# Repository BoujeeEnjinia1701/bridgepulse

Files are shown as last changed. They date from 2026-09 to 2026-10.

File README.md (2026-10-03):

# BridgePulse

     

**Area:** Smart Cities · **TRL:** 3 of 9 (proof of concept on paper) · **Value-engineering target:** $250 USD for the BridgePulse-specific parts (a hypothetical control target, not a limit) · **Difficulty:** 3 of 5

A vibration and strain monitor for small bridges and footbridges that tracks natural frequency and strain over time to flag changes that need inspection.

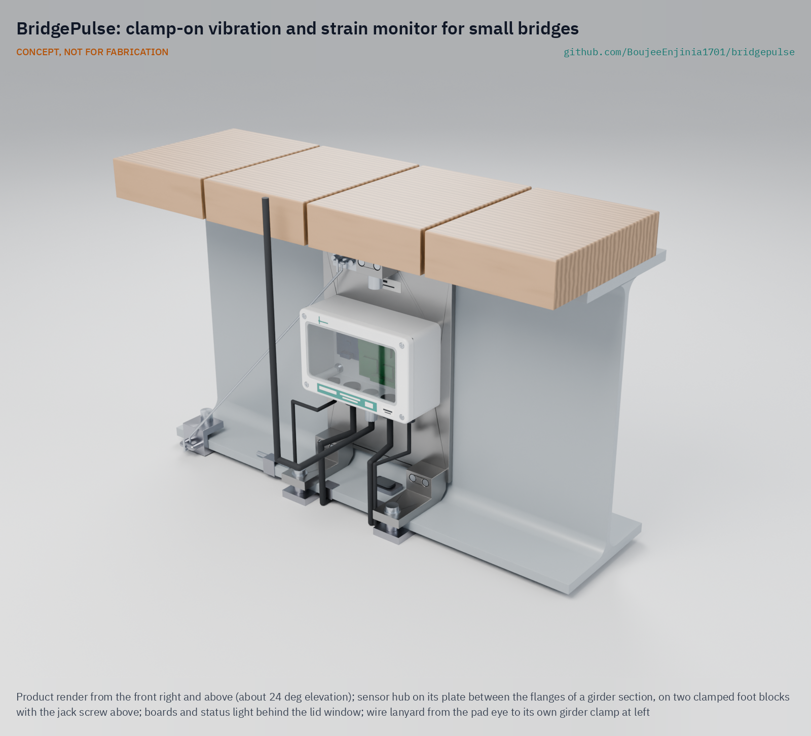
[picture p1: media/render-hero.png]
BridgePulse: clamp-on vibration and strain monitor for small bridges, product render


[Exploded render](media/render-exploded.png) · [Detail render](media/render-detail.png) · [Interactive 3D model](media/viewer.html) · [Concept blueprint (PDF)](media/concept-blueprint.pdf) · [General arrangement BRP-DWG-001 (PDF)](cad/drawings/BRP-DWG-001.pdf) · [Calculations BRP-CAL-001](docs/04-calcs/01-sizing.md) · [Prototype build plan BRP-BLD-001](docs/05-build-plan.md) · [Design decisions BRP-DEC-001](docs/06-design-decisions.md) · [Review note](docs/REVIEW.md)

## Concept rationale

A bridge's natural frequencies depend on its stiffness, so a loss of stiffness from corrosion, cracking or a failing bearing shows up as a small, lasting drop in frequency, and a change in how load is carried shows up in strain. The difficulty is that temperature moves the frequencies too. The Z24 bridge study showed that a model of frequency against temperature, learned from the healthy bridge, can separate the two ([Peeters and De Roeck, 2001](https://doi.org/10.1002/1096-9845%28200102%2930:2%3C149::AID-EQE1%3E3.0.CO;2-Z)). BridgePulse applies that idea with one clamp-on sensor hub at midspan, hourly 10 minute records and a learned temperature band, so the owner's engineer gets a reason to inspect sooner rather than a stream of raw data.

It is open and garage-buildable because the owners of small bridges, such as towns, counties, park services and rural access programs, are the ones least able to pay for commercial monitoring. Low-noise MEMS accelerometers now cost tens of dollars, the hub clamps on without drilling, and power, radio and data handling come from the lab's shared FieldNode, TwinKit and CityTwin projects. Open design files and open methods also let engineers check how a flag was raised, which matters more than the hardware.

## Burning platform

Bridge stock is large, aging and inspected at long intervals. In the United States, 41,685 of 624,193 bridges (6.7 %) were in poor condition in 2025 ([FHWA](https://www.fhwa.dot.gov/bridge/nbi/no10/condition25.cfm)), and routine inspections may be 24, 48 or, under a risk-based method, up to 72 months apart ([23 CFR 650.311](https://www.ecfr.gov/current/title-23/chapter-I/subchapter-G/part-650/subpart-C/section-650.311)). In Japan, about 37 % of roughly 730,000 road bridges were 50 years old or more in 2023, rising to about 54 % by 2030 ([MLIT](https://www.mlit.go.jp/sogoseisaku/maintenance/02research/02_01.html)).

Findings also have to reach someone who acts. The Fern Hollow Bridge in Pittsburgh collapsed in January 2022 after the city failed to act on repeated maintenance recommendations in its inspection reports ([NTSB](https://www.ntsb.gov/investigations/Pages/HWY22MH003.aspx)). A monitor cannot replace inspection or funding, but a clear, early signal on a specific bridge can help put limited inspection time where it is needed.

## Where it could be used

### By industry

| Industry | Use |
| --- | --- |
| Municipal and county public works | Watching footbridges and short road bridges between routine inspections, and after floods or vehicle strikes |
| Parks, trails and recreation | Timber and steel trail bridges that see few inspections and many visitors |
| Rural access and humanitarian programs | Checking a sample of trail bridges built years earlier without a site visit to each one |
| Rail and transit operators | Station footbridges and pedestrian overbridges |
| Forestry and mining | Haul road and forestry bridges carrying heavy, irregular loads |
| Universities and training | An open platform for teaching and research in vibration-based structural health monitoring |

### By country or region

| Country or region | Why it matters there |
| --- | --- |
| United States | 41,685 bridges were rated poor in 2025 ([FHWA](https://www.fhwa.dot.gov/bridge/nbi/no10/condition25.cfm)); many are small, locally owned structures. |
| Great Britain | 2,928 council-maintained road bridges were substandard in 2023, with a £6.8 billion backlog; councils also report growing concern about flooding and scour ([RAC Foundation](https://www.racfoundation.org/media-centre/changing-weather-patterns-worrying-bridge-engineer)). |
| Japan | The share of road bridges 50 years old or more is set to rise from about 37 % to about 54 % between 2023 and 2030 ([MLIT](https://www.mlit.go.jp/sogoseisaku/maintenance/02research/02_01.html)). |
| Nicaragua and Central America | Floods cut labor income by about 18 % in villages without a footbridge, and new bridges removed that loss ([Brooks and Donovan, 2020](https://doi.org/10.3982/ECTA15828)); keeping existing footbridges in service protects that gain. |
| Rwanda and East Africa | Trail bridge programs report a preliminary annual return of about 49 % on trail bridges in Rwanda and similar settings ([Fika, formerly Bridges to Prosperity](https://fika.org/measuring-roi-for-trail-bridges/)), so a growing stock of footbridges will need low-cost ways to check them. |

## What sparked the idea

The idea traces back to the Silver Bridge between Point Pleasant, West Virginia, and Ohio, which fell on December 15, 1967, killing 46 people, after a single eyebar in a suspension chain fractured from a defect only 2.5 mm (0.1 in) deep. The disaster led to the National Bridge Inspection Standards of April 27, 1971, which set inspections at least once every two years by trained inspectors ([FHWA](https://highways.dot.gov/highway-history/general-highway-history/happy-50th-anniversary-national-bridge-inspection-standards)). That calendar-based regime is still the backbone of bridge safety, but it leaves long gaps in which nobody watches a structure, and it is weakest for the small footbridges and local spans that get the least attention. BridgePulse starts from that gap: a low-cost record of how a small bridge behaves between inspections, fed to the owner's engineer and to CityTwin, so that a change can prompt a visit sooner than the calendar would.

## Problem

Many small bridges are inspected rarely, and deterioration is found late. Their owners seldom have the budget for commercial monitoring, so there is no record of how a bridge behaves between inspections. See the [problem statement](docs/01-problem.md).

## Concept

A vibration and strain monitor for small bridges and footbridges that tracks natural frequency and strain over time to flag changes that need inspection. A sensor hub fixed between the flanges of a girder at midspan records 10 minutes of acceleration, strain and temperature every hour, extracts the natural frequencies and strain statistics on board, and sends about 36 bytes per hour (11 bytes where the radio data rate allows no more) through a FieldNode core over LoRaWAN to TwinKit or CityTwin. A temperature-compensated baseline, learned over weeks, flags lasting changes to the owner's engineer.

The TRL 3 calculations ([BRP-CAL-001](docs/04-calcs/01-sizing.md)) give 16.9 mW average draw, 0.0153 Hz spectral resolution per record, 1.39 GB of raw records per month kept on site, and $275 of BridgePulse-specific parts ($401 with the FieldNode core, which is costed in its own repo), $25 over the $250 value-engineering target since the parts that make the design buildable, the lanyard anchor and the installation banding were added. With the lanyard's girder clamp the monitor puts 3.58 kg on the girder. On the 7 m example footbridge the first mode is 23.9 Hz and the instrument can track it to about 0.05 % an hour, but the mass of people crossing lowers it by up to 6 %. The hub therefore gates out the time when someone is on the span; in simulation that brings the hourly scatter to 0.015 % or less, inside the 0.2 % target, which remains at risk until recorded data confirm it. The 1 % change detection cannot be verified on paper. See the [requirements](docs/03-requirements.md) for what is and is not met.

Full design precis: [docs/02-concept.md](docs/02-concept.md)

## Key components

- Sensor hub: IP67 die-cast aluminium enclosure on an aluminium plate that lies on the girder web, clamped to the bottom flange and jacked against the top flange, no drilling
- Low-noise 3-axis MEMS accelerometer (ADXL355 class)
- Signal board with 24-bit bridge ADC, RP2040 class microcontroller, RS-485 link and industrial microSD card
- Two strain gauge half-bridges with temperature-compensating dummy gauges
- Two TMP1826 class temperature probes in stainless sheaths (steel and air)
- Shielded sensor cables with M12 connectors
- FieldNode core (shared lab component): 6 W panel, LiFePO4 cell, MPPT charger and LoRaWAN radio

The working bill of materials is in [bom/bom.csv](bom/bom.csv).

## Building the prototype

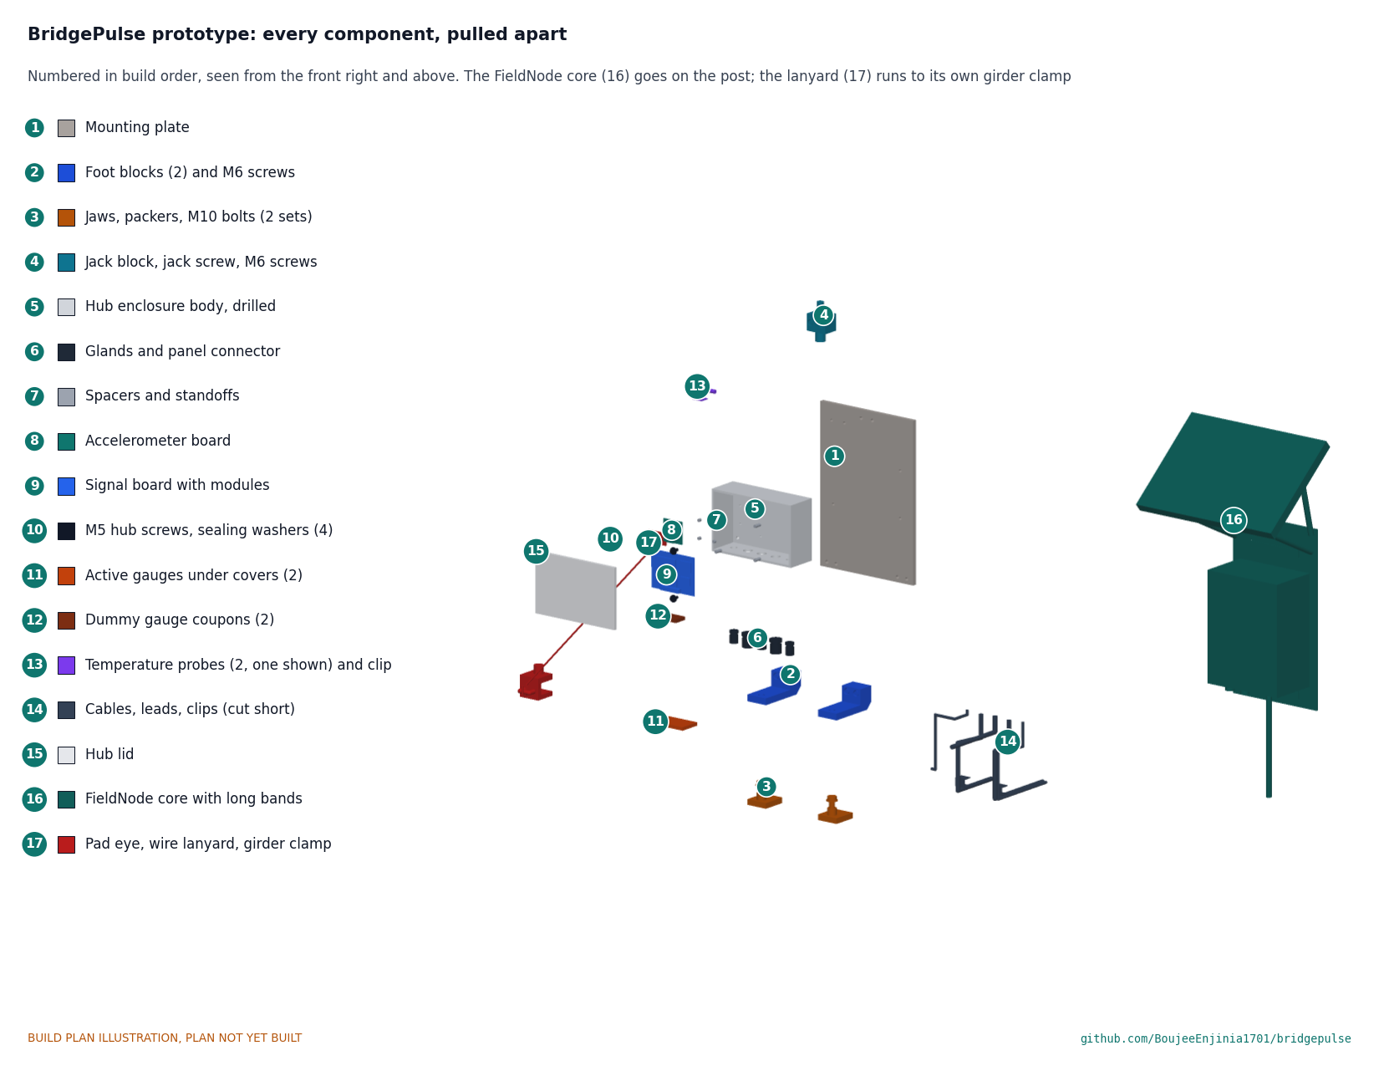
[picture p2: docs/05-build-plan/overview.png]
BridgePulse prototype: every component, pulled apart and numbered in build order


The [prototype build plan](docs/05-build-plan.md) (BRP-BLD-001) shows, component by component and step by step in pictures drawn from the model, how to build the first proof-of-concept monitor on a bench rig of two girder offcuts and a handrail post stub. Seven parts are made in a small workshop from aluminium and steel bar and plate; the rest are bought, and the FieldNode core is built to its own plan. Making the design buildable kept the plate clear of the girder's root fillets, clamped it to the flange with foot blocks and steel jaws, and gave every sensor and cable a fixing that needs no drilling (BRP-DDR-004). A stainless wire lanyard runs from a pad eye on the plate to a second, independent girder clamp on the bottom flange. It is a plan, not yet built; the decisions behind it are in the [design decisions register](docs/06-design-decisions.md).

## Safety

> A research prototype; it supports but never replaces inspection by qualified engineers, and a "no change" result never means a bridge is safe. Install only with the asset owner's permission, by trained crews, with fall protection, a rescue plan for work over water and traffic management as local rules require. Test old paint for lead before removing any for strain gauges. The FieldNode core contains a lithium iron phosphate cell; use its protected, fused pack. Nothing is drilled or welded into the structure, and the mounting plate carries a secondary wire lanyard to an independent girder clamp.

## Repository layout

| Folder | Contents |
| --- | --- |
| `docs/` | Problem, concept, requirements, calculations and design decisions |
| `cad/src/` | build123d Python source, the source of truth for all geometry |
| `cad/step/`, `cad/stl/` | Exported models for FreeCAD, other CAD tools and printing |
| `cad/drawings/` | 2D sketches and dimensioned drawings |
| `bom/` | Bill of materials |
| `electronics/` | KiCad schematics and PCB layouts |
| `firmware/` | Microcontroller code |
| `media/` | Renders, perspectives and photos |
| `build-log/` | Dated prototyping notes |

## Documentation

Controlled documents follow the portfolio [documentation standard](.kit/STANDARDS.md). Each carries a document ID (BRP-PRC-001 for the precis), a version and a revision history. Branded PDFs are built with `python .kit/render.py` and attached to GitHub Releases when a document is tagged, for example `BRP-PRC-001/v1.0`.

## Credits

Designed by Amish Chadha. See [CONTRIBUTORS.md](CONTRIBUTORS.md) for roles. To cite this design, use [CITATION.cff](CITATION.cff) (GitHub shows it as "Cite this repository").

AI assistance (Claude) was used to accelerate concept renders, prototype documentation and first-pass sizing calculations. Design direction and all decisions are Amish Chadha's, recorded in this repository's decision records (`docs/decisions/`).

## Licenses

- **Hardware** (CAD, drawings, BOM, electronics): [CERN-OHL-S v2](LICENSE)
- **Software** (firmware, scripts, notebooks): [MIT](LICENSE-SOFTWARE)

A project of the [Design Molecule](https://designmolecule.com) lab.

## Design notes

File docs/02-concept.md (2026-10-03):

---
doc_id: BRP-PRC-001
title: BridgePulse design precis
project: BridgePulse
doc_type: Design precis
version: "0.8"
status: Draft
date: '2026-10-02'
author: Amish Chadha
license: CERN-OHL-S-2.0
revisions:
- version: "0.1"
  date: '2026-09-25'
  author: Amish Chadha
  change: Initial scaffold
- version: "0.2"
  date: '2026-09-25'
  author: Amish Chadha
  change: Concept for TRL 2; architecture, first-order numbers, safety and open questions
- version: "0.3"
  date: '2026-09-25'
  author: Amish Chadha
  change: TRL 3 update; design choices adopted for TRL 3 per BRP-DDR-001; numbers from BRP-CAL-001; jacked mounting plate, switched-rail power, curve-fit frequency estimate, mass-loading finding
- version: "0.4"
  date: '2026-09-25'
  author: Amish Chadha
  change: Recommendations accepted by Amish (DDR-002); load gating and TwinKit load regression, 11-byte reduced summary, TMP1826 class probes; numbers from BRP-CAL-001 v0.2
- version: "0.5"
  date: '2026-09-30'
  author: Amish Chadha
  change: Design made constructable (BRP-DDR-004); mounting, hub penetrations, probe fixing and FieldNode post interface described as buildable; numbers from BRP-CAL-001 v0.3
- version: "0.6"
  date: '2026-10-01'
  author: Amish Chadha
  change: Budget treated as a value-engineering target; cost wording only, no number changed
- version: "0.7"
  date: '2026-10-02'
  author: Amish Chadha
  change: "Decisions of 2026-10-02 carried in: shared FieldNode pinout with Modbus RTU, lanyard to an independent girder clamp, crimped banding on installed units, data ownership"
- version: "0.8"
  date: '2026-10-02'
  author: Amish Chadha
  change: "Approved follow-ups carried out: lanyard pad eye, wire and girder clamp in the model and the BOM, installation banding priced; mass 3.58 kg on the girder and cost $275.00 from BRP-CAL-001 v0.6"
---

# BridgePulse design precis

## Summary

BridgePulse is a clamp-on monitor for small bridges and footbridges. A sensor hub fixed to a girder at midspan records ambient vibration, strain and temperature for 10 minutes every hour, works out the bridge's natural frequencies and strain statistics on board, and sends a short summary through a FieldNode core over LoRaWAN to TwinKit or CityTwin. Over weeks the system learns how the frequencies move with temperature; a sustained shift outside that band is flagged to the bridge owner's engineer as a reason to inspect sooner. It is a research prototype that supports inspection, never a safety rating.

The TRL 3 calculations (BRP-CAL-001) give 16.9 mW average draw at the FieldNode port, a 36-byte hourly uplink, 1.39 GB per month of raw records kept on a microSD card (22 months on 32 GB), and $275 of BridgePulse-specific parts ($401 with the FieldNode core), $25 over the $250 value-engineering target since the parts that make the design buildable, the lanyard anchor and the installation banding were added (see the value engineering section of BRP-DEC-001). On the 7 m example footbridge the first mode is 23.9 Hz and the instrument can track it to 0.05 % an hour, but walkers' own mass lowers it by up to 6 % while they cross. The hub therefore gates out the time when someone is on the span; in simulation this brings the hourly scatter to 0.015 % or less (R2 at risk until recorded data confirm it; R3 not verifiable at TRL 3).

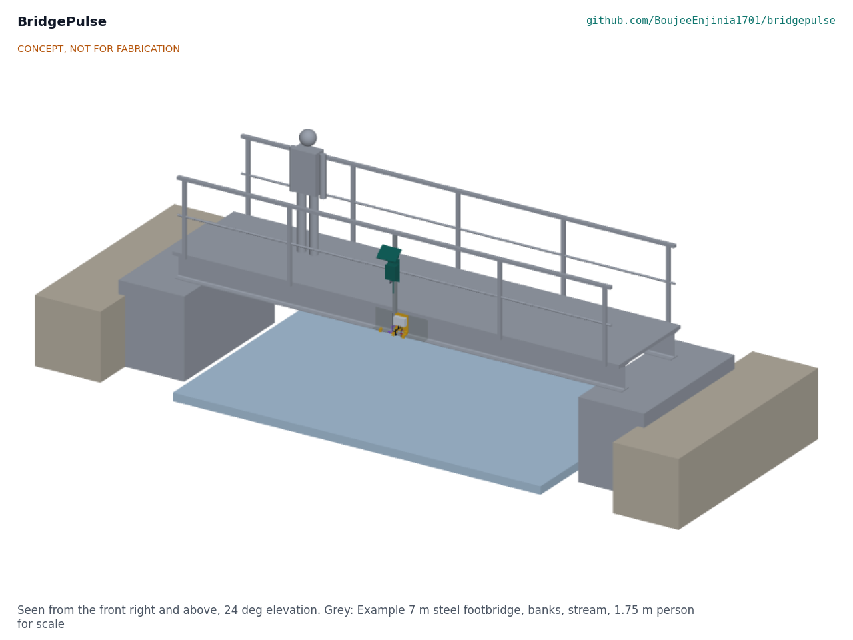
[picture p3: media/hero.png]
Figure 1. BridgePulse on an example 7 m steel footbridge


*Figure 1. Concept render. The monitor clusters at midspan: sensor hub between the flanges of the south girder, FieldNode core on the handrail post. Grey parts are the existing bridge and a 1.75 m person for scale.*

## How it works

1. **Sense.** A low-noise 3-axis MEMS accelerometer, fixed inside the hub to the enclosure base, picks up the bridge's response to wind, footfall and traffic. The hub is screwed to an aluminium plate that lies against the web, stands on two foot blocks clamped to the bottom flange and is wedged against the top flange by a jack screw, so that its own mounting resonance (135 to 271 Hz) is well above the measured band. A stainless wire lanyard from a pad eye on the plate to a second, independent girder clamp on the bottom flange holds everything if the mount ever lets go. Two strain gauge half-bridges under the bottom flanges of both girders at midspan measure bending strain. Two temperature probes measure the steel and the shaded air under the deck.
2. **Record.** Once an hour the FieldNode core switches on the 5 V rail of its sensor port. The hub boots, warms the gauges for 20 s and samples for 600 s: acceleration at 250 Hz on three axes, strain at 20 Hz on two channels, temperature once a minute. The raw record goes to an industrial microSD card so an engineer can download it later.
3. **Reduce.** The hub first finds each crossing from the strain step and gates out that stretch of the record, with 0.25 s either side and tapered edges, so that the frequency is estimated only while nobody's mass is on the span (BRP-DDR-002). It then reads the record back from the card one axis at a time, computes averaged spectra (Welch method, 65.5 s Hann segments with 50 % overlap), and estimates the frequencies of the first modes below 60 Hz by fitting a single-degree-of-freedom spectrum around each peak. A fit is accepted only if the peak stands 10 dB above the fitted noise and the damping is plausible; otherwise the hour is sent as "no clear peak", never as a shift. It also computes peak amplitudes, RMS acceleration, and the strain minimum, maximum and mean on each channel.
4. **Send.** The 36-byte summary passes over RS-485 on the M12 cable to the FieldNode core, which sends it as one LoRaWAN uplink; the rail is then switched off until the next hour. Where the data rate in use allows only 11 bytes (US915 DR0, AS923 DR2 with dwell time), the hub sends an 11-byte reduced summary instead: first frequency, its amplitude, the two strain means, steel temperature and a status byte with the gated seconds (BRP-CAL-001, G).
5. **Learn and flag.** TwinKit stores the series and fits frequency against steel temperature over a baseline period, following the approach of the Z24 bridge study ([Peeters and De Roeck, 2001](https://doi.org/10.1002/1096-9845%28200102%2930:2%3C149::AID-EQE1%3E3.0.CO;2-Z)). A frequency that stays outside the confidence band for a set period, or a step in the strain baseline, raises a flag to the owner's engineer. As a second line against any load effect the gate misses, TwinKit also regresses each hourly frequency on a load indicator (strain mean, RMS acceleration) sent in the summary. TwinKit can show the measured frequency next to the value calculated from the bridge model.
6. **Act.** The engineer decides whether to inspect. The public CityTwin view shows only that the bridge is monitored and when data last arrived.

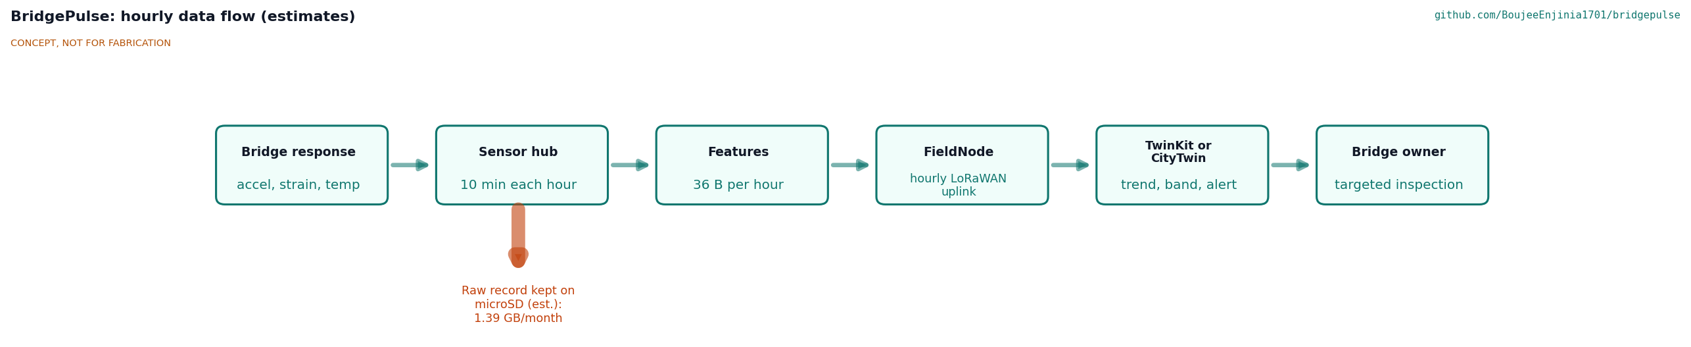
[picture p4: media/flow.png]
Figure 2. Hourly data flow


*Figure 2. Hourly data flow. Values are estimates from BRP-CAL-001.*

## Main components

Numbers match the exploded view (Figure 3) and `bom/bom.csv`. The general arrangement is drawing BRP-DWG-001.

| No. | Component | Role |
| --- | --- | --- |
| 1 | Sensor hub enclosure, die-cast aluminium, IP67, 170 × 64 × 110 mm | Stiff, sealed housing whose base is screwed flat to the plate, coupling the accelerometer to it; two M16 gauge glands, two M12 probe glands and an M12 panel connector underneath |
| 2 | Accelerometer board, ADXL355 class | 3-axis, 22.5 µg/√Hz noise density, 200 µA in measurement mode ([Analog Devices](https://www.analog.com/en/products/adxl355.html)) |
| 3 | Signal board: 24-bit bridge ADC (ADS1220 class), RP2040 class microcontroller, 5 V to 3.3 V buck converter, RS-485 transceiver, microSD socket, gauge excitation switch | Sampling, spectra, features, raw storage, link to FieldNode |
| 4 | Mounting plate, 200 × 291 × 8 mm 6061 aluminium, on two foot blocks clamped to the bottom flange tip by steel jaws, with an M12 jack screw to the top flange | Holds the hub between the flanges, inside the girder outline, clear of the root fillets; no drilling |
| 5 | Strain gauge half-bridges (2): each an active 350 Ω foil gauge on the flange plus a dummy gauge on an unstrained coupon of the same steel, with protective coating and cover | Bending strain at midspan of each girder, temperature-compensated |
| 6 | Temperature probes (2), TMP1826 class 1-Wire sensor potted in a stainless sheath, ±0.3 °C from −40 to +105 °C ([Texas Instruments](https://www.ti.com/product/TMP1826)) | Steel and shaded air temperature for frequency compensation |
| 7 | Sensor cables and M12 connectors | Gauges to hub, hub to FieldNode |
| 8 | FieldNode core: IP65 enclosure, 6 W panel as sun hood, LiFePO4 cell, MPPT charger, LoRaWAN radio, pole clamps | Power, radio and mounting shared across the lab's outdoor projects |
| 9 | microSD card, industrial grade, 32 GB | Raw records on site (in item 3; not shown separately) |

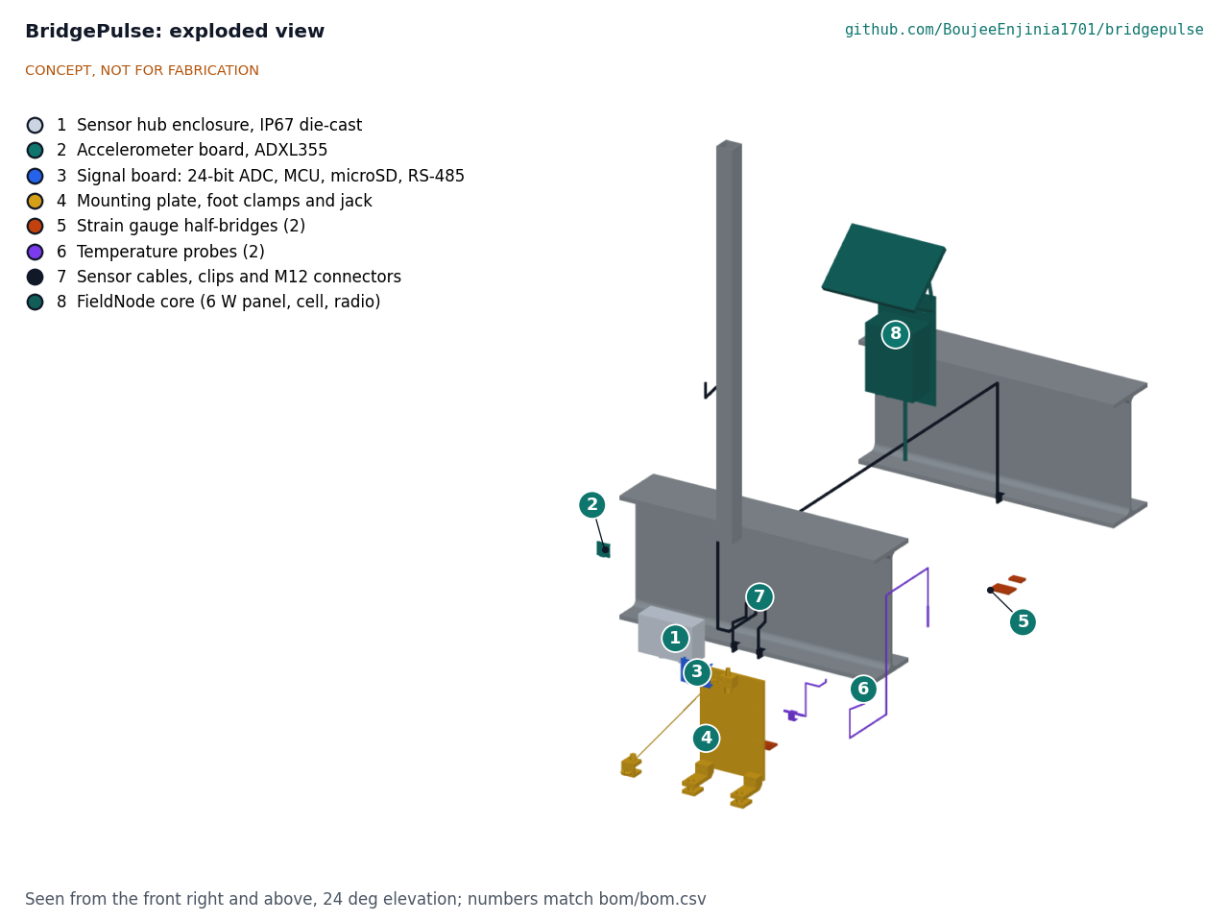
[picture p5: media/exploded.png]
Figure 3. Exploded view


*Figure 3. Exploded view with BOM numbers. The girder and post are existing structure.*

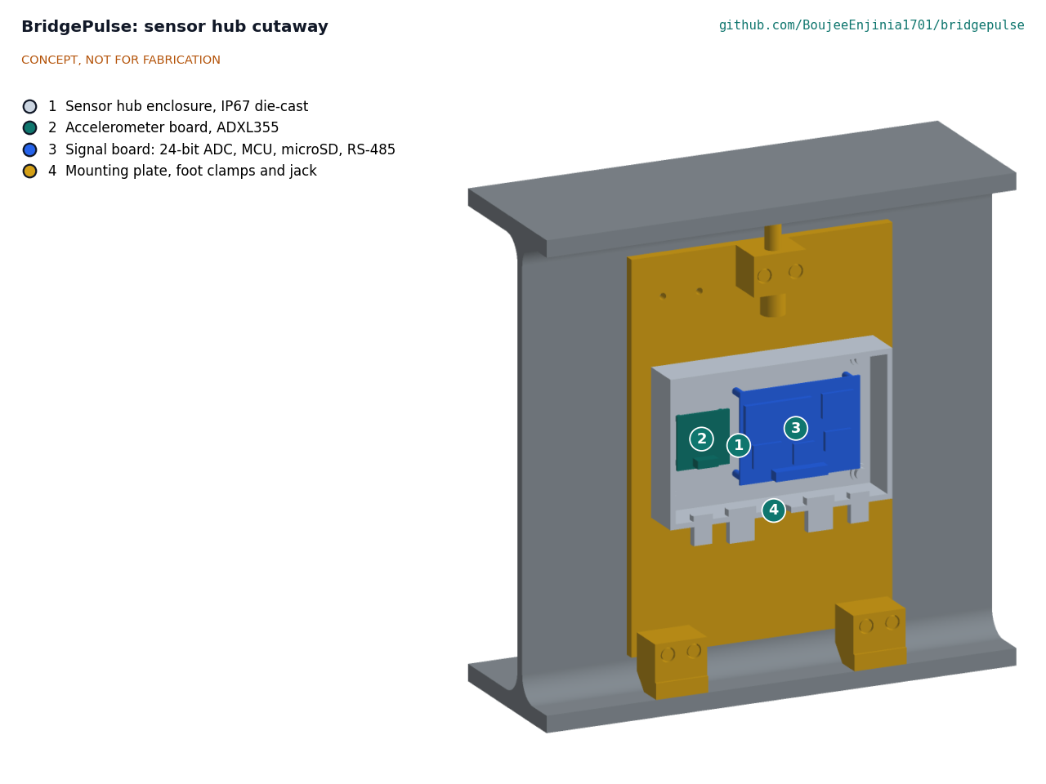
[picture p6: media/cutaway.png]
Figure 4. Sensor hub cutaway


*Figure 4. Cutaway of the sensor hub on its plate, between the flanges of the south girder. The accelerometer board is fixed to the base of the enclosure on the plate side so it moves with the girder.*

## Key numbers (BRP-CAL-001)

All values come from BRP-CAL-001 v0.3, which states its assumptions; they are calculations, not measurements.

### Example bridge

- 6.4 m between bearings; two IPE 360 class girders; EI = 6.52 × 10⁷ N·m²; 167 kg/m. First vertical mode **23.9 Hz**, second 96 Hz (outside the band); modal mass 535 kg.
- A lasting 1 % drop in frequency is a 2 % loss of bending stiffness. The steel modulus alone moves the frequency by about 1 % between −20 and +50 °C, so temperature compensation is needed.
- **People change the frequency of a light footbridge.** One 75 kg walker at midspan lowers f₁ by 6.3 %; a crowd of one person per square meter lowers it by 22.7 %. On a road bridge with 20 t of modal mass one walker moves it by 0.19 %.

### Measurement

- Bin width 0.0153 Hz; 17 averaged segments per record; sensor noise 2.8 µg in one bin. The mode's 0.48 Hz half-power bandwidth, not the bin width, limits precision.
- Simulated scatter of the hourly estimate from sensor noise: 0.053 % at 100 µg RMS of modal response with a curve fit, against 0.265 % with simple peak picking; a clear peak needs about 30 µg RMS. One walker gives about 29 mg RMS near midspan, so footfall is ample excitation.
- Because the walkers who excite the bridge also load it, an estimate over the whole record is biased by about −5 % and scatters by 1.5 to 3.1 % in a time-varying simulation. With load gating the bias is −0.03 to −0.04 % and the scatter 0.015 % or less (1 to 20 crossings in the record), inside R2's 0.2 %; 4.4 % of the record is gated out at 5 crossings. With one crossing on a quiet day, 20 % of records give no clear peak.
- Detecting a 1 % shift within 14 days with one false flag per year needs a daily residual of 0.75 % or less after temperature and load compensation.
- Strain: 1.65 µV per µε; 0.09 µε RMS resolution at the assumed ADC noise; a 5 kN/m² crowd gives 106 µε and one walker 3.2 µε, so strain is a usable load indicator.

### Power, data and mounting

| Quantity | Value |
| --- | --- |
| Power while recording, at the FieldNode port | 92.9 mW |
| Average, with the rail off between records | **16.9 mW** (0.41 Wh per day; 17 % of FieldNode's 100 mW allowance) |
| Raw data | 1.90 MB per hour; 1.39 GB per month; 22 months on 32 GB |
| Uplink | 36 bytes hourly, 329 ms at SF9; 11-byte reduced summary where the data rate allows only 11 bytes, 371 ms at SF10 |
| Mass on the girder | 3.58 kg (hub 0.99 kg, plate 1.25 kg, foot clamps, jack and fixings 0.97 kg, lanyard girder clamp, pad eye and wire 0.37 kg); FieldNode core 2.41 kg |
| Mounting resonance of the hub | 135 to 271 Hz (TRL 2 arrangement about 75 Hz) |
| Lanyard | Peak 1.20 kN if the mount lets go with 25 mm of slack (dynamic factor 38); girder clamp rated 100 kg or more working load |
| Depth below the soffit | 10 mm at most (limit 15 mm) |

### Cost

Value-engineering target $250 (a hypothetical control target, not a limit), which under BRP-DDR-001 D1 covers the BridgePulse-specific parts. Estimated cost of the constructable design: $275.00 ($25.00 over the target); with the FieldNode core ($126.00, costed in its own repo) the complete monitor is $401.00. The TMP1826 class probes added $4.00, the parts that make the design buildable (BRP-DDR-004) $4.00, the lanyard anchor decided on 2026-10-02 $19.00 and the stainless banding for installed units $4.00. Savings worth trying are listed in the value engineering section of the design decisions register (BRP-DEC-001). The bridge, installation labor, access equipment, traffic management and paint testing are not included.

## Key design choices

Each is decided by Amish, 2026-09-25: go with recommendation (BRP-DDR-001, BRP-DDR-002).

1. **Ambient vibration only.** No shaker or impact hammer; wind, footfall and traffic excite the bridge. Footfall is ample on a used footbridge; very quiet bridges remain a risk.
2. **Separate hub on the girder, FieldNode on a post.** The accelerometer must be on the structure, while the panel needs sun and the radio a clear view.
3. **Hourly 10 minute windows rather than continuous recording.** 16.9 mW against about 93 mW, with 24 frequency estimates a day.
4. **Temperature-compensated trend, not fixed limits.** A frequency band learned from the bridge's own baseline, with at least four weeks of data before any flag and a full year to cover seasons. BRP-CAL-001 shows it must model load on the deck as well as temperature.
5. **Foil gauge half-bridges with a dummy on a coupon.** Cheaper and easier to fit than weldable or vibrating-wire gauges, at the cost of long-term drift, to be checked early.
6. **One accelerometer at midspan.** Enough for the first vertical and torsional modes.
7. **Built on FieldNode, TwinKit and CityTwin.** The hub connects to one FieldNode M12 5-pin port, using its switched rail at 5 V and RS-485 on two signal pins. This follows FieldNode's candidate pinout, adopted on 2026-10-02 as the shared standard with Modbus RTU as the protocol (pin 1 switched 5 V rail, pins 2 and 4 RS-485 A and B, pin 3 ground, pin 5 analog); FieldNode is asked to record it as decided (BRP-DEC-001).
8. **Engineer-only alerts.** Flags go to the owner's engineer; the public CityTwin view shows only monitoring status.
9. **An RP2040 class microcontroller in the hub,** which post-processes each record from the card because the three axes do not fit in its RAM at once.
10. **Load gating, backed by a load regression.** The hub gates out the time when people are on the span; TwinKit regresses what remains on a load indicator. R2 stays at 0.2 % until recorded data show whether this works (BRP-DDR-002).
11. **An 11-byte reduced summary** wherever the data rate in use limits the payload to 11 bytes (BRP-DDR-002).
12. **TMP1826 class probes with an ice-point check,** so the ±0.5 °C of R5 holds down to −20 °C (BRP-DDR-002).

## Safety

> **Safety:** BridgePulse is a research prototype. It supports but never replaces inspection by qualified engineers, and a "no change" result never means a bridge is safe. Owners must not defer or skip inspections because a monitor is fitted.

> **Safety:** Installation is work at height, often over water or traffic. Install only with the owner's written permission, with trained crews, fall protection, a rescue plan for work over water, and traffic management as local rules require. Never work alone.

> **Safety:** Old steel bridges may be coated with lead or other hazardous paint. Test before removing any paint for strain gauges; if lead is present, use a trained contractor and local abatement rules. Gauge adhesives and coatings are chemicals: follow their safety data sheets, use gloves and eye protection and ventilate.

> **Safety:** The FieldNode core contains a lithium iron phosphate cell. Use the fused, protected pack and cold-charge lockout specified by FieldNode and never mount a damaged pack.

> **Safety:** Nothing may be drilled, welded or cut into the structure. The jack screw preload and the clamps must be checked so they cannot loosen and fall onto people, vehicles or boats below; use a secondary 3 mm stainless wire lanyard from the pad eye on the plate to a second, independent load-rated girder clamp on the bottom flange, at least 150 mm along the span from the foot clamps, fitted with no more than 25 mm of slack. Isolate the aluminium plate from the steel so galvanic corrosion cannot loosen it over time.

> **Safety:** Fit tamper-resistant fasteners on the post-mounted FieldNode so the public cannot pull it off or hang from it: stainless banding with a one-way crimped buckle on installed units (worm-drive bands only on the bench). Keep cables out of reach from the deck.

## Open questions

- [ ] 1. Does load gating hold on recorded footfall, with real walkers, several modes and wind, as it does in simulation? (BRP-CAL-001, B; TRL 4, on hold)
- [ ] 2. How much do frequencies move with temperature on small steel, concrete and timber bridges, and can a model trained on four weeks of data hold across seasons to a daily residual of 0.75 %?
- [ ] 3. What drift do foil strain gauges show outdoors over a year with the proposed coating?
- [x] 4. Which FieldNode port pinout and protocol will be agreed (BRP-DDR-001, O1)? Decided 2026-10-02: FieldNode's candidate pinout with Modbus RTU over RS-485, as the shared standard.
- [ ] 5. What is the alert rule (size of shift, duration) and who receives it?
- [ ] 6. Does the potted TMP1826 class probe hold its datasheet accuracy after sealing, at the ice point and in CalRig? (TRL 4, on hold)
- [x] 7. Who owns the data, and what is published openly through CityTwin (BRP-DDR-001, O3)? Decided 2026-10-02: the bridge owner owns all data; only monitoring status is published, and research datasets only with the owner's written consent, under an open licence such as CC BY 4.0.

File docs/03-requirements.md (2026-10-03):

---
doc_id: BRP-REQ-001
title: BridgePulse requirements
project: BridgePulse
doc_type: Requirements
version: "0.8"
status: Draft
date: '2026-10-02'
author: Amish Chadha
license: CERN-OHL-S-2.0
revisions:
- version: "0.1"
  date: '2026-09-25'
  author: Amish Chadha
  change: Initial scaffold
- version: "0.2"
  date: '2026-09-25'
  author: Amish Chadha
  change: First measurable requirements for TRL 2, with status against the concept estimates
- version: "0.3"
  date: '2026-09-25'
  author: Amish Chadha
  change: R12 redefined per BRP-DDR-001 D1; status of every requirement from BRP-CAL-001; interface assumptions for FieldNode
- version: "0.4"
  date: '2026-09-25'
  author: Amish Chadha
  change: Recommendations accepted by Amish (DDR-002); R2 method (load gating), R5 verification, R7 restated with an 11-byte reduced summary; status from BRP-CAL-001 v0.2
- version: "0.5"
  date: '2026-09-30'
  author: Amish Chadha
  change: Status from BRP-CAL-001 v0.3 after the design for construction (BRP-DDR-004); R12 now not met by $2.00; no target changed
- version: "0.6"
  date: '2026-10-01'
  author: Amish Chadha
  change: Budget treated as a value-engineering target; R12 status reworded, no number changed
- version: "0.7"
  date: '2026-10-02'
  author: Amish Chadha
  change: "R9 states the tamper-resistant fixing chosen on 2026-10-02 (crimped stainless banding); FieldNode pinout recorded as decided; no status changed"
- version: "0.8"
  date: '2026-10-02'
  author: Amish Chadha
  change: "Status from BRP-CAL-001 v0.6 after the approved decisions were carried into the design: R12 now $25.00 over the value-engineering target (lanyard anchor and installation banding); R9 still met on paper; no target changed"
---

# BridgePulse requirements

These are first-pass requirements for the concept. Targets are proposals for review, not yet validated with bridge owners or inspectors, and will be revised after co-design sessions (see BRP-PRB-001). Status is now judged by calculation in BRP-CAL-001 against the parametric model and the priced BOM; "met on paper" is not a verification by test.

**Reference installation.** A steel or concrete footbridge or short-span road bridge of 5 to 30 m span, monitored at midspan, in a climate from −20 to +50 °C, with LoRaWAN coverage and no mains power. The worked example is the 7 m steel footbridge in BRP-PRC-001.

**Changes in v0.3.** R12 is redefined to cost the BridgePulse-specific parts, with the FieldNode core costed in its own repo and the complete cost stated beside it (BRP-DDR-001, D1; decided by Amish, 2026-09-25: go with recommendation). No other target changes.

**Changes in v0.5 (BRP-DDR-004).** No target changes. With the design made buildable, BRP-CAL-001 v0.3 finds R12 over the value-engineering target by $2.00; R9 stays met on paper (10 mm below the soffit, the bolts now ending inside the clamp jaws).

**Changes in v0.8 (decisions of 2026-10-02 carried into the design).** No target changes. The lanyard's independent girder clamp, pad eye and wire and the stainless banding for installed units are now in the model and the BOM. BRP-CAL-001 v0.6 finds R12 over the value-engineering target by $25.00 (was $2.00); R9 stays met on paper, the girder clamp's lower jaw being 8 mm below the soffit.

**Changes in v0.4 (BRP-DDR-002).** R2 keeps its target; its method now gates out the time when people are on the span, backed by a load regression in TwinKit, and is to be checked on recorded data before any change to the target. R5 keeps its target; verification adds an ice-point check, and the probe is now TMP1826 class. R7 is restated so that an 11-byte reduced summary is used wherever the data rate in use limits the payload to 11 bytes. Statuses follow BRP-CAL-001 v0.2.

Table 1. Requirements and status at TRL 3 (BRP-CAL-001 v0.6, Table 5).

| ID | Requirement | Target | Verification | Status at TRL 3 |
| --- | --- | --- | --- | --- |
| R1 | Measure bridge acceleration | 3 axes; noise density 25 µg/√Hz or less; band 0.5 to 60 Hz | Datasheet; later bench noise test | Met by design (22.5 µg/√Hz; 62.5 Hz filter corner) |
| R2 | Track natural frequencies | Every mode with a clear peak below 60 Hz, at least the first vertical mode; bin width 0.02 Hz or less per hourly record; repeatability 0.2 % (1σ) or better over a day of steady temperature | Spectral and load-gating simulation (BRP-CAL-001, B); then recorded data | At risk: with the time when people are on the span gated out, 0.015 % or less in simulation (1 to 20 crossings per record); ungated, walker mass gives 1.5 to 3.1 % |
| R3 | Flag structural change | Flag a sustained shift of 1 % or more in a tracked frequency, after temperature compensation, within 14 days; one false flag per bridge per year or fewer | Detection statistics (BRP-CAL-001, C); then public benchmark data and a field baseline | Not verifiable at TRL 3: needs a daily residual of 0.75 % or less after temperature and load compensation |
| R4 | Measure strain | 2 channels; range ±1,000 µε; resolution 2 µε or better; drift 5 µε per month or less after temperature compensation | ADC noise calculation; later outdoor drift test | Not verifiable at TRL 3 for drift; resolution (0.09 µε RMS) and range met on paper |
| R5 | Measure temperature | Steel surface and shaded air; ±0.5 °C or better, checked against a reference | Datasheet; ice-point check at 0 °C and CalRig chamber check | Met on paper: TMP1826 class, ±0.3 °C from −40 to +105 °C on the datasheet |
| R6 | Stay within the FieldNode energy budget | Average draw 30 mW or less at the FieldNode sensor port | Power calculation; later current logging | Met on paper (16.9 mW) |
| R7 | Send and keep the data | One summary per hour of 48 bytes or less, within LoRaWAN regional limits at the data rate in use, with an 11-byte reduced summary (first frequency, its amplitude, two strain means, steel temperature, status) wherever the limit is 11 bytes; raw records kept on site for 12 months or more | Payload and airtime calculation; storage calculation | Met on paper: 36 bytes, or 11 bytes at US915 DR0 and AS923 DR2 (AS923 limit assumed); 22 months on 32 GB |
| R8 | Fit without harming the structure | No drilling, welding or cutting; strain gauges only on an area of paint removed and recoated with the owner's permission; fitted by two trained people in 4 h or less from below or beside the deck | Fitting sequence estimate; later trial fit | Not verifiable at TRL 3 for time (2.8 h estimate); no drilling or welding met by design |
| R9 | Keep clear of what passes under and over the bridge | Nothing more than 15 mm below the girder soffit; nothing on the deck side except the FieldNode on a handrail post, with tamper-resistant fasteners (one-way crimped stainless banding on installed units) | Model check | Met on paper (10 mm; hub inside the girder outline; lanyard girder clamp 8 mm below the soffit) |
| R10 | Survive outdoors | Hub IP67, FieldNode IP65; operate from −20 to +50 °C; 5 years with one gauge recoat and no cell replacement | Datasheets and design review; later environmental checks | At risk: FieldNode heat (FND-CAL-001) and gauge coating life |
| R11 | Protect privacy | No cameras or microphones; only structural readings leave the device | Design review | Met by design |
| R12 | Affordable | BridgePulse-specific parts within the $250 value-engineering target (a hypothetical control target), with the complete cost including the FieldNode core stated beside it | Priced BOM (`bom/bom.csv`) | **Over the value-engineering target by $25.00:** $275.00 estimated; complete $401.00 |
| R13 | Present results responsibly | Every output labeled as monitoring data that supports inspection; no pass or fail safety rating anywhere in the system | Review of dashboard and report templates | Met by design intent; not yet implemented |

## Requirements not met or at risk

- **R12 (cost) over the value-engineering target by $25.00:** the parts added to make the design buildable (BRP-DDR-004: two probe glands, foot blocks, jaws, packers, jack block and screws, $4.00) and those decided on 2026-10-02 (the lanyard's girder clamp, pad eye and made-up wire lanyard, $19.00, and stainless banding for installed units, $4.00) bring the estimated cost of the BridgePulse-specific parts to $275.00 on indicative prices, against the $250 target. The target is a hypothetical control target, not a limit; savings worth trying are in the value engineering section of BRP-DEC-001.
- **R2 (repeatability) at risk:** on a light footbridge the mass of each walker lowers the first mode by up to 6.3 %. Gating out the time when someone is on the span meets 0.2 % in simulation, but the footfall model is idealized and the method must be checked on recorded data (TRL 4, on hold).
- **R3 (change detection) not verifiable at TRL 3:** it depends on modeling temperature and any remaining load effect to a daily residual of 0.75 % or less.
- **R10 at risk:** FieldNode heat and coating life.
- **R4 and R8 not verifiable at TRL 3:** gauge drift and fitting time need tests or a trial fit.

## Assumptions

- The accelerometer follows the ADXL355 datasheet summary ([Analog Devices](https://www.analog.com/en/products/adxl355.html)); a different part must meet R1.
- The FieldNode core offers 100 mW average for sensors as its design value (115 mW ceiling, FND-CAL-001) and two sealed M12 5-pin ports with a switched rail. BridgePulse uses RS-485 (Modbus RTU) and a 5 V rail on FieldNode's candidate pinout, adopted as the shared standard on 2026-10-02 (BRP-DEC-001).
- A temperature-compensated frequency baseline needs at least four weeks of data before any flag, following the approach of [Peeters and De Roeck (2001)](https://doi.org/10.1002/1096-9845%28200102%2930:2%3C149::AID-EQE1%3E3.0.CO;2-Z).
- Steel modulus 210 GPa for converting strain to stress. The other calculation assumptions are in BRP-CAL-001, Table 1.

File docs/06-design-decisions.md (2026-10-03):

---
doc_id: BRP-DEC-001
title: BridgePulse design decisions register
project: BridgePulse
doc_type: Design decisions register
version: "0.4"
status: Draft
date: '2026-10-02'
author: Amish Chadha
license: CERN-OHL-S-2.0
revisions:
- version: "0.1"
  date: '2026-09-30'
  author: Amish Chadha
  change: Register opened; open decisions gathered from the decision records, the review note and the build plan work
- version: "0.2"
  date: '2026-10-01'
  author: Amish Chadha
  change: Budget treated as a value-engineering target
- version: "0.3"
  date: '2026-10-02'
  author: Amish Chadha
  change: "Amish approved the recommendations for all open decisions 1 to 11 on 2026-10-02 (BRP-DDR-004 accepted, P12 subject to FieldNode); moved to decisions made"
- version: "0.4"
  date: '2026-10-02'
  author: Amish Chadha
  change: "Approved follow-ups carried out: lanyard clamp and installation banding priced; value engineering restated (USD 275.00, USD 25.00 over the target); girder clamp rating added to the items to confirm"
---

# BridgePulse design decisions register

Every design decision still to be made, and every decision made, in one place. Each decision is argued in full in its decision record under `docs/decisions/`; this register is the index Amish works from. The build plan (`docs/05-build-plan.md`) describes the design as it stands and does not list open decisions.

## Open decisions

None. All open decisions were decided on 2026-10-02.

## To confirm when parts are bought

| # | What to confirm | Why it matters | Source |
| --- | --- | --- | --- |
| 1 | The host girder's clear web height, flange thickness and root fillet radius | They set the plate length (clear height less 44 mm), the packer length (flange thickness less 0.5 mm) and whether the 22 mm fillet gap and 12 mm chamfer are enough (fillet up to about 20 mm) | BRP-DDR-004, P1 and P2 |
| 2 | The enclosure's base wall thickness and flatness at the four screw points and eight spacer points | The M5 sealing washers and the countersunk M3 screws need a flat, sound wall of about 4 mm | BRP-DDR-004, P4 and P5 |
| 3 | Gland clamping ranges against the real cables: M16 for the gauge cables, M12 for the probe leads | Each gland seals only within its range | BRP-DDR-004, P6 |
| 4 | Flange clip grip ranges: 12.7 mm flange for the cable clips, about 20 mm (flange plus sheath) for the probe clip | A clip outside its range will not hold | BRP-DDR-004, P7 and P11 |
| 5 | The FieldNode band clamp length (about 300 to 330 mm round the 50 mm square post) and that the FieldNode project accepts mounting without V-blocks | The bands must close with adjustment to spare; the interface is FieldNode's, and P12 was accepted on 2026-10-02 subject to this confirmation | BRP-DDR-004, P12; BRP-CAL-001, H8 |
| 6 | The FieldNode core's current cost and mass ($126.00 and 2.41 kg are copied from FND-CAL-001) | FieldNode's own build plan may have changed them; they feed the complete-monitor cost and the post load | BRP-CAL-001, H1 and K |
| 7 | The RP2040 class board's rated temperature range (assumed -20 to +85 °C) and the ADC noise figure (assumed) | They underpin R10 and R4 | BRP-CAL-001, D and J |
| 8 | The girder clamp's working load limit (100 kg or more), the lanyard's breaking load (about 4.8 kN assumed for 3 mm 7 x 7 stainless) and the flange thickness range of the clamp | They set the margin on the 1.20 kN peak if the mount lets go; the lanyard must be fitted with 25 mm of slack or less | BRP-CAL-001, H4a and H4c |

## Value engineering

Value-engineering target: USD 250.00. Estimated cost of the constructable design: USD 275.00 (USD 25.00 over the target). The target is a hypothetical control target, not a limit, and covers the BridgePulse-specific parts (BRP-DDR-001, D1); the complete monitor with the FieldNode core is USD 401.00.

Main cost drivers (BRP-CAL-001, K): the mounting plate, foot blocks, jaws, packers, jack block and lanyard anchor (line 4, $59.00), the industrial microSD card ($20.00), the strain gauge half-bridges, and the TMP1826 class probes ($6.00 each). The parts added for construction (BRP-DDR-004) account for $4.00 of the estimate, the lanyard anchor decided on 2026-10-02 (girder clamp, pad eye and made-up wire lanyard) $19.00 and the stainless banding for installed units (line 10) $4.00.

Savings worth trying:

- A consumer high-endurance microSD card rated -25 to +85 °C in place of the industrial card, saving about $10, if its datasheet covers the range (BRP-DDR-004, A1). On its own it no longer closes the gap.
- A cheaper accelerometer breakout that still meets R1 (BRP-DDR-002).
- Quotes at TRL 4, which may move the indicative prices either way.

## Decisions made

| Date | Decision | Decided by | Record |
| --- | --- | --- | --- |
| 2026-09-25 | TRL 2 review items D1 to D11: budget covers the BridgePulse-specific parts, ambient excitation, hourly 10 minute records, hub on the girder and FieldNode on a post, foil half-bridges with dummies, one accelerometer, RP2040 class controller, engineer-only alerts, temperature-compensated trend, shared lab components, pitch unchanged | Amish: "i accept all your recommendations, go with them across all repos." | BRP-DDR-001, BRP-DDR-002 |
| 2026-09-25 | D12 to D15: load gating with a load regression in TwinKit; 11-byte reduced summary; TMP1826 class probes with an ice-point check; no cost change now, with named savings if quotes come in higher | Amish, same instruction | BRP-DDR-002 |
| 2026-09-27 | Far gauge cable's vertical runs moved inboard of the bottom flanges in the model | Amish: "resolve the challenges for ConePro, BridgePulse, Grainguard and WellSense." | BRP-DDR-003 |
| 2026-10-02 | Design for construction accepted: the changes P1 to P12 of BRP-DDR-004 and their knock-on changes, as made, with P12 (FieldNode on the square post without V-blocks) subject to the FieldNode project confirming that mount | Amish: "i approve your recommendations for all 555 open decisions." | BRP-DDR-004, A5 and Tables 1 and 2 |
| 2026-10-02 | Lanyard anchor: a second, independent bought girder clamp with a stated load rating on the bottom flange, at least 150 mm along the span from the foot clamps, with a stainless wire lanyard; it is to be added to BOM line 4 | Amish: "i approve your recommendations for all 555 open decisions." | BRP-DDR-004, A2 |
| 2026-10-02 | Tamper resistance (R9): stainless banding with a one-way crimped buckle on installed units, worm-drive bands on the bench; FieldNode is asked to adopt the same rule for all its post installations | Amish: "i approve your recommendations for all 555 open decisions." | BRP-DDR-004, A3; BRP-REQ-001, R9 |
| 2026-10-02 | Far gauge cable support between the girders: decided at the site survey; along a cross frame or diaphragm near midspan where there is one, otherwise a tensioned 3 mm stainless catenary wire between two flange clamps | Amish: "i approve your recommendations for all 555 open decisions." | BRP-DDR-004, A4 |
| 2026-10-02 | FieldNode sensor port: the FieldNode candidate adopted as the shared standard (pin 1 switched 5 V rail, pins 2 and 4 RS-485 A and B, pin 3 ground, pin 5 analog) with Modbus RTU as the protocol; FieldNode is asked to record it as decided for every adopting project | Amish: "i approve your recommendations for all 555 open decisions." | BRP-DDR-001, O1; BRP-DDR-002, O1 |
| 2026-10-02 | First host bridge and co-design partner: kept open under the portfolio rule and chosen, when the area is picked, as a 5 to 15 m steel footbridge on rolled I-girders whose owner (a city, park service or university) will share inspection records. First candidate to approach: a university campus footbridge with a civil engineering department | Amish: "i approve your recommendations for all 555 open decisions." | BRP-DDR-001, O2 |
| 2026-10-02 | Data ownership: the bridge owner owns all raw and processed data; the project publishes only monitoring status, and releases datasets for research only with the owner's written consent, under an open licence such as CC BY 4.0 | Amish: "i approve your recommendations for all 555 open decisions." | BRP-DDR-001, O3 |
| 2026-10-02 | LoRaWAN region: the region of the first host bridge; until then the bench unit is built for US915 if it is built and tested in North America | Amish: "i approve your recommendations for all 555 open decisions." | BRP-DDR-002, O4 |
| 2026-10-02 | Clear window in the hub lid: a render aid only; the build uses the plain die-cast lid | Amish: "i approve your recommendations for all 555 open decisions." | `docs/REVIEW.md`, 2026-09-26, item 1 |
| 2026-10-02 | Parts left out of the appearance model (north gauge, air probe, FieldNode and post) accepted; FieldNode has its own renders | Amish: "i approve your recommendations for all 555 open decisions." | `docs/REVIEW.md`, 2026-09-26, item 2 |
| 2026-10-02 | Cable routes in the appearance model: closed, since BRP-DDR-004 set the routes; the appearance model follows the constructable model's routes when the renders are next updated | Amish: "i approve your recommendations for all 555 open decisions." | `docs/REVIEW.md`, 2026-09-26, item 3; BRP-DDR-004, P10 and P11 |

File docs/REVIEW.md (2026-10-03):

# Review note: BridgePulse

## Session 2026-09-25: /populate to a strong TRL 2

### What was done

- `docs/01-problem.md` (BRP-PRB-001 v0.2): problem with cited figures (FHWA, 23 CFR 650.311, RAC Foundation, MLIT, NTSB), users, target structures, operating environment, constraints, prior work (Z24 study, ADXL355, Brooks and Donovan), out of scope, open questions; co-design checklist kept.
- `docs/02-concept.md` (BRP-PRC-001 v0.2): how it works, numbered components, example bridge frequency, measurement resolution, strain, power, data, cost, eight proposed design choices, safety section, open questions.
- `docs/03-requirements.md` (BRP-REQ-001 v0.2): 13 measurable requirements (R1 to R13) with targets, verification method and status at TRL 2.
- `cad/src/concept_media.py`: massing model of a 7 m steel footbridge (context, grey) with the monitor at midspan, eight BOM-numbered parts, a 1.75 m person standing on the deck, and a separate cutaway of the sensor hub. `scale_figure=False` with the person as a context part, because the kit's automatic figure would stand at the girder soffit and clip through the bridge.
- `media/`: `hero.png`, `concept-blueprint` (PNG, PDF, SVG), `exploded.png` with callouts 1 to 8, `cutaway.png` (sensor hub), `flow.png` (hourly data flow, estimates), `model.glb` and `viewer.html`. All images were checked by eye; temporary `media/_views*` folders are removed by the script.
- `bom/bom.csv`: eight lines numbered to match the exploded view, indicative USD prices; `bom/bom-notes.md` updated with totals.
- `README.md`: hero image and links line, expanded Concept rationale, Burning platform, Where it could be used (6 industries, 5 regions), What sparked the idea; Problem, Concept, Key components and Safety brought in line with the concept.
- `docs/pdf/`: branded PDFs of the three controlled documents.

### Key results (estimates, to be checked at TRL 3)

| Quantity | Estimate | Requirement |
| --- | --- | --- |
| First vertical mode, 7 m example footbridge | about 24 Hz | Inside R2 band |
| Spectral bin width per hourly record | about 0.015 Hz | R2 met by design |
| Accelerometer noise in one bin | about 2.8 µg | R1 met on datasheet |
| Strain from a crowd on the example bridge | about 100 µε; one pedestrian about 3 µε | R4 resolution 2 µε |
| Average power draw | about 15 mW (about 84 mW while recording) | R6 met on estimate |
| Uplink per hour | about 36 bytes | R7 met on estimate |
| Raw data on site | about 1.4 GB per month; about 23 months on 32 GB | R7 met on estimate |
| Parts cost, complete | about $342 ($216 BridgePulse-specific, $126 FieldNode core) | **R12 not met** |

Requirements not met or at risk:

- **R12 (cost) not met:** about $342 against the $250 budget, 37 % over.
- **R3 (1 % change detection) not demonstrated:** it depends on quiet bridges giving a usable ambient signal and on a temperature model that holds across seasons.
- **R2 repeatability, R4 drift, R5 accuracy and R10 durability not verified:** they rest on datasheets and estimates.
- **R7 regional payload limits not checked** for each LoRaWAN region.

### Proposed, awaiting Amish

Update 2026-09-25: items 1 to 7 and 9 are now **Decided by Amish, 2026-09-25: go with recommendation** (BRP-DDR-001 D1 to D8, BRP-DDR-002). Items 8 and 10 had no recommendation and remain "Proposed, awaiting Amish".

1. **Budget (R12).** Options: (a) keep $250 and redefine R12 as "BridgePulse-specific parts $250 or less", treating the FieldNode core as a shared component costed in its own repo; (b) raise `budget_usd` to $350; (c) cut cost with a cheaper accelerometer, which would likely fail R1. Recommendation: (a), with the complete system cost always stated beside it. `project.yaml` is unchanged.
2. **Ambient vibration only**, no shaker or impact hammer. Recommendation: yes for TRL 3; revisit if quiet footbridges give no clear peaks.
3. **Hourly 10 minute windows** rather than continuous recording (about 15 mW against about 84 mW). Recommendation: windows.
4. **Separate sensor hub on the girder, FieldNode on a handrail post.** Recommendation: yes.
5. **Foil gauge half-bridges with dummy gauges** rather than weldable or vibrating-wire gauges. Recommendation: foil for cost, with drift checked early.
6. **One accelerometer at midspan**, with a second at quarter span as a later option. Recommendation: one.
7. **Microcontroller class for the hub** (RP2040 class proposed; alternatives are an STM32 with a floating-point unit or doing only raw capture in the hub). Recommendation: RP2040 class for cost and tooling.
8. **FieldNode sensor port pinout and protocol** to be agreed with the FieldNode project; nothing in FieldNode is changed here.
9. **Alert policy and public view.** Flags only to the owner's engineer; CityTwin shows monitoring status only. Recommendation: yes.
10. **First host bridge and partner** for co-design (a town, park service or university footbridge).

`project.yaml` pitch and problem were left unchanged; the figures found support them.

### Safety concerns

- False reassurance: owners might defer inspections because a monitor shows "no change". All outputs must say the data supports inspection and is never a safety rating (R13).
- Work at height, over water and near traffic during installation.
- Lead or other hazardous paint on older steel bridges when preparing strain gauge areas; gauge adhesives and coatings are chemicals.
- Falling parts: clamps loosening onto people, vehicles or boats below; secondary lanyards are specified.
- Tampering with the post-mounted FieldNode; the LiFePO4 cell inside it.

### Problems and notes

- The legacy `cad/src/model.py` placeholder is untouched (TRL 3 work).
- The strain gauge callout (5) in the exploded view sits between the two gauge patches because both girders' gauges are one BOM line.
- No named open-source bridge monitor was found in the time available; the prior-work review should be extended at TRL 3.
- WebSearch was unavailable this session; every cited figure was checked by fetching the source page directly. A Morbi (India) footbridge figure and a German bridge figure were left out because their primary sources could not be fetched.

### Recommended next step

Review this note and the media, then decide items 1 and 8 in particular. If approved, run `/advance-trl3` to check the frequency, noise, strain and power estimates by calculation (including a test of the detection method on published Z24 data), and produce the parametric model and drawing sheet.

## Session 2026-09-25: TRL 3

On 2026-09-25 Amish asked for this batch of repos to go through the usual process with the instruction "you know the drill, nothing gets past TRL 3". He has not reviewed this repo's TRL 2 items one by one, so every item that carried a recommendation is adopted as recommended for TRL 3 under Amish's 2026-09-25 instruction, open for his review. This session ran `/advance-trl3` on that basis and stopped at TRL 3.

### What was done

- `docs/decisions/0001-trl2-review-decisions.md` (BRP-DDR-001 v0.1, status proposed): eleven items adopted as recommended for TRL 3, open for Amish's review (D1 to D11), and three left open (O1 to O3).
- `docs/04-calcs/01-sizing.md` (BRP-CAL-001 v0.1) and `docs/04-calcs/sizing.py`: bridge dynamics and mass loading, excitation and a Monte Carlo simulation of the hourly frequency estimate, change detection statistics, strain, temperature, power, data and LoRaWAN airtime, mounting stiffness, mass and clearance, installation time, outdoor life and cost, with a status for every requirement. The script imports the model, reads the BOM and `project.yaml`, and prints every number the note quotes (fixed random seed).
- `cad/src/model.py`: parametric build123d model (hub enclosure with glands, accelerometer and signal boards, jacked mounting plate with tab, jack screw and two flange-tip clamps, gauge covers and dummy coupons, temperature probes, cable runs, FieldNode core massing on the midspan post; the example bridge as context). Exports `cad/step/` and `cad/stl/` for `bridgepulse-assembly`, `sensor-hub` and `bridgepulse-installed`.
- `cad/src/sheets.py` and `cad/drawings/BRP-DWG-001.svg`, `.pdf`, `.png`: general arrangement at Rev P1 (front and right views at 1:20, detail A of the hub at 1:4, isometric), marked "CONCEPT, NOT FOR FABRICATION" and "PRELIMINARY, NOT FOR FABRICATION". BRP-DWG-001 was free because the concept blueprint is BRP-DWG-010. The deck and handrails are left off the views for clarity.
- `bom/bom.csv` (nine lines, all priced with a supplier or supplier type) and `bom/bom-notes.md`: $244.00 BridgePulse-specific, $370.00 complete.
- `cad/src/concept_media.py` now builds from the model; all of `media/` was re-rendered and every image checked; no `_views` folders remain.
- BRP-PRB-001, BRP-PRC-001 and BRP-REQ-001 revised to v0.3; `README.md` (badge, TRL line, links, Concept paragraph, key components) and `project.yaml` (`trl: 3`, `trl_target: 3`, evidence list) updated. The required README sections are unchanged in name and order; none of their figures changed. PDFs rebuilt in `docs/pdf/`.

### Requirement status (BRP-CAL-001, Table 5)

1 not met, 4 at risk, 3 not verifiable at TRL 3, 2 met on paper, 3 met by design.

| ID | Status | Key number |
| --- | --- | --- |
| R2 Track frequencies | **Not met** | Sensor-noise scatter 0.053 % an hour at 100 µg (curve fit), but one 75 kg walker lowers f₁ by up to 6.3 % and walker mass adds 0.45 % scatter at 5 crossings an hour; 0.2 % would need about 26 single crossings an hour |
| R5 Temperature | At risk | ±0.5 °C only from -10 °C upward |
| R7 Data | At risk | 36 bytes fits EU868, not US915 DR0 or AS923 DR2 (11 bytes) |
| R10 Outdoor life | At risk | FieldNode heat not met in its own repo; coating life unknown |
| R12 Cost | At risk | $244.00 against $250 (2.4 % margin); $370.00 complete |
| R3 Change detection | Not verifiable at TRL 3 | Needs a daily residual of 0.75 % or less after temperature and load compensation |
| R4 Strain | Not verifiable at TRL 3 (drift) | 0.09 µε RMS resolution; range met |
| R8 Fitting | Not verifiable at TRL 3 (time) | 2.8 h estimate; no drilling met by design |
| R6, R9 | Met on paper | 16.9 mW average; 10 mm below the soffit |
| R1, R11, R13 | Met by design | |

Key numbers: first mode 23.9 Hz (modal mass 535 kg); 92.9 mW while recording; 1.39 GB of raw data a month, 22 months on 32 GB; 3.34 kg on the girder; mounting resonance 126 to 253 Hz.

Design changes made by the calculations, within the adopted choices: the mounting plate stands on the bottom flange and is jacked against the top flange (the TRL 2 plate held at the bottom flange only would resonate at about 77 Hz, near the band); the hub runs from FieldNode's switched 5 V rail and is off between records; it post-processes each record from the card because three axes do not fit in the RP2040's RAM; the frequency is estimated by a curve fit, because peak picking never reaches 0.2 %. TRL 2 numbers corrected: EI 6.52 × 10⁷ N·m² (was 6.8), 167 kg/m (was 172), recording 92.9 mW (was 84), average 16.9 mW (was 15), 22 months on the card (was 23), hub and mount 3.34 kg (was 0.6), FieldNode 2.41 kg (was 1.7), cost $244 and $370 (was $216 and $342).

### Decisions recorded (BRP-DDR-001)

Decided by Amish, 2026-09-25: go with recommendation (recorded at this session as adopted for TRL 3, open for his review; see BRP-DDR-002): D1 keep `budget_usd` at $250 and redefine R12 as BridgePulse-specific parts, complete cost stated beside it (applied to R12; no new budget figure was recommended, so `budget_usd` is unchanged); D2 ambient vibration only; D3 hourly 10 minute windows; D4 hub on the girder, FieldNode on a post; D5 foil half-bridges with dummies; D6 one accelerometer at midspan; D7 RP2040 class controller; D8 engineer-only alerts, status-only public view; D9 temperature-compensated trend with a four-week minimum baseline; D10 built on FieldNode, TwinKit and CityTwin; D11 no change to pitch or problem (none was recommended).

### Still awaiting Amish

1. **O1, FieldNode port pinout and protocol.** No recommendation; this repo assumes FieldNode's candidate pinout with RS-485 and a 5 V rail, as a working assumption only.
2. **O2, first host bridge and co-design partner.** No preference stated.
3. **O3, data ownership and what is published** beyond monitoring status. No recommendation.
Update 2026-09-25: items 4 to 7 are now **Decided by Amish, 2026-09-25: go with recommendation** (BRP-DDR-002, D12 to D15). O1 to O3 remain "Proposed, awaiting Amish".

4. **New, R2 and people's mass.** Options: (a) gate out record segments while someone is on the span, using the acceleration envelope or the strain channel, and estimate frequency from the rest; (b) regress each hourly frequency on a load indicator (strain mean, RMS acceleration) in TwinKit; (c) keep R2 at 0.2 % only for bridges whose modal mass is at least 20 times a walker's mass, and state a looser target (for example 1 % hourly, with daily averaging) for light footbridges. Recommendation: (a) and (b) together, checked on recorded data before any change to R2; R2 is unchanged here.
5. **New, reduced payload (R7).** An 11-byte summary at US915 DR0 and AS923 DR2 with dwell time. Recommendation: adopt once the region is known (FND-DDR-001, O1). Not applied.
6. **New, cold-range temperature check (R5).** Options: accept ±0.5 °C only above -10 °C, add an ice-point and a second reference check, or use a probe specified to -20 °C. Recommendation: ice-point check plus a probe specified over the full range if one fits the $6 margin. Not applied.
7. **New, cost margin (R12).** $6.00 is thin for indicative prices. If quotes come in higher, the first savings would be a consumer high-endurance card and a cheaper accelerometer breakout that still meets R1. No change proposed now.

Suggestions only, not in the repo: analyze the public Z24 record, or another open bridge data set, to test the temperature model against the 0.75 % daily residual; extend the prior-work review of open bridge monitors.

### Cross-repo consistency

- FieldNode (read its REVIEW.md and CAL-001; not edited): the $126.00 core cost, 2.41 kg mass, 52.2 N panel wind load, two M12 5-pin ports with one switched rail each and the 100 mW design allowance are used as FieldNode states them. BridgePulse uses 16.9 mW, 17 % of that allowance. Two points for FieldNode's review: (1) FieldNode's pole kit is designed for round poles; BridgePulse mounts it on a 50 mm square handrail post, whose 70.7 mm diagonal is at the 71 mm upper fit, so the V-block seating on a square post needs checking; (2) the port pinout is open on both sides. FieldNode's default 15 min, 20-byte schedule is replaced here by an hourly 36-byte uplink, which its D6 allows.
- TwinKit: hosts the baseline and flags as TwinKit's REVIEW.md describes; no conflict. The load regression proposed in item 4 would run there.
- CalRig: its chamber reaches about 9 to 13 °C at its coldest (CLR-CAL-001), so it cannot check the probes below -10 °C (item 6).

### Safety concerns

- False reassurance: a "no change" trend on a light footbridge could hide a real change behind traffic effects (R2). Outputs must stay framed as inspection support, never a safety rating (R13).
- Work at height, over water and near traffic during installation; the jacked plate adds a preload that must be set and checked, and the clamps and lanyard keep it from falling if the preload is lost.
- Lead or other hazardous paint when preparing gauge areas; adhesives and coatings are chemicals.
- Aluminium plate on steel: galvanic corrosion could loosen it over years unless isolated.
- FieldNode on the post: tampering, its LiFePO4 cell, and heat in hot sun as FieldNode's own calculation reports.

### Gaps and notes

- Citations: the TRL 2 note listed no unchecked citations. WebFetch confirmed the DS18B20 accuracy range (maker's page) and the RP2040's 264 kB of RAM (Raspberry Pi documentation). It did not confirm the LoRaWAN regional payload limits (the pages fetched did not state them) or an ADS1220 noise figure (the product page gives none) or the RP2040 temperature range; these are stated as assumptions in BRP-CAL-001, Table 1, and remain flagged here. WebSearch was not used (quota exhausted). No figure left out at TRL 2 was added to the README.
- Assumptions only data or tests can settle: damping (1 %), heel-strike impulse (2 N·s), ADC noise, gauge-to-dummy mismatch, jack preload, and the size of temperature and load effects on real bridges.
- The kit's cutaway cuts at the mean Y of all parts and would miss the hub, so `concept_media.py` keeps its own hub cutaway (`cut=False` in `render_all`), as at TRL 2. In the exploded view the accelerometer board (item 2) is small and mostly under its callout, and callout 5 floats between the two gauge patches because both are one BOM line.
- Existing material beyond TRL 3: `build-log/README.md` (scaffold) is present, untouched and not extended. `electronics/` and `firmware/` are empty. No test, build or firmware material exists.

### Recommended next step

TRL 4 is on hold by Amish's instruction; this repo stops at TRL 3. Amish's review is needed on BRP-DDR-001 (D1 to D11), on O1 to O3 and on new items 4 to 7 above, item 4 first because it decides whether the method suits light footbridges. For the record only, TRL 4 would need: a bench build of the hub on a girder specimen; a lab test report (TST, `environment: lab`) covering accelerometer noise and the mounting resonance of the jacked plate, frequency estimates from recorded footfall with people of known mass, gauge drift and thermal mismatch, probe accuracy including below -10 °C, and hub energy per record through a FieldNode port; and build log entries. None of this has been started.

## Session 2026-09-25: recommendations accepted

On 2026-09-25 Amish wrote: "i accept all your recommendations, go with them across all repos." Every item with a recommendation is now **Decided by Amish, 2026-09-25: go with recommendation**, recorded in `docs/decisions/0002-recommendations-accepted.md` (BRP-DDR-002 v0.1). BRP-DDR-001 is revised to v0.2 with D1 to D11 marked decided.

### Decisions applied and what changed

| Decision | Change | Before | After |
| --- | --- | --- | --- |
| D1 to D11 (BRP-DDR-001) | Status wording only; `budget_usd` stays at $250 for the BridgePulse-specific parts, pitch and problem unchanged | Adopted for TRL 3, open for review | Decided |
| D12, R2 and people's mass | Load gating in the hub (gate from the strain step, 0.25 s pad, 10 dB and damping acceptance rule) plus a load regression in TwinKit; simulated in BRP-CAL-001 v0.2, B10 to B12 | Scatter 0.45 % at 5 crossings (simple count; 1.5 to 3.1 % in the new time-varying simulation); R2 not met | 0.015 % or less gated (1 to 20 crossings per record; 80 % of records accepted with one crossing); R2 at risk, target unchanged |
| D13, reduced payload | 11-byte summary where the data rate allows 11 bytes; R7 restated | 36 bytes only; R7 at risk | 36 or 11 bytes (371 ms at SF10); R7 met on paper (AS923 limit assumed) |
| D14, cold-range temperature | TMP1826 class probe in a stainless sheath plus an ice-point check | DS18B20 class, ±0.5 °C from −10 °C; $4.00 each; R5 at risk | ±0.3 °C from −40 to +105 °C; $6.00 each; R5 met on paper |
| D15, cost margin | No change; contingency savings recorded | $244.00 specific, $6.00 margin; $370.00 complete | $248.00 specific, $2.00 margin (0.8 %); $374.00 complete |

Files changed: BRP-PRB-001 v0.4, BRP-PRC-001 v0.4, BRP-REQ-001 v0.4, BRP-CAL-001 v0.2 with `docs/04-calcs/sizing.py`, BRP-DDR-001 v0.2, new BRP-DDR-002 v0.1, `bom/bom.csv` (item 6), `bom/bom-notes.md`, `cad/src/sheets.py` and BRP-DWG-001 at Rev P2 (probe note added; notes box moved up so the last line clears the title block), `cad/src/concept_media.py` (key figures), `README.md`, `project.yaml` (evidence list only). `cad/src/model.py` geometry is unchanged; STEP and STL were re-exported. All media and PDFs were regenerated with the designmolecule.com footer.

The CAL note also corrects a v0.1 wording error: the walker-mass scatter in B8 counts crossings inside the 10 minute record, not crossings an hour.

README: "What sparked the idea" rewritten around the 1967 Silver Bridge collapse and the National Bridge Inspection Standards of 1971 (FHWA source); the reference to a September 2026 review of the lab's research areas was removed. BRP-PRB-001 did not attribute the idea to a review.

### Requirement status (BRP-CAL-001 v0.2, Table 5)

0 not met, 3 at risk, 3 not verifiable at TRL 3, 4 met on paper, 3 met by design (was 1, 4, 3, 2, 3).

| ID | Status | Key number |
| --- | --- | --- |
| R2 Track frequencies | At risk | 0.015 % or less with load gating in simulation; to be checked on recorded data |
| R10 Outdoor life | At risk | FieldNode heat not met in its own repo; coating life unknown |
| R12 Cost | At risk | $248.00 against $250 (0.8 % margin); $374.00 complete |
| R3 Change detection | Not verifiable at TRL 3 | Needs a daily residual of 0.75 % or less; the traffic term falls to 0.010 % with gating |
| R4 Strain | Not verifiable at TRL 3 (drift) | 0.09 µε RMS; range met |
| R8 Fitting | Not verifiable at TRL 3 (time) | 2.8 h estimate |
| R5, R6, R7, R9 | Met on paper | ±0.3 °C; 16.9 mW; 36 or 11 bytes; 10 mm below the soffit |
| R1, R11, R13 | Met by design | |

### Still awaiting Amish

1. **O1, FieldNode port pinout and protocol.** No recommendation.
2. **O2, first host bridge and co-design partner.** No preference stated.
3. **O3, data ownership and what is published.** No recommendation.
4. **O4, LoRaWAN region for the first installation** (FND-DDR-001, O1). No recommendation here; D13 makes R7 independent of it.

### Cross-repo actions

- **TwinKit:** host the load regression of D12 (hourly frequency against strain mean and RMS acceleration) beside the temperature model.
- **FieldNode:** (1) review seating its V-block clamps on a 50 mm square handrail post, whose 70.7 mm diagonal is at the 71 mm upper fit; (2) make the payload limit of the current data rate available to the sensor port so the hub can pick the 11-byte summary (D13); (3) agree the port pinout (O1).
- **CalRig:** its chamber does not reach the cold range, so the ice-point check of D14 is done outside it.

No other repo was edited.

### Verification and gaps

- WebFetch confirmed the TMP1826 accuracy (Texas Instruments product page) and the EU868 and US915 payload limits (The Things Network regional pages). The AS923 dwell-time limit could not be fetched (LoRa Alliance site blocked) and stays an assumption. The ADS1220 noise figure and RP2040 temperature range remain assumptions, as before.
- The gating simulation is optimistic: one mode, an idealized walker, a perfect gate and no wind while people cross. Its gated scatter is below the random-excitation floor because the free decays after each crossing are clean in the model.
- The TMP1826 probe is a made part (sensor potted in a sheath); its $6.00 price is indicative.

### TRL 4

TRL 4 remains on hold by Amish's instruction. The recorded-data check of load gating (D12), the ice-point and CalRig checks of the new probes (D14) and quotes for the BOM (D15) are decided but on hold. No build, test, purchase, PCB or firmware work was started.

## Session 2026-09-26: product appearance model and photoreal renders

Amish chose this repo for the first batch of product renders on 2026-09-26.

### What was added

`cad/src/product_model.py` exposes `product_parts()` (48 parts: 31 shell, 12 internal, 3 accessory, 2 context), `TITLE` and `RENDER_VIEWS` (hero, exploded, and a low detail view that shows the accelerometer board through the lid window). It reuses PARAMS and derived() from `cad/src/model.py`; the hub, board, plate, jack, clamp, gauge, coupon and probe sizes and positions are as model.py. It adds:

- Sensor hub (BOM 1): powder-coated die-cast base and lid with filleted edges, a gasket line at the parting plane, four lid screws, a teal name plate, an IP67 rating label, an accelerometer axis mark on the lid, two M12 cable glands, and the M12 panel connector with its moulded plug and knurled coupling nut (BOM 7).
- Accelerometer board (BOM 2) with its sensor, header and screws; signal board (BOM 3) with the RP2040 class module, ADC and RS-485 modules, microSD socket and card (BOM 9), gauge terminal block, brass standoffs and a lit green status light.
- Mounting plate (BOM 4): hard anodized with a filleted outline, top tab and ID label; M12 jack screw with lock nut and swivel pad; the two flange-tip clamps with jaws, M10 bolts, nuts, washers and screws to the plate foot.
- Strain gauges (BOM 5): active foil gauge under its cover patch below the bottom flange; dummy gauge on its steel coupon, with its own cover, on the flange top.
- Steel temperature probe (BOM 6) as a bonded boss with a lead strain relief.
- Sensor cables (BOM 7) with UV-stable clips, and context (not in the BOM): a 520 mm section of the south girder, IPE 360 class with root fillets, and a strip of the timber deck.

`README.md` now shows `media/render-hero.png` and links `media/render-exploded.png`; the orchestrator produces both files.

### Differences from model.py (Proposed, awaiting Amish)

1. **Clear window in the hub lid.** BOM line 1 is a die-cast aluminium box with a plain lid. The appearance model adds a clear polycarbonate window so the accelerometer and signal boards show. Proposed, awaiting Amish. Recommendation: keep the window as a render aid only and build with the plain die-cast lid, which keeps IP67 simple and the enclosure stiff; option: a gasketed window if a status light must be readable on site.
2. **Parts left out to keep the render compact.** The north girder's gauge and cover, the air temperature probe under the deck, and the FieldNode core with its handrail post (BOM 8) are not shown; they stay in model.py and the concept media. Proposed, awaiting Amish. Recommendation: accept; FieldNode has its own renders in its repo.
3. **Cable routes shortened and moved.** The cables end at the edges of the girder section. The far gauge cable crosses under the flange at x = +100 mm instead of x = -100 mm, so it no longer crosses the near gauge cable in front of the hub, and the FieldNode cable rises past the deck edge at x = -130 mm instead of x = 0 so it does not run across the lid window. Proposed, awaiting Amish. Recommendation: adopt both routes in model.py at the next CAD revision; neither changes an interface.
4. **model.py cable clash (found while routing).** In model.py the far gauge cable passes the inner flange edges at y = ±522 mm, which is 7 mm inside the 515 mm flange edge, so the modelled cable runs through each bottom flange. The appearance model uses y = -508 mm. Proposed, awaiting Amish. Recommendation: change `inner_n` in model.py to `gy - bf / 2 - r - 3` at the next CAD revision; it is a modelling error, not a design change.
5. **Probe sheath size.** model.py draws the steel probe as a 14 mm diameter by 15 mm boss (radius taken as `t_probe[0]` = 7 mm), while BOM line 6 gives a 7 mm by 60 mm sheath. The appearance model keeps the model.py envelope and treats it as a bonded boss holding the sheath. Proposed, awaiting Amish. Recommendation: show the 7 mm sheath and its clip in model.py at the next CAD revision.
6. **The active gauge is not visible in the hero.** It sits under the bottom flange and every view is from above the studio floor; the hero shows the dummy gauge coupon and the gauge cable wrapping the flange tip, and the exploded view shows the active gauge and its cover. No change proposed.

### Status

This is an appearance model only: no tolerances, no fabrication detail, nothing past TRL 3. `trl: 3` and `trl_target: 3` are unchanged, and TRL 4 remains on hold. model.py, the BOM and the other documents were not edited.

## Session 2026-09-27: owner decision applied

Amish's instruction: "resolve the challenges for ConePro, BridgePulse, Grainguard and WellSense." For BridgePulse the decided item is item 4 of the 2026-09-26 session, the far gauge cable clash in `cad/src/model.py`. Decided by Amish on 2026-09-27; recorded in BRP-DDR-003.

### What changed

- `cad/src/model.py`: new function `far_cable_inner()` returns `gy - bf / 2 - cable_r - 3` (508 mm); `build_parts()` uses it for `inner_n` (was `gy - bf / 2 + r + 3`, 522 mm). No other dimension or interface changed.
- `cad/src/product_model.py`: the far gauge cable now takes its inboard offset from `far_cable_inner()` instead of its own formula. The value is the same (y = -508 mm), so the appearance model's geometry is unchanged. Its far cable crossing at x = +100 mm (item 3) is kept, since that item is still open.
- Regenerated: `cad/step/*.step`, `cad/stl/*.stl`, `media/hero.png`, `exploded.png`, `cutaway.png`, `flow.png`, `concept-blueprint.*`, `model.glb`, and `cad/drawings/BRP-DWG-001.*`, now Rev P3 (`cad/src/sheets.py`, revision row "Far gauge cable clear of bottom flanges per BRP-DDR-003").
- `docs/decisions/0003-far-gauge-cable-route.md` (BRP-DDR-003 v0.1), new, and listed in `project.yaml` `trl_evidence`.
- `docs/pdf/` rebuilt with `python .kit/render.py`.

### Result

The far gauge cable's vertical runs now sit 3 mm (cable surface) inboard of the inner bottom-flange edges at |y| = 515 mm. A check in build123d against 800 mm of both girders gives zero overlap (was 1,277 mm³ for the far cable), with the closest approach of any cable the intended 2 mm where it is clipped under a flange. No other document stated the old value; the BOM, requirements and calculations are unaffected (R9 clearance below the soffit is unchanged).

### Photoreal renders

Regeneration of `media/render-*.png` is **not needed**: no part in any RENDER_VIEWS view (hero, exploded, detail) changes shape, size or position.

### Still Proposed, awaiting Amish

From the 2026-09-26 session: item 1 (clear window in the hub lid), item 2 (parts left out of the appearance model), item 3 (far gauge cable crossing at x = +100 mm and FieldNode cable at x = -130 mm in the appearance model), and item 5 (steel probe drawn as a 14 mm boss against the 7 mm sheath in BOM line 6).

### Status

`trl: 3` and `trl_target: 3` are unchanged; TRL 4 remains on hold. No fabrication-level detail was added.

## Session 2026-09-27: kit 1.5.0 and image quality

- Kit 1.5.0 synced: STANDARDS v1.5 (sections 12 to 15: product renders, storefront images and image quality, public release, authorship and signing), `.kit/cards.py`, `.kit/image_qc.py`, `.kit/release_gate.py`, issue templates, and the `/render-product` and `/release` commands. `CLAUDE.md` now matches `.kit/CLAUDE.md`.
- Every `media/render-*.png` recaptioned from its original render with the new layout: the title, concept label and repository sit in a band above the render and the view note in a band below it, each line wrapped to the image width, so no text overlaps other text or the render or runs off the image. `media/card.png` and `media/social-preview.png` regenerated with the same rules.
- `python .kit/image_qc.py` and `python .kit/release_gate.py` pass. trl stays 3.

## Session 2026-09-30: design for construction and prototype build plan (kit 1.7.0)

Amish's instructions of 2026-09-30: an illustrated build plan for every repo in the approved format, with outstanding decisions kept out of the plan in a separate design decisions register, and "If you are realising that the design cannot be built as per concept - fix the design assumptions to match and be physically feasible as you draw the illustrations."

### What was done

- Kit 1.7.0 installed (`.kit/`, `.claude/commands/`); `CLAUDE.md` matches `.kit/CLAUDE.md`.
- `cad/src/model.py` rebuilt as separate components (`build_components()`), with root fillets on the girders and 75 constructability checks (`python cad/src/model.py --check`): all pass.
- New decision record `docs/decisions/0004-design-for-construction.md` (BRP-DDR-004 v0.1, Draft): every change below, made under Amish's 2026-09-30 instruction to make the design physically buildable; open for his review.
- New `docs/05-build-plan.md` (BRP-BLD-001 v0.1) with pictures from `cad/src/build_plan_media.py`: an overview, 7 making sketches (`cad/drawings/BRP-DWG-101` to `107`), 2 hole layouts, 9 joint close-ups, 13 assembly step pictures and a wiring diagram, all in `docs/05-build-plan/`.
- New `docs/06-design-decisions.md` (BRP-DEC-001 v0.1): 11 open decisions (budget treated as a value-engineering target on 2026-10-01), 7 items to confirm when parts are bought, and the decisions made.
- Updated: BRP-CAL-001 v0.3 with `sizing.py`, BRP-REQ-001 v0.5, BRP-PRC-001 v0.5, `bom/bom.csv` (lines 1, 2, 4 to 8), `bom/bom-notes.md`, `cad/src/sheets.py` and BRP-DWG-001 Rev P5, STEP and STL, the concept media (`media/hero.png`, `exploded.png`, `cutaway.png`, `flow.png`, `concept-blueprint.*`, `model.glb`), `project.yaml` (`design_state: constructable`, evidence list) and `README.md` (links line and "Building the prototype").

### Design changes made for construction (BRP-DDR-004)

1. Mounting plate shortened to 290.6 mm and kept 22 mm clear of each flange, so it lies flat on the web between the 18 mm root fillets instead of standing on one.
2. Foot clamps redesigned: a stepped aluminium foot block screwed to the plate (two M6), with a 12 mm chamfer over the root fillet, clamped to the bottom flange by a 10 mm steel jaw, a packer outside the flange edge and an M10 bolt that ends inside the jaw.
3. Jack tab replaced by a 30 mm jack block screwed to the plate, tapped M12 the full depth, with the screw's head and lock nut below it; the screw bears 26 mm out from the web, clear of the top root fillet.
4. Hub fixed to the plate by four M5 screws from inside the box with bonded sealing washers.
5. Accelerometer board on four 5 mm spacers and signal board (now 92 x 68 mm) on four 14 mm standoffs, on countersunk M3 screws from outside the base.
6. Two M12 probe glands added; five penetrations in one row, 9 mm or more apart.
7. Steel probe is now the 7 x 60 mm sheath on the bottom flange top under a push-on flange clip (closes item 5 of the 2026-09-26 review in `model.py`).
8. Air probe hangs from the far gauge cable's crossing, its lead alongside that cable (it had hung from nothing).
9. Dummy coupons moved 35 mm out from the web, clear of the fillet, and set on silicone so they are not strained.
10. Gauge cover patches 60 x 40 mm (were 90 x 45), so no cable passes through them.
11. Cables held by push-on spring-steel flange clips; the FieldNode cable rises beside the post (it ran inside the post's outline) and plugs into port B (it ended under the antenna).
12. FieldNode on the square post: V-blocks left off, back plate flat on the post, band clamps one size longer through the plate slots; the panel in this repo's FieldNode envelope now faces away from the post (it faced the post), and the bracket envelope starts on the back plate.

### Key results

- Mass on the girder 3.21 kg (was 3.34 kg); mount resonance 135 to 271 Hz (was 126 to 253 Hz; target 120 Hz); 10 mm below the soffit at most (R9 limit 15 mm); hub 9 mm inside the flange edge line.
- **R12 is over the value-engineering target:** value-engineering target $250 (a hypothetical control target, not a limit); estimated cost of the constructable design $252.00 ($2.00 over the target; the two probe glands and the clamp parts added $4.00). Complete monitor $378.00. `budget_usd` is unchanged.
- Requirement count (BRP-CAL-001 v0.3): 1 over the value-engineering target (R12), 2 at risk (R2, R10), 3 not verifiable at TRL 3, 4 met on paper, 3 met by design.

### Proposed, awaiting Amish (in BRP-DEC-001)

1. Accept the design for construction (BRP-DDR-004, A5). Recommendation: accept.
2. Lanyard anchor (safety case). Recommendation: a second, independent beam clamp on the bottom flange.
3. Tamper resistance of the FieldNode on a public footbridge (R9). Recommendation: one-way crimped stainless banding for installations.
4. Support for the far gauge cable between the girders. Recommendation: decide at the site survey, preferring a cross member.

The savings worth trying against the value-engineering target (a consumer high-endurance card, a cheaper accelerometer breakout) are in the value engineering section of the register. Items O1 to O4 and review items 1 to 3 of 2026-09-26 remain open, as listed in the register.

### Safety

The build plan carries safety stops for lifting the girder offcuts, lead paint, gauge chemicals, first power and the FieldNode cell, and keeps installation on a bridge outside the plan. The lanyard anchor (item 2) is part of the safety case and is not yet chosen.

### Media and renders

The photoreal renders (`media/render-*.png`), `media/card.png`, `media/social-preview.png` and the appearance model `cad/src/product_model.py` are made on Amish's Mac and were not regenerated. They are now **stale**: they show the concept plate standing on the flange, the tab, the old clamps, the probe boss and two glands. `media/render-*.png` are not in this cloud copy.

### Recommended next step

Amish reviews BRP-DDR-004 and the register. TRL stays at 3; TRL 4 remains on hold.

## Session 2026-10-02: open decisions decided

On 2026-10-02 Amish approved the recommendations for every open decision: "i approve your recommendations for all 555 open decisions." The 11 open decisions of the design decisions register are now in its Decisions made table, dated 2026-10-02.

BRP-DDR-004 (design for construction) is accepted, with P12 subject to the FieldNode project confirming the square-post mount; A2 to A5 are decided as recommended, and A1 stays a value-engineering saving. Review flag 2 below concerns items 4 and 5 of the 2026-09-26 review, which BRP-DDR-004 resolved in the constructable model (P7 and the new cable routes).

### Documents changed

- `docs/06-design-decisions.md` (BRP-DEC-001 v0.3)
- `docs/decisions/0004-design-for-construction.md` (BRP-DDR-004 v0.3)
- `docs/02-concept.md` (BRP-PRC-001 v0.7)
- `docs/03-requirements.md` (BRP-REQ-001 v0.7)
- `docs/04-calcs/01-sizing.md` (BRP-CAL-001 v0.5)
- `docs/05-build-plan.md` (BRP-BLD-001 v0.3)
- `bom/bom-notes.md` (not a controlled document)

### Follow-up actions to carry approved decisions into the design

1. Decision 1: Ask the FieldNode project to confirm the square-post mount without V-blocks and the longer bands (P12); until it does, P12 stays conditional.
2. Decision 2: Model: add the second, independent girder clamp on the bottom flange at least 150 mm along the span from the foot clamps, with the lanyard run to it, and add its constructability checks.
3. Decision 2: Drawings: show the lanyard clamp on BRP-DWG-001 and the relevant making sketch.
4. Decision 2: Build plan pictures: show the lanyard clamp and lanyard in the installation and fixings figures.
5. Decision 2: BOM: add the load-rated girder clamp and stainless wire lanyard to line 4 with quantity and price.
6. Decision 2: Calculations: add the clamp to the mass on the girder (BRP-CAL-001, H1) and the cost (K), and state its required load rating against the hub's mass with a dynamic factor (H4).
7. Decision 3: BOM: add stainless banding with one-way crimped buckles for installed units (the bench unit keeps the worm-drive bands of line 8), and ask FieldNode to adopt the rule for all post installations.
8. Decision 5: Ask the FieldNode project to record its candidate pinout and Modbus RTU as decided for every adopting project; write the firmware's Modbus RTU register map when firmware starts.
9. Decision 11: Appearance model and renders: when the renders are next updated on Amish's Mac, make `cad/src/product_model.py` follow the cable routes of `cad/src/model.py`.

### Points found in the review

1. Item 11 is already decided by BRP-DDR-004 (P10 and P11) and should move out of the open table.
2. REVIEW 2026-09-26 items 4 (cable passing through the flange) and 5 (probe sheath) were resolved by BRP-DDR-004 (P7 and the new routes) but are not marked closed.
3. The FieldNode candidate pinout is described in FieldNode's own records as 'for discussion only'; both repos are waiting on each other, so the decision needs to be made once, in FieldNode.

No CAD model, BOM quantity or price, calculation result or picture was changed. TRL stays at 3; TRL 4 remains on hold.

## Session 2026-10-02: approved follow-ups carried out

Amish approved on 2026-10-02 that every follow-up action from the open-decision sign-off be carried out ("APPROVED CHANGES, COMPLETE THESE") and that the render scenes be prepared for new photoreal renders. TRL stays at 3; nothing here builds, tests or buys anything.

### Follow-ups, one by one

1. **Decision 1, FieldNode to confirm the square-post mount (P12).** Done in this repo: P12 stays conditional in BRP-DEC-001 (items to confirm, 5). The request to FieldNode is listed under Cross-repo actions below.
2. **Decision 2, model.** Done. `cad/src/model.py` now has a stainless pad eye on two M5 screws at the top left of the plate, a 3 mm stainless wire lanyard with a thimble eye round the pad eye's loop and round the clamp's eye, and a bought single-flange girder clamp with an eye, set screw and lock nut hooked on the south bottom flange tip at x = -275 mm, 159 mm along the span from the nearer foot clamp. The plate's plain 6.5 mm lanyard hole is replaced by the two tapped M5 holes: with the plate flat on the web, a wire could not have passed through a plain hole. 16 new constructability checks (pad eye on the plate, screws short of the web, clamp on the flange, set screw on the flange top, 150 mm or more from the foot clamps, lanyard bearing on both eyes and clear of girder, hub, mount, cables and probes): **91 of 91 pass**. STEP and STL regenerated (`cad/step/`, `cad/stl/`); the pad eye is part of `sensor-hub.step`.
3. **Decision 2, drawings.** Done. BRP-DWG-001 **Rev P6** shows the girder clamp and the lanyard in the front view, with the 159 mm clearance dimensioned, the pad eye in detail A and a line in the notes. Making sketch BRP-DWG-101 (mounting plate) **Rev P2** gives the pad eye holes in place of the lanyard hole. The clamp, pad eye and lanyard are bought, so they have no making sketch.
4. **Decision 2, build plan pictures.** Done. New joint 10 (girder clamp on the flange) and new step 9 (lanyard and its girder clamp); the overview shows the lanyard as component 17; the plate hole layout shows the pad eye holes; steps 10 to 14 (were 9 to 13) show the fitted lanyard. All step pictures redrawn with the longer bench offcut needed for the clamp.
5. **Decision 2, BOM.** Done. Line 4 ($40.00 to $59.00): girder clamp with a working load limit of 100 kg or more $12.00, pad eye and screws $3.00, made-up wire lanyard $6.00 in place of the $2.00 plain lanyard. Basis for each price in `bom/bom-notes.md`.
6. **Decision 2, calculations.** Done. BRP-CAL-001 v0.6: H1 adds the lanyard parts (0.37 kg; **3.58 kg on the girder**, was 3.21 kg); H4a and H4c rate the lanyard and clamp: 3.21 kg falling onto 25 mm of slack in a 436 mm wire gives a **1.20 kN peak, a dynamic factor of 38**, so the clamp needs a working load limit of 30 kg or more at a 4:1 design factor (specified 100 kg or more) and the wire's assumed 4.8 kN breaking load is 4.0 times the peak; K adds the cost.
7. **Decision 3, BOM.** Done. New line 10, installation banding for installed units only: two lengths of 12.7 x 0.76 mm stainless band and two one-way crimped buckles, $4.00; the bench unit keeps the worm-drive bands of line 8. The request to FieldNode is a cross-repo action.
8. **Decision 5, pinout and register map.** The FieldNode request is a cross-repo action. **Not done:** the firmware's Modbus RTU register map, because firmware has not started; under the TRL 3 cap firmware beyond a labelled sketch is not allowed. It stays a follow-up for when firmware starts.
9. **Decision 11, appearance model.** Done. `cad/src/product_model.py` rebuilt from `build_components()` so every part except the appearance hub shell (filleted box, lid, gasket, window, labels) is the constructable model's own geometry: plate, foot blocks, jaws, packers, bolts, jack block, jack screw, glands, connector, boards, probe and clip, gauges, the lanyard and its girder clamp, and the cables and flange clips on the model's routes, cut to a 640 mm girder section. RENDER_VIEWS kept (hero, exploded, detail). Render scenes exported with `.kit/export_views.py` to `/home/claude/renders/bridgepulse`: `bridgepulse__hero`, `__exploded` and `__detail` (.npz and .json each) and `bridgepulse__jobs.json`. Photoreal renders, `media/card.png` and `media/social-preview.png` are to be made on Amish's Mac.

### Documents changed and new versions

- `cad/src/model.py`, `cad/src/sheets.py`, `cad/src/build_plan_media.py`, `cad/src/concept_media.py`, `cad/src/product_model.py`, `docs/04-calcs/sizing.py`
- `cad/drawings/BRP-DWG-001` Rev P6; `cad/drawings/BRP-DWG-101` Rev P2
- `docs/04-calcs/01-sizing.md` (BRP-CAL-001 v0.6)
- `docs/03-requirements.md` (BRP-REQ-001 v0.8)
- `docs/02-concept.md` (BRP-PRC-001 v0.8)
- `docs/05-build-plan.md` (BRP-BLD-001 v0.4): new section 3.11 and step 9, steps renumbered, bench offcuts about 650 mm (about 37 kg each), first check and safety stops S7 and S8 name the lanyard; the "pictures unchanged" note of v0.3 is gone
- `docs/06-design-decisions.md` (BRP-DEC-001 v0.4): value engineering restated; item 8 to confirm (clamp rating, wire breaking load)
- `docs/decisions/0004-design-for-construction.md` (BRP-DDR-004 v0.4): consequences updated
- `bom/bom.csv`, `bom/bom-notes.md`, `README.md`
- Pictures: `docs/05-build-plan/overview.png`, `plate-holes.png`, `joint-10.png` (new), `step-05.png` to `step-14.png` (`step-14.png` new); `media/hero.png`, `exploded.png`, `cutaway.png`, `concept-blueprint.*`, `model.glb`. The cutaway leaves the lanyard parts out, since its section plane would cut the clamp away from its wire.

### Requirement status changes

- **R12:** still over the value-engineering target, now by **$25.00** (was $2.00). Value-engineering target: USD 250.00. Estimated cost of the constructable design: USD 275.00 (USD 25.00 over the target). Complete monitor $401.00. `budget_usd` unchanged. The savings named in the register (consumer high-endurance card, cheaper accelerometer breakout) no longer close the gap on their own.
- R9 stays met on paper: the girder clamp's lower jaw is 8 mm below the soffit, within the 10 mm worst case and the 15 mm limit.
- No other status changes. Counts: 1 over the value-engineering target (R12), 2 at risk (R2, R10), 3 not verifiable at TRL 3, 4 met on paper, 3 met by design.
- BRP-CAL-001 H3 now quotes the printed 75 Hz (the note said 77 Hz); a text correction, no status change.

### Cross-repo actions (for the FieldNode repo; not edited here)

- FieldNode to confirm the square-post mount without V-blocks and the band clamps one size longer, band about 300 to 330 mm (BRP-DDR-004, P12); until then P12 stays conditional.
- FieldNode to adopt one-way crimped stainless banding for all its post installations, with worm-drive bands only on the bench (BRP-DEC-001, decision of 2026-10-02 on tamper resistance).
- FieldNode to record its candidate pinout (pin 1 switched 5 V rail, pins 2 and 4 RS-485 A and B, pin 3 ground, pin 5 analog) and Modbus RTU as decided for every adopting project; its own records still call the pinout "for discussion only".

### Proposed, awaiting Amish

- Appearance deviations in `cad/src/product_model.py`: the hub is drawn as a filleted, powder-coated box with lid screws, a name plate, labels and the clear lid window (the window decided as a render aid on 2026-10-02); the cables, probe lead and clips are cut at the ends of the girder section; the lanyard is drawn taut. Recommendation: accept as appearance only.
- R12 at $25.00 over the target: the girder clamp is the largest addition. Options: (a) accept the gap until TRL 4 quotes; (b) take the microSD saving now (about $10); (c) look for a cheaper rated clamp. Recommendation: (a) with (b), since the clamp is part of the safety case.

### Safety

The lanyard is now a real, rated second retention path that shares nothing with the foot clamps. Its peak load depends mostly on slack, so the build plan and safety stop S8 limit it to 25 mm; the clamp rating and the wire breaking load are assumed catalogue values to confirm when parts are bought (register item 8). The bench offcuts are now about 37 kg each; the plan says two people or a hoist.

### Recommended next step

Amish makes the photoreal renders from the exported scenes on his Mac, then runs `.kit/cards.py`. The FieldNode project takes up the three cross-repo actions. TRL stays at 3; TRL 4 remains on hold.

## 2026-10-02: photoreal renders redone on the constructable design

Rendered with Blender Cycles on Amish's Mac from the updated appearance model (`cad/src/product_model.py`); captioned with `.kit/photo_caption.py`; `media/card.png` and `media/social-preview.png` regenerated with `.kit/cards.py`. Views: hero, exploded, detail. image_qc passes. Appearance deviations are those logged above as proposed, awaiting Amish.

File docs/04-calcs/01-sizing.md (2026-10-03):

---
doc_id: BRP-CAL-001
title: BridgePulse sizing calculations
project: BridgePulse
doc_type: Calculation
version: "0.6"
status: Draft
date: '2026-10-02'
author: Amish Chadha
license: CERN-OHL-S-2.0
revisions:
- version: "0.1"
  date: '2026-09-25'
  author: Amish Chadha
  change: First issue for TRL 3 (bridge dynamics, excitation and frequency precision by simulation, change detection statistics, strain, temperature, power, data and uplink, mounting stiffness and clearance, installation time, outdoor life, cost)
- version: "0.2"
  date: '2026-09-25'
  author: Amish Chadha
  change: Recommendations accepted by Amish (DDR-002); load gating simulated (B10 to B12, C4), TMP1826 class probes (E), 11-byte reduced summary and regional limits checked (G), cost (K), results table (L)
- version: "0.3"
  date: '2026-09-30'
  author: Amish Chadha
  change: Design made constructable (BRP-DDR-004); mounting mass, stiffness, retention and root fillets (H1, H2, H4, H4b), FieldNode on the square post (H8), cost (K) and results (L) re-run; R12 now not met by $2.00
- version: "0.4"
  date: '2026-10-01'
  author: Amish Chadha
  change: Budget treated as a value-engineering target; R12 wording only, no number changed
- version: "0.5"
  date: '2026-10-02'
  author: Amish Chadha
  change: "Lanyard anchor recorded as decided on 2026-10-02 (independent girder clamp); text only, no number changed"
- version: "0.6"
  date: '2026-10-02'
  author: Amish Chadha
  change: "Approved decisions of 2026-10-02 carried into the design: lanyard girder clamp, pad eye and wire added to the mass (H1) and rated (H4a, H4c); BOM line 4 re-priced and installation banding added (K); R12 now $25.00 over the value-engineering target; H3 corrected to the printed 75 Hz"
---

# BridgePulse sizing calculations

On paper, BridgePulse can measure what it sets out to measure, provided it ignores the moments when people are on a light footbridge. Of its thirteen requirements, seven are met (four by calculation, three by design), two are at risk, three cannot be verified at TRL 3, and one, the cost requirement R12, is over the value-engineering target by $25.00 since versions 0.3 and 0.6 added the parts that make the design buildable and the lanyard anchor and installation banding decided on 2026-10-02. The instrument itself is good enough: a simulation of the hourly record shows that, with a curve fit in place of simple peak picking, the scatter from sensor noise is 0.05 % at a modest 100 µg of bridge response, close to the theoretical floor. But on the 7 m example footbridge one 75 kg walker adds enough mass to lower the first mode by about 5 % while they cross, so an estimate taken over the whole record moves with who happened to walk over. Version 0.2 applies the decision recorded in BRP-DDR-002: the hub gates out each crossing, found from the strain step, and fits the rest of the record. In a time-varying simulation this cuts the scatter from 1.5 to 3.1 % to 0.015 % or less, so R2 moves from not met to at risk until recorded data confirm it. R3, the 1 % change detection, depends on how well a model can remove temperature and any remaining load effect; this note sets the target that model must meet (a daily residual of 0.75 % or less), which only field data can confirm. Version 0.2 also meets R5 on paper with a TMP1826 class probe and R7 with an 11-byte reduced summary, at a cost of $4. The calculations also changed the mounting: the TRL 2 plate, held only at the bottom flange, would have resonated at about 75 Hz, too close to the measured band, so the plate now lies against the web between the flanges and is jacked against the top flange. Version 0.3 follows the design for construction of BRP-DDR-004: the plate is kept clear of the root fillets and stands on two clamped foot blocks, which gives 135 to 271 Hz, and the added clamp parts and glands brought the BridgePulse-specific parts to $252.00. Version 0.6 carries in the decisions of 2026-10-02: a second, independent girder clamp with a wire lanyard as the second retention path, rated here against the falling mass with a dynamic factor, and stainless banding with one-way crimped buckles for installed units. They bring the mass on the girder to 3.58 kg and the BridgePulse-specific parts to $275.00, $25.00 over the $250 value-engineering target (R12; savings in the design decisions register, BRP-DEC-001). Every number in this note is printed by `docs/04-calcs/sizing.py`; the tag in brackets, for example [A3], is the line of that script's output that carries it.

> **Safety:** These are first-principles estimates for a paper proof of concept. They say nothing about whether any bridge is safe. BridgePulse supports inspection by qualified engineers and never replaces it. Installation is work at height, over water or near traffic, and may disturb lead paint; see BRP-PRC-001, Safety.

## Scope and method

The note checks every requirement in BRP-REQ-001 v0.8 against the design in BRP-PRC-001 v0.8 and the parametric model `cad/src/model.py`. The script imports the model's `PARAMS`, `derived()` and part solids, so the girder section, plate, hub position, clearances and part volumes used here are the ones in the STEP files and in drawing BRP-DWG-001. It also reads `bom/bom.csv` and `budget_usd` in `project.yaml`. Run it from the repo root with `python docs/04-calcs/sizing.py`; it takes about 20 s, most of it the simulations in section B, which use fixed random seeds so its figures repeat exactly.

The design case is the example bridge of BRP-PRC-001: a 7 m steel footbridge, 6.4 m between bearings, on two IPE 360 class girders at 1.2 m centers with a 50 mm timber deck, monitored at midspan, with a FieldNode core on the midspan handrail post reporting hourly over LoRaWAN.

## Assumptions

*Table 1. Main assumptions.*

| Area | Assumption | Basis |
| --- | --- | --- |
| Bridge | Simply supported, pinned bearings, no composite action from the deck; girder section from the model's rectangles (no root fillets); steel 210 GPa, 7,850 kg/m³; timber deck 500 kg/m³; rails and posts 20 kg/m | Screening model; the catalog IPE 360 is slightly stiffer [A1] |
| Temperature | Steel modulus falls by 0.03 % per kelvin | Typical for structural steel near room temperature; assumed |
| Damping | 1 % of critical in the first vertical mode | Assumed; light steel footbridges are often lower, which would sharpen the peak |
| Footfall | 75 kg walker at 2 Hz and 1.3 m/s; an effective heel-strike impulse of 2 N·s on a mode above 10 Hz | Order-of-magnitude assumption, to be measured |
| Accelerometer | ADXL355 class, 22.5 µg/√Hz, white; 250 Hz output data rate with the filter corner at 62.5 Hz | Maker's product page (BRP-PRB-001) |
| Spectra | Hann window, 16,384-point segments, 50 % overlap over a 600 s record | As BRP-PRC-001 |
| Strain | Gauge factor 2.0; 350 Ω gauges; 3.3 V excitation; ADC noise 0.15 µV RMS at 20 SPS and gain 128; gauge-to-dummy thermal mismatch 1 µε/K | ADS1220 class; the noise figure is assumed because the maker's product page does not state one |
| Power | 5 V switched rail from the FieldNode port, 85 % buck in the hub, 90 % FieldNode rail converters; the hub is off between records | FieldNode D5 and FND-CAL-001 |
| Radio | 13 bytes of LoRaWAN overhead; 125 kHz, coding rate 4/5, 8-symbol preamble, explicit header; regional payload limits of the LoRaWAN Regional Parameters (EU868, US915, AS923) | EU868 (51 bytes at DR0 to DR2) and US915 (11 bytes at DR0, 53 at DR1) checked against The Things Network's [EU868](https://www.thethingsnetwork.org/docs/lorawan/regional-parameters/eu868/) and [US915](https://www.thethingsnetwork.org/docs/lorawan/regional-parameters/us915/) pages; the AS923 dwell-time limits are assumed |
| Load gating | Crossing found from the strain step and gated out with 0.25 s either side, edges tapered over 0.1 s; ambient (wind) response 10 µg RMS with nobody on the span; single mode, walker as a moving mass and heel-strike train | Assumed; the ambient level stands for a quiet bridge and the footfall model is idealized |
| Lanyard | 3 mm 7 × 7 stainless wire rope: metallic area 53 % of the circle, effective modulus 100 GPa, minimum breaking load 4.8 kN; fitted with 25 mm of slack at most; girder clamp maker's design factor 4:1 between working load limit and ultimate load | Typical catalogue values for the class of part, assumed; to be confirmed against the bought parts |
| Wind | 35 m/s gust, air 1.225 kg/m³, drag 1.3 on the FieldNode enclosure; 52.2 N on its panel | FND-CAL-001 |

## A. Example bridge dynamics (R2, R3)

- **Section and mass.** One girder from the model's rectangles has I = 15,524 cm⁴ and W = 862 cm³, about 5 % below the catalog IPE 360 [A1]. The span carries 167 kg/m, and EI for the two girders is 6.52 × 10⁷ N·m² [A2].
- **First mode.** f₁ = (π / 2L²) √(EI / m) = 23.9 Hz; the second vertical mode is 96 Hz, outside the band, so only the first vertical mode (and possibly a torsional mode) is tracked on this span. The modal mass is 535 kg [A3]. The TRL 2 estimate of 24 Hz stands.
- **What a 1 % shift means.** Frequency goes with the square root of stiffness, so a lasting 1 % drop in frequency is a 2 % loss of bending stiffness [A4].
- **Temperature.** The change of the steel modulus alone moves the frequency by 0.015 % per kelvin, 1.05 % over the -20 to +50 °C range of the requirements [A5]. That is as large as the target, so compensation is needed even before bearings, deck and surfacing, whose effects cannot be computed on paper.
- **People on the deck.** The example bridge is light, so the people on it change its frequency. One walker at midspan lowers f₁ by 6.3 %, and by 3.3 % averaged over a crossing; a crowd of one person per square meter lowers it by 22.7 % [A6]. On a road bridge with 20 t of modal mass one walker moves it by only 0.19 % [A7]. Mass loading is therefore a footbridge problem first.
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

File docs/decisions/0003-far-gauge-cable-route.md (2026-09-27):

---
doc_id: BRP-DDR-003
title: BridgePulse far gauge cable route between the girders
project: BridgePulse
doc_type: Design decision record
version: "0.1"
status: Draft
date: '2026-09-27'
author: Amish Chadha
license: CERN-OHL-S-2.0
revisions:
- version: "0.1"
  date: '2026-09-27'
  author: Amish Chadha
  change: Record Amish's decision to move the far gauge cable's vertical runs inboard of the bottom flanges in cad/src/model.py (REVIEW.md, session 2026-09-26, item 4)
---

# 0003: Far gauge cable route between the girders

- **Date:** 2026-09-27
- **Status:** accepted. Decided by Amish on 2026-09-27.

## Context

While routing cables for the product appearance model (`docs/REVIEW.md`, session 2026-09-26, item 4), the review found a modelling error in `cad/src/model.py`. The far gauge cable, which runs from the north girder's gauge across to the hub on the south girder, rose and fell between the girders at |y| = 522 mm. The inner edges of the bottom flanges are at |y| = 515 mm (girder centerline 600 mm less half the 170 mm flange), so the modelled 8 mm diameter cable ran 11 mm into each bottom flange. The error was in the sign of two terms in `inner_n`, not in the design intent, which is a cable clipped under each flange and rising clear of it.

## Options considered

1. Change `inner_n` in `cad/src/model.py` from `gy - bf / 2 + r + 3` to `gy - bf / 2 - r - 3`, placing the vertical runs one cable radius plus 3 mm inboard of the inner flange edges (recommended in the review).
2. Leave `model.py` as it is and correct only the appearance model (the state after 2026-09-26).

## Decision

Option 1. Decided by Amish on 2026-09-27. Amish's instruction: "resolve the challenges for ConePro, BridgePulse, Grainguard and WellSense."

The formula now lives in one function, `far_cable_inner()` in `cad/src/model.py`, which `build_parts()` uses for `inner_n` and `cad/src/product_model.py` imports for its own far gauge cable, so the two models cannot drift apart again.

## Consequences

- The far gauge cable's vertical runs are at |y| = 508 mm. Its surface is 3 mm inboard of each inner flange edge; the solid overlap between the cables and the girders in the model is zero (was 1,277 mm³ for the far cable alone), and the closest approach anywhere is the intended 2 mm under the flange where the cable is clipped.
- Every other dimension and interface is unchanged. No change to the BOM, the budget, the requirements or the calculations: the calc note does not use the cable route, and the clearance below the soffit (R9) is set by the cable runs under the flanges, which did not move.
- Regenerated from `model.py`: `cad/step/*.step`, `cad/stl/*.stl`, the concept media in `media/`, and drawing BRP-DWG-001, now Rev P3.
- The appearance model already used |y| = 508 mm, so the photoreal renders (`media/render-*.png`) do not change.
- Other open items from the 2026-09-26 review (lid window, parts left out, cable routes shortened and moved, probe sheath size) remain "Proposed, awaiting Amish".
- TRL stays at 3; TRL 4 remains on hold.

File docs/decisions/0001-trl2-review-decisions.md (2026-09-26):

---
doc_id: BRP-DDR-001
title: BridgePulse TRL 2 review decisions
project: BridgePulse
doc_type: Design decision record
version: "0.2"
status: Draft
date: '2026-09-25'
author: Amish Chadha
license: CERN-OHL-S-2.0
revisions:
- version: "0.1"
  date: '2026-09-25'
  author: Amish Chadha
  change: Record the TRL 2 review recommendations adopted for TRL 3 work under Amish's 2026-09-25 instruction, and the items that remain open
- version: "0.2"
  date: '2026-09-25'
  author: Amish Chadha
  change: Recommendations accepted by Amish (DDR-002); D1 to D11 now decided
---
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

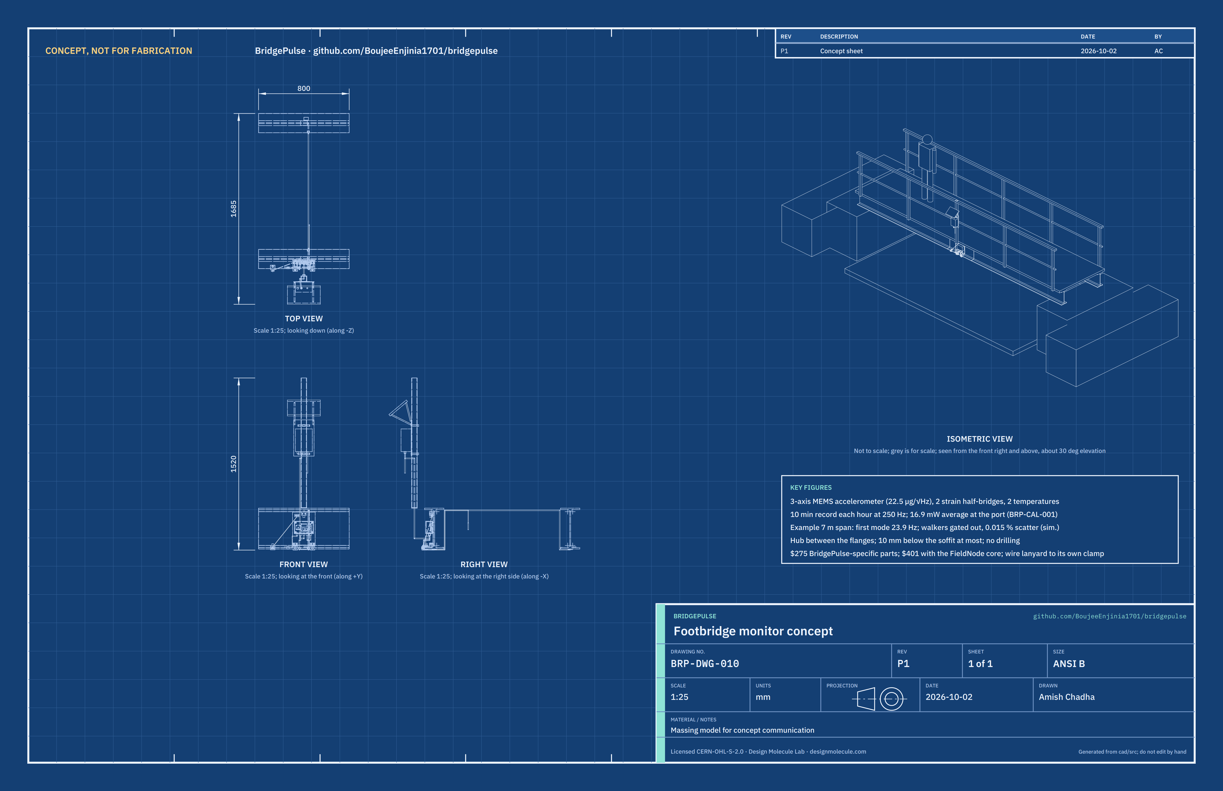
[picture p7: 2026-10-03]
media/concept-blueprint.png

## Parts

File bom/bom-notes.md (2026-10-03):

# BOM notes

Prices are indicative (TRL 3), each with a supplier or supplier type in `bom/bom.csv`; every line is priced. Item numbers 1 to 8 match the exploded view in `media/exploded.png`; item 9, the microSD card, sits in the signal board, and item 10, the installation banding, is used only on installed units and is not modelled. Totals are checked by `docs/04-calcs/sizing.py` (BRP-CAL-001, section K).

| Group | Items | Cost |
| --- | --- | --- |
| BridgePulse-specific parts | 1 to 7, 9, 10 | $275.00 |
| FieldNode core (shared component, costed in the FieldNode repo) | 8 | $126.00 |
| **Complete monitor for one bridge** | 1 to 10 | **$401.00** |

`budget_usd` in `project.yaml` is $250. Under BRP-DDR-001 D1 (decided by Amish, 2026-09-25: go with recommendation), it is a hypothetical value-engineering target covering the BridgePulse-specific parts. Value-engineering target: USD 250.00. Estimated cost of the constructable design: USD 275.00 (USD 25.00 over the target, 10.0 %). The complete monitor is $151.00 over the $250 target and is always stated beside it. The savings named in BRP-DDR-002 (a consumer high-endurance card and a cheaper accelerometer breakout that still meets R1) would recover part of the gap; see the value engineering section of the design decisions register (`docs/06-design-decisions.md`).

Change under BRP-DDR-002: item 6 is now a TMP1826 class probe potted in a stainless sheath at $6.00 each (was a DS18B20 class probe at $4.00), so R5 holds down to -20 °C; +$4.00.

Changes from TRL 2 ($216 BridgePulse-specific, $342 complete): the mounting plate is now an aluminium plate jacked between the flanges with two flange-tip clamps (BRP-CAL-001, section H); the signal board gains a buck converter and an RS-485 transceiver for the FieldNode link; the microSD card is a separate industrial-grade line; the cable line adds a moulded M12 5-pin cable to the FieldNode port.

The bridge itself, installation labor, access equipment, traffic management, paint testing and consumables for surface preparation are not included.

Change under BRP-DDR-004 (design for construction, 2026-09-30): item 1 adds two M12 probe glands and the base fixing (+$2.00, now $22.00); item 4 becomes the plate with two foot blocks, two steel jaws, two packers, a jack block and their screws (+$2.00, now $40.00); items 2, 5, 6, 7 and 8 have their fixing spelled out (spacers, coupon on silicone, probe flange clip, push-on flange clips, FieldNode V-blocks left off and longer bands) at no change in price.

Decisions of 2026-10-02 (BRP-DEC-001), carried into the BOM on 2026-10-02: line 4 gains the lanyard anchor (+$19.00, now $59.00) and a new line 10 carries the installation banding ($4.00). Installed units hold the FieldNode with stainless banding and one-way crimped buckles; the worm-drive bands of line 8 are for the bench unit.

| Line | Part added | Qty | Price | Basis |
| --- | --- | --- | --- | --- |
| 4 | Single-flange girder clamp with an eye, set screw and lock nut, working load limit 100 kg or more | 1 | $12.00 | Indicative small-quantity price for a galvanized malleable iron or steel beam clamp of this class; the rating need is in BRP-CAL-001, H4c |
| 4 | Stainless pad eye, 38 x 22 mm base, with two M5 x 10 stainless screws | 1 | $3.00 | Indicative marine hardware price for a 316 stainless pad eye and two screws |
| 4 | Made-up 3 mm 7 x 7 stainless wire lanyard, about 0.45 m, thimble eye and crimped ferrule at each end | 1 | $6.00, replacing the $2.00 plain lanyard already in the line (+$4.00) | Indicative rigging supplier price for a short made-up lanyard |
| 10 | 12.7 x 0.76 mm 304 stainless banding, two lengths of about 0.4 m, and two one-way crimped buckles | 1 set | $4.00 | About $0.80 a metre of band from a 30 m roll and about $1.00 a buckle, with an allowance for waste; the banding tool is borrowed or hired |

Mass of the line 4 additions from the model: 0.37 kg on the girder (BRP-CAL-001, H1).

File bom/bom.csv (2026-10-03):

item | qty | spec | supplier | unit_cost_usd | make_buy | notes
1 Sensor hub enclosure | 1 | Die-cast aluminium box, IP67, 170 x 64 x 110 mm outside, with gasketed lid; base drilled for four M5 screws to the mounting plate (bonded sealing washers inside) and for the board standoffs (countersunk M3 from outside, sealed); bottom face drilled for two M16 cable glands (gauge cables), two M12 cable glands (probe leads) and the M12 5-pin panel connector (line 7) | Electronics distributor (Hammond 1590 class or similar) | 22.00 | buy | Indicative price; stiff base couples the accelerometer to the plate. Two M12 glands added for the probe leads and the base fixing made explicit under BRP-DDR-004 (+$2.00)
2 Accelerometer board | 1 | ADXL355 class 3-axis MEMS accelerometer, 22.5 µg/√Hz noise density, SPI, on a small breakout board; screwed to the enclosure base on four 5 mm metal spacers | Analog Devices evaluation board (EVAL-ADXL355-PMDZ class) or electronics distributor | 48.00 | buy | Indicative price for a breakout
3 Signal board | 1 | Module stack at TRL 3: RP2040 class microcontroller board, 24-bit bridge ADC module (ADS1220 class), 5 V to 3.3 V buck converter, RS-485 transceiver module, microSD socket, bridge completion resistors (2 x 10 kΩ per channel, 0.1 %), gauge excitation switch, standoffs | Electronics distributor | 25.00 | buy | Indicative price; a custom board is later work and not started
4 Mounting plate, foot clamps and jack | 1 | 6061 aluminium plate 200 x 290.6 x 8 mm (cut to the bridge's clear web height less 44 mm), hard anodized, tapped M5 and M6; two stepped foot blocks (40 mm slices of 100 x 40 mm 6061 flat bar); two steel clamp jaws 40 x 45 x 10 mm tapped M10; two steel packers cut to the flange thickness less 0.5 mm; jack block (40 x 30 x 30 mm 6061, tapped M12); M12 x 70 stainless jack screw and lock nut; two M10 x 35 and six M6 x 30 stainless screws; isolating washers; lanyard (second retention path): one stainless pad eye (38 x 22 mm base, two M5 x 10 screws into the plate), one 3 mm 7 x 7 stainless wire lanyard about 0.45 m with a thimble eye and crimped ferrule at each end, and one bought single-flange girder clamp with an eye, set screw and lock nut, with a maker's working load limit of 100 kg or more (BRP-CAL-001, H4), fitted on the bottom flange 150 mm or more along the span from the foot clamps; no drilling of the structure | Local fabricator or online plate cutting service; fastener supplier | 59.00 | buy | Indicative price; plate cut to the bridge's clear web height (BRP-DWG-001). Foot blocks, jaws, packers and jack block made under BRP-DDR-004 (+$2.00). Lanyard anchor decided 2026-10-02 (BRP-DEC-001): girder clamp $12.00, pad eye and screws $3.00, made-up wire lanyard $6.00 in place of the $2.00 plain lanyard (+$19.00); basis in bom-notes.md
5 Strain gauge half-bridges | 2 | Per girder: one active 350 Ω foil gauge (self-temperature-compensated for steel) under the bottom flange and one dummy gauge on a steel coupon 40 x 25 x 6 mm of the same steel, set in neutral-cure silicone on the flange top so it is not strained; cyanoacrylate adhesive; protective coating and a 60 x 40 mm cover patch | Strain gauge supplier | 25.00 | buy | Indicative price per half-bridge (share of a gauge pack plus adhesive and coating); paint removal needs owner permission and a lead test
6 Temperature probes | 2 | TMP1826 class 1-Wire digital temperature sensor (+/-0.3 °C from -40 to +105 °C, WSON package) on a small carrier, potted in a stainless sheath 7 mm x 60 mm with a sealed outdoor lead; one on the bottom flange top held by a spring-steel flange clip with thermal paste, one hanging in shaded air between the girders | Assembled from an electronics distributor (sensor and carrier) and a probe sheath supplier | 6.00 | make | Indicative price per probe; replaces the DS18B20 class probe ($4.00) under BRP-DDR-002 so the accuracy covers -20 °C; ice-point check before installation
7 Sensor cables, clips and connectors | 1 | Shielded 4-core outdoor cable about 10 m (two gauge cables), one M12 5-pin moulded cable about 2 m from the hub's M12 5-pin panel connector to the FieldNode port, M12 panel connector, five spring-steel flange clips (push-on, for 10 to 16 mm flanges) with UV-stable cable ties | Electronics distributor | 35.00 | buy | Indicative price; the flange clips hold the cables to the flange edges without drilling
8 FieldNode core | 1 | Shared lab component: IP65 enclosure, 6 W panel, 6 Ah LiFePO4 cell, MPPT charger, LoRaWAN radio, two M12 5-pin sensor ports, pole mounting kit; on a square handrail post the V-blocks are left off and the two band clamps are one size longer (band about 300 to 330 mm) | Built from the FieldNode BOM | 126.00 | make | FieldNode parts cost $126.00 (FND-CAL-001); costed in the FieldNode repo and shown here for the complete-system figure. Longer band clamps cost about the same as the standard ones (BRP-DDR-004)
9 microSD card | 1 | Industrial grade microSD, 32 GB, rated -25 to +85 °C; holds about 22 months of raw records | Electronics distributor | 20.00 | buy | Indicative price; sits in the signal board socket (no separate model part)
10 Installation banding | 1 | Installed units only (BRP-DEC-001, 2026-10-02): two lengths of 12.7 x 0.76 mm 304 stainless banding, about 0.4 m each, with two one-way crimped (ear-lock) buckles, in place of the FieldNode's worm-drive band clamps on a public bridge; needs a banding tool (borrowed or hired, not in the BOM). The bench unit keeps the worm-drive bands of line 8 | Banding and fixings supplier | 4.00 | buy | Indicative price: about $0.80 a metre of band from a 30 m roll and about $1.00 a buckle; tamper resistance for R9

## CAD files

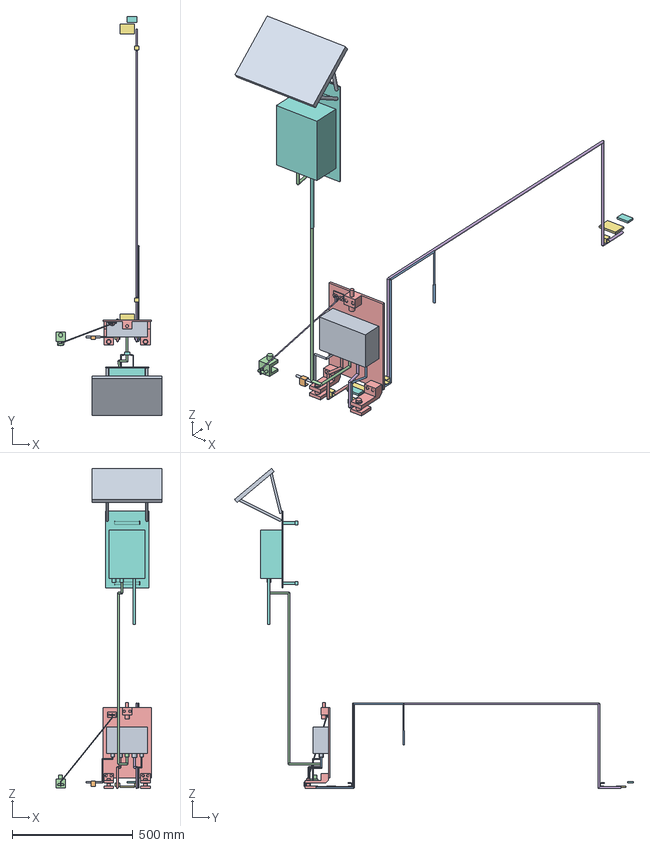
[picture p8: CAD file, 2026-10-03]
cad/step/bridgepulse-assembly.step
440.0 x 1651.6 x 1325.8 mm

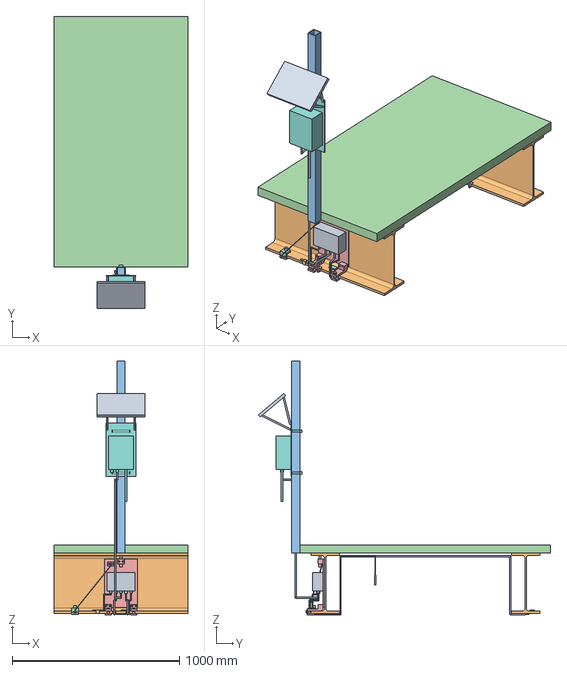
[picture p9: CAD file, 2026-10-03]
cad/step/bridgepulse-installed.step
800.0 x 1750.1 x 1520.0 mm

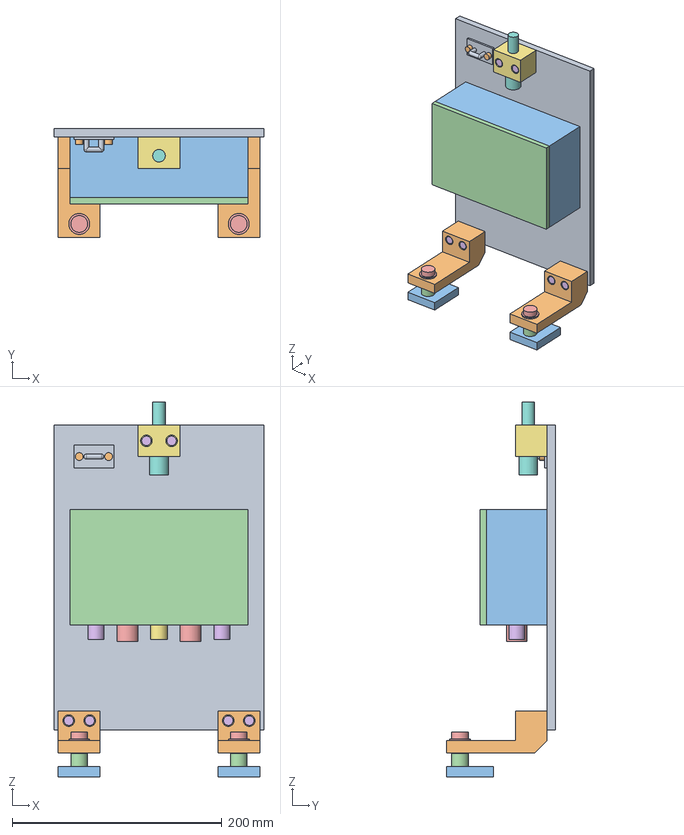
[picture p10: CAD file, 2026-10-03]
cad/step/sensor-hub.step
200.0 x 104.0 x 357.3 mm

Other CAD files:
cad/stl/bridgepulse-assembly.stl
cad/stl/bridgepulse-installed.stl
cad/stl/sensor-hub.stl

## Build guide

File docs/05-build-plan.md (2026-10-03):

---
doc_id: BRP-BLD-001
title: BridgePulse prototype build plan
project: BridgePulse
doc_type: Build plan
version: "0.4"
status: Draft
date: '2026-10-02'
author: Amish Chadha
license: CERN-OHL-S-2.0
revisions:
  - version: "0.1"
    date: '2026-09-30'
    author: Amish Chadha
    change: First build plan; design made constructable (BRP-DDR-004)
  - version: "0.2"
    date: '2026-10-01'
    author: Amish Chadha
    change: Budget treated as a value-engineering target; cost line reworded
  - version: "0.3"
    date: '2026-10-02'
    author: Amish Chadha
    change: "Decisions of 2026-10-02: wiring follows the adopted FieldNode pinout; safety stop S8 names the lanyard's girder clamp and crimped banding"
  - version: "0.4"
    date: '2026-10-02'
    author: Amish Chadha
    change: "Approved follow-ups carried out: pad eye, wire lanyard and girder clamp added (new section 3.11, joint 10, step 9; steps renumbered); plate holes, overview, bought parts, bench offcut length and cost updated; all pictures redrawn from the model"
---

# BridgePulse prototype build plan

**Plan, not yet built.** How to build the first proof-of-concept prototype, component by component. Building and testing to it is TRL 4 work. Decisions still to be made are kept in the design decisions register ([docs/06-design-decisions.md](06-design-decisions.md)), not here.

## 1. What you are building

Figure 1. Every component, pulled apart and numbered in build order

*Figure 1. Every component pulled apart and numbered in build order. The FieldNode core (16) is drawn beside the hub; it goes on the handrail post. The lanyard (17) runs from a pad eye on the plate to its own girder clamp.*

The prototype is one BridgePulse monitor fitted to a bench rig that stands in for the middle of the example footbridge: two short offcuts of the girder section, 1.2 m apart, and a stub of the 50 mm square handrail post. At its heart is a sealed die-cast box, the sensor hub, holding an accelerometer board and a signal board. The hub is screwed to an aluminium plate that lies against the girder's web between its flanges, stands on two foot blocks clamped to the bottom flange and is wedged against the top flange by a jack screw, so nothing is drilled into the bridge. A strain gauge under each girder, a dummy gauge on a loose steel coupon beside each, and two temperature probes complete the sensors; cables run to the hub on push-on flange clips, and one cable takes power and data to a FieldNode core on the post. A stainless wire lanyard from a pad eye on the plate to a second girder clamp holds everything if the mount ever lets go. Figure 1 shows the 17 components in the order you make or fit them. Seven are made in a small workshop: the mounting plate, the foot blocks, the clamp jaws and packers, the jack block, the drilled hub box, the dummy gauge coupons and the temperature probes. Everything else is bought, or in the case of the FieldNode core built to its own plan. The work is sawing, drilling, tapping and filing aluminium and steel bar, drilling a die-cast box, potting two small sensors, bonding strain gauges, and wiring bought modules together. The estimated cost of the BridgePulse parts is about $275 from the bill of materials (the value-engineering target is $250), plus the FieldNode core.

> **Safety:** The girder offcuts weigh about 37 kg each: lift them with two people or a hoist and stand them where they cannot tip. Old bridge steel may carry lead paint; test any offcut taken from a bridge before sanding it. Strain gauge adhesives, conditioners and potting epoxy are chemicals: read their safety data sheets, wear gloves and eye protection and ventilate. Cut steel and aluminium edges are sharp: deburr everything. The FieldNode core holds a lithium iron phosphate cell; follow its own plan's safety stops. Fitting the monitor to a real bridge is work at height, outside this plan (section 6, S8).

## 2. What changed to make it buildable

The concept showed what the monitor does; some of its parts could not be made, fixed or fitted as drawn, chiefly because a rolled girder has rounded root fillets where its web meets its flanges. Each change below keeps what the monitor does, and all of them are recorded in decision record BRP-DDR-004, accepted by Amish on 2026-10-02; the lanyard row follows his decision of the same day.

*Table 1. Changes from the concept.*

| Component | The concept had | The buildable design has | Why |
| --- | --- | --- | --- |
| Mounting plate | A 313 mm plate standing on the bottom flange in the corner against the web | A 290.6 mm plate lying on the web, 22 mm clear of each flange (Figure 5) | The plate would have rested on the 18 mm root fillet, not on the flange or the web |
| Foot clamps | A loose block, a spacer and a jaw that would tip about the flange edge | A stepped foot block screwed to the plate, a steel jaw under the flange, a packer outside the edge and one bolt (Figures 5 and 7) | Both ends of the jaw bear; nothing but the jaw is below the girder |
| Jack | A 10 mm tab with no fixing and a screw with no room for its head | A 30 mm jack block screwed to the plate, with the screw's head and lock nut below it (Figure 9) | Enough thread, a spanner from below and a lock |
| Hub to plate | No fixing | Four screws from inside the box into the plate, with sealing washers (Figure 12) | The box stays sealed and its base is clamped to the plate |
| Boards in the hub | Signal board on two posts; accelerometer glued | Both boards on four spacers or standoffs (Figure 14) | Firm four-point fixings, clear of the hub screws and gland nuts |
| Hub penetrations | Two glands and a connector; no way in for the probe leads | Five in one row: two probe glands, two gauge glands, one connector (Figure 13) | Every cable enters through its own seal |
| Temperature probes | A boss stuck to the web; an air probe hanging from nothing | Steel probe under a flange clip; air probe hanging from the far gauge cable (Figure 19 and step 14) | Fixed without drilling or glue on the bridge |
| Dummy coupons | Over the root fillet, fixing not stated | 35 mm out from the web on a bed of silicone (Figure 17) | Same temperature as the girder, none of its strain |
| Cables | "Clips" with nothing to clip to | Push-on spring-steel flange clips and ties (Figure 20) | No drilling |
| FieldNode on the post | V-blocks meant for round poles on a square post | V-blocks left off; plate flat on the post with longer bands (Figure 21) | A flat face seats better on a square post |
| Lanyard | A plain hole in the plate, which a wire could not pass through with the plate flat on the web, and no anchor on the bridge | A stainless pad eye screwed to the plate and a wire lanyard to a second, separate girder clamp on the bottom flange (Figure 22 and step 9) | A second hold on the bridge that shares nothing with the foot clamps |

## 3. Making the components

Make and check each component before the assembly step that needs it. Sizes are in millimetres. "Left" and "right" are as seen standing in front of the hub, looking at its lid. "Front" is the side away from the girder web. Workshop tolerance is 0.5 mm unless a step says otherwise; drawings do not carry tolerances before TRL 4.

### 3.1 Mounting plate

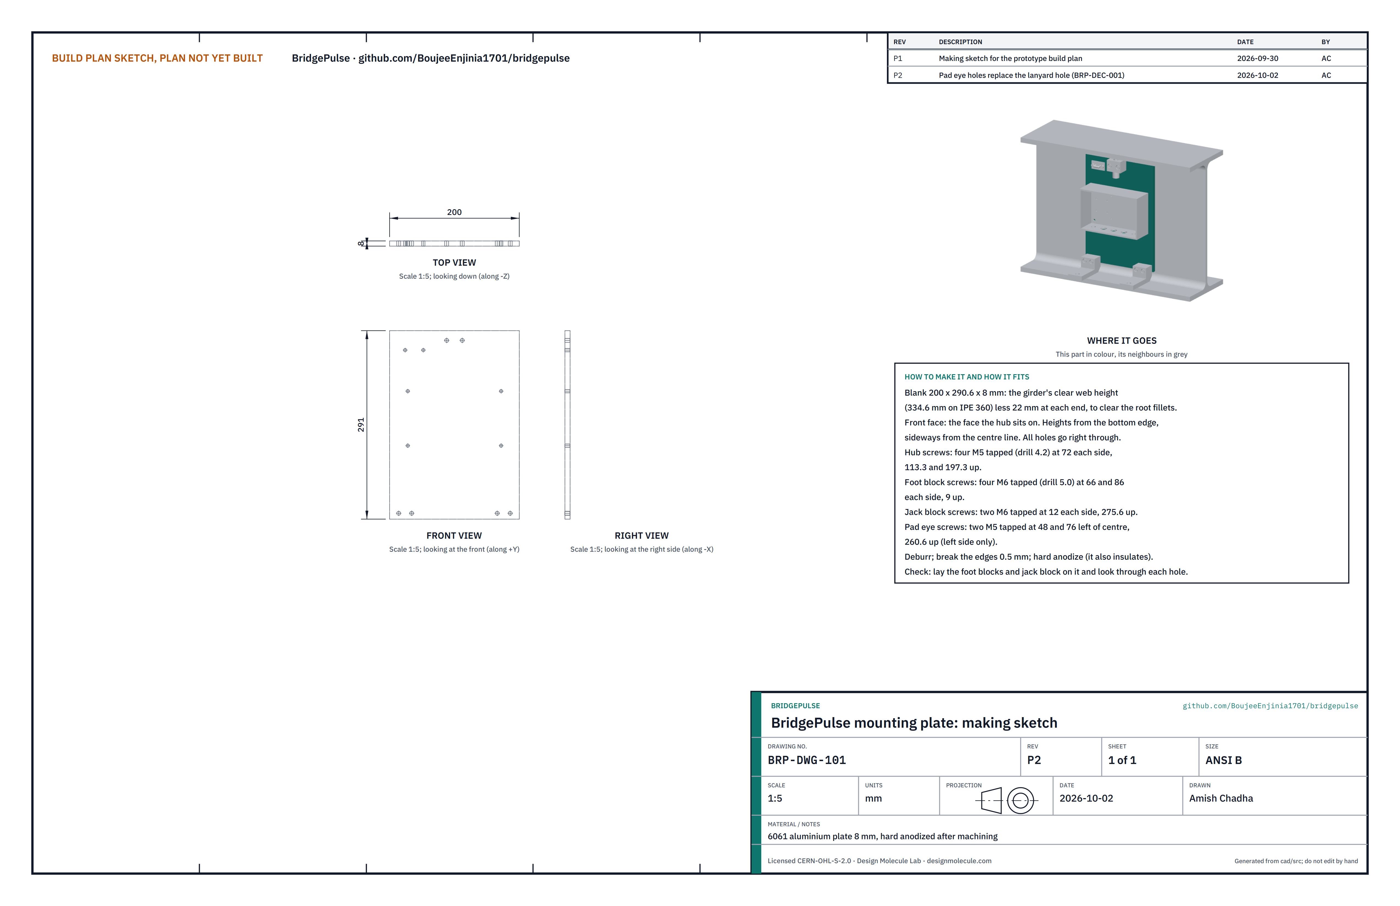
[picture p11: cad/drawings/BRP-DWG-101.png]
Figure 2. Making sketch of the mounting plate


*Figure 2. Mounting plate making sketch (BRP-DWG-101).*

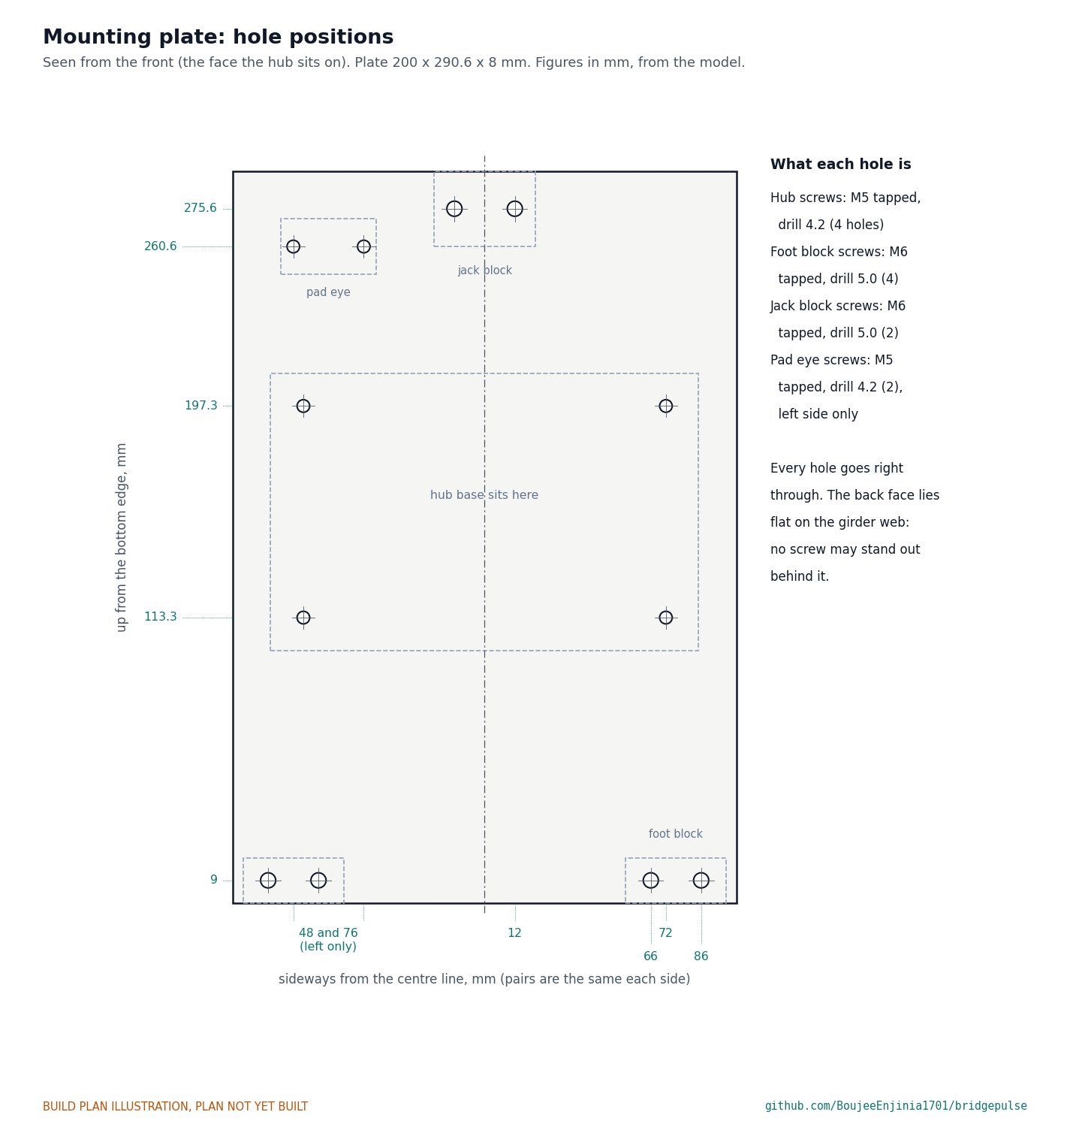
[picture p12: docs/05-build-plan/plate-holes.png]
Figure 3. Hole positions on the mounting plate


*Figure 3. Every hole, measured up from the bottom edge and sideways from the centre line, with the hub, foot blocks, jack block and pad eye outlined.*

**What it is and what it is made from.** The plate everything at the girder hangs on: the hub on its front, the foot blocks at its bottom, the jack block at its top. Its back lies flat on the girder's web. Aluminium plate 8 mm thick, 6061 class, 200 wide; its length is the girder's clear web height (334.6 on an IPE 360) less 22 at each end, 290.6 on the example bridge.

**How to make it.**

1. Measure the clear height between the flanges of the girder it will go on, next to the web. Cut the blank 200 wide and that height less 44 long, square. File the edges and break them 0.5.
2. Scribe a centre line down the long side. Choose one face as the front and mark it.
3. Mark every hole from Figure 3: heights up from the bottom edge, sideways from the centre line.
4. Hub screws: four holes 72 each side of centre, 113.3 and 197.3 up. Drill 4.2 and tap M5 right through.
5. Foot block screws: four holes 66 and 86 each side of centre, 9 up. Drill 5.0 and tap M6 right through.
6. Jack block screws: two holes 12 each side of centre, 275.6 up. Drill 5.0 and tap M6 right through.
7. Pad eye screws: two holes 48 and 76 left of centre, 260.6 up. Drill 4.2 and tap M5 right through.
8. Deburr every hole on both faces; the back must lie flat on the web, so take off every burr there.
9. Have the plate hard anodized. The anodizing protects it and insulates it from the steel.

**How it fits the parts next to it.** The back lies flat on the girder web, with 22 mm between each end and the flange, which clears the rounded root fillets (Figure 5). The foot blocks sit flat on the front at the bottom, the hub's base in the middle from 100.3 to 210.3 up, the jack block at the top and the lanyard's pad eye at the top left. No screw may stand out of the back.

**Check before moving on.** Lay the foot blocks and jack block on it and look through each hole: the holes line up without forcing a screw. Hold the plate against the web of the girder offcut: it fits between the fillets with no rock.

### 3.2 Foot blocks (make 2)

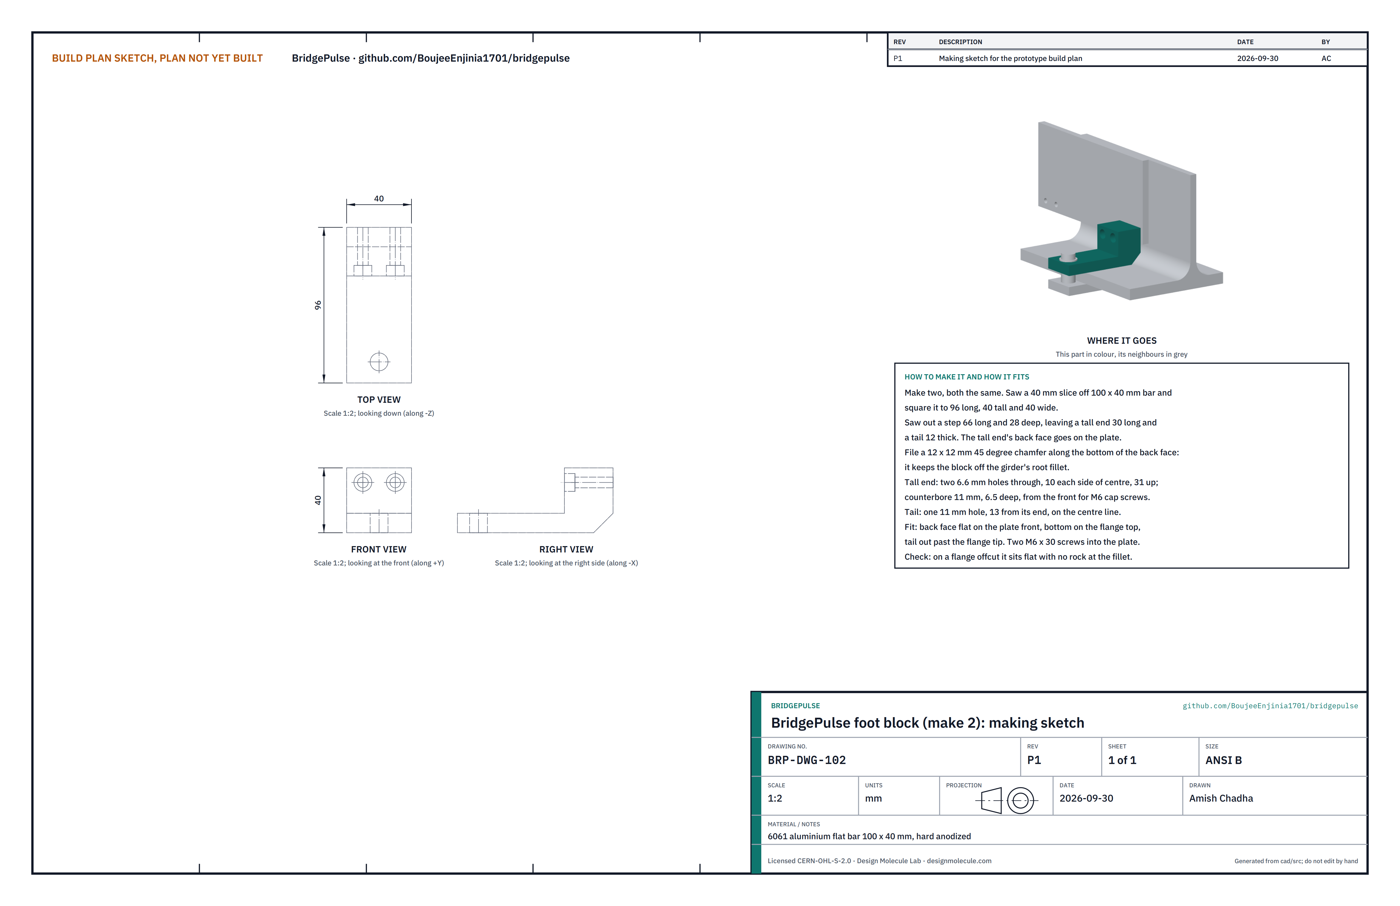
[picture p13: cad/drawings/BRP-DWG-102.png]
Figure 5. Making sketch of the foot block


*Figure 4. Foot block making sketch (BRP-DWG-102).*

**What it is and what it is made from.** A stepped block that the plate stands on: its tall end is screwed to the plate, its tail lies on the bottom flange and is clamped at the flange edge. Aluminium flat bar 100 x 40, 6061 class.

**How to make it.**

1. Saw a 40 slice off the bar and square it to 96 long, 40 tall and 40 wide.
2. Saw out a step 66 long and 28 deep, leaving a tall end 30 long and a tail 12 thick. File the sawn faces flat. The outside face of the tall end is the back face; it goes on the plate.
3. File a 12 x 12 chamfer at 45° along the bottom edge of the back face. This keeps the block off the girder's root fillet.
4. Tall end: drill two 6.6 holes through, front to back, 10 each side of centre and 31 up from the bottom. Counterbore each 11 across and 6.5 deep from the front for an M6 cap screw.
5. Tail: drill one 11 hole, top to bottom, 13 from its end, on the centre line.
6. Deburr and have the blocks hard anodized with the plate.

**How it fits the parts next to it.**

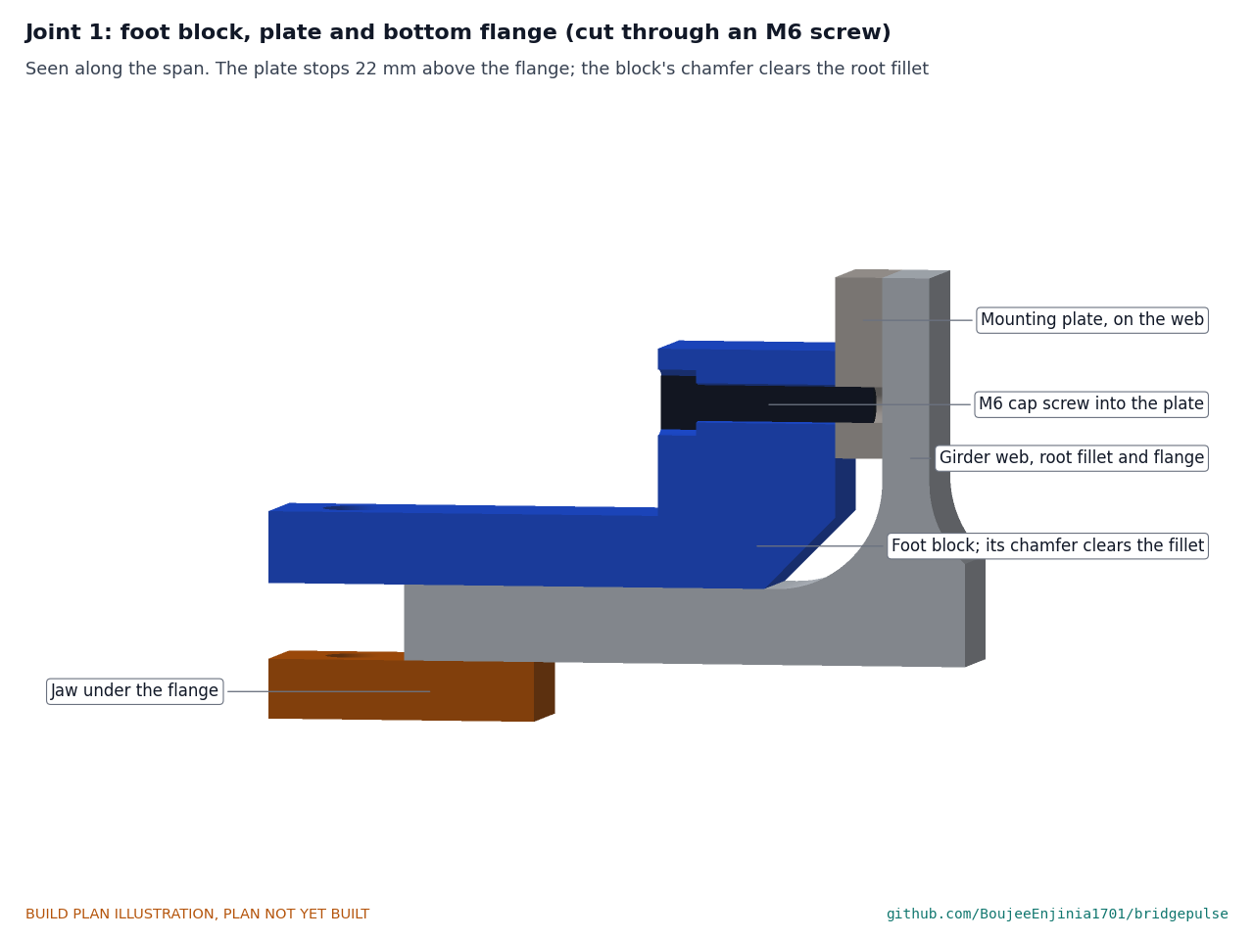
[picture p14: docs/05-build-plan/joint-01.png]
Figure 5. Joint 1: foot block, plate and bottom flange


*Figure 5. Cut through an M6 screw: the plate stops 22 mm above the flange, and the block's chamfer clears the root fillet.*

The back face sits flat on the plate's front, its top 18 above the plate's bottom edge, and is held by two M6 x 30 cap screws into the plate's tapped holes; the screws end 1.5 short of the web. The block's bottom lies on the flange top and its tail runs 23 past the flange edge, where the clamp holds it (section 3.3).

**Check before moving on.** On the girder offcut, with the plate against the web, each block sits flat on the flange with no rock at the fillet.

### 3.3 Clamp jaws and packers (make 2 of each)

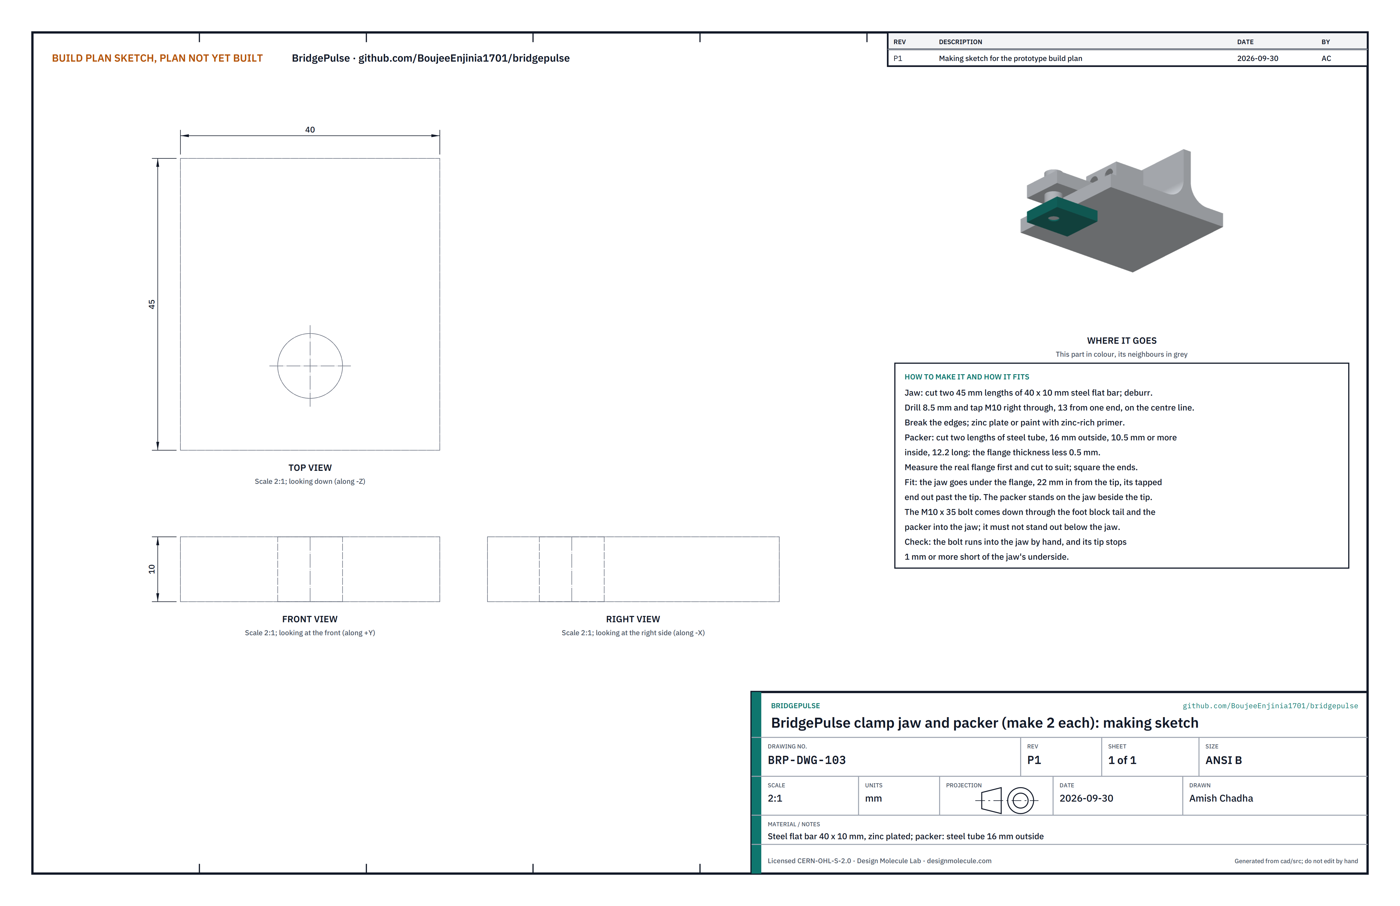
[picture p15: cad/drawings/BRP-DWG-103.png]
Figure 6. Making sketch of the clamp jaw and packer


*Figure 6. Clamp jaw and packer making sketch (BRP-DWG-103).*

**What it is and what it is made from.** The jaw goes under the bottom flange and the packer stands beside the flange edge; one bolt pulls the jaw up and the foot block's tail down, gripping the flange between them. Jaw: steel flat bar 40 x 10, zinc plated. Packer: steel tube 16 outside, 10.5 or more inside.

**How to make it.**

1. Jaw: cut two 45 lengths of the flat bar. Drill 8.5 and tap M10 right through, 13 from one end, on the centre line. Break the edges and zinc plate them, or paint them with zinc-rich primer.
2. Packer: measure the real flange thickness at the flange edge (12.7 on an IPE 360). Cut two lengths of tube 0.5 shorter than that, 12.2 on the example. Square the ends.

**How it fits the parts next to it.**

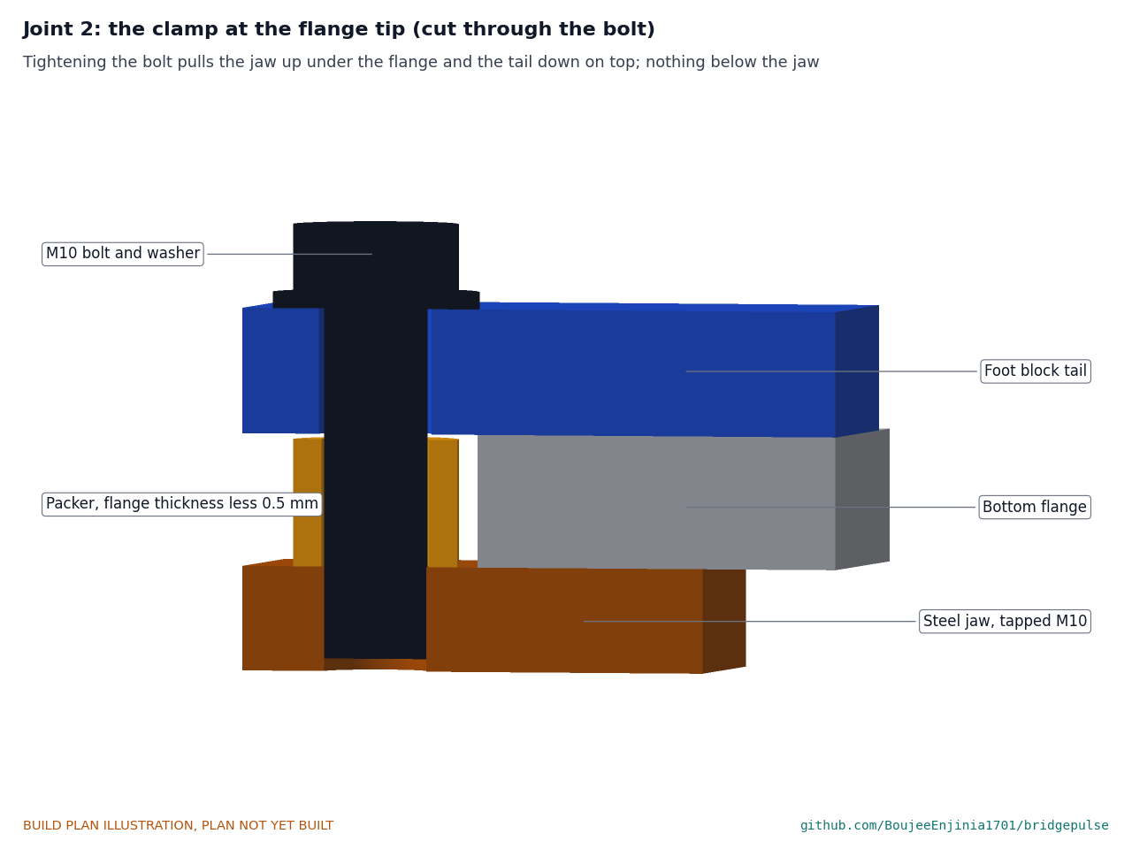
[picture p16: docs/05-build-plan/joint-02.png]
Figure 7. Joint 2: the clamp at the flange edge


*Figure 7. Cut through the bolt: the jaw is under the flange, the packer stands on it outside the flange edge, and the bolt ends inside the jaw.*

The jaw lies under the flange, reaching 22 in from the edge, with its tapped end out past the edge. The packer stands on the jaw around the bolt, 2 clear of the flange edge. An M10 x 35 bolt with a washer comes down through the foot block's tail and the packer into the jaw. Because the packer is 0.5 shorter than the flange, tightening the bolt clamps the jaw to the flange's underside and the tail to its top. The bolt's end stops 1.2 short of the jaw's underside, so nothing but the 10 jaw is below the girder.

**Check before moving on.** The bolt runs into the jaw by hand, and with the jaw on a flat surface the bolt's end does not stand out below it.

### 3.4 Jack block

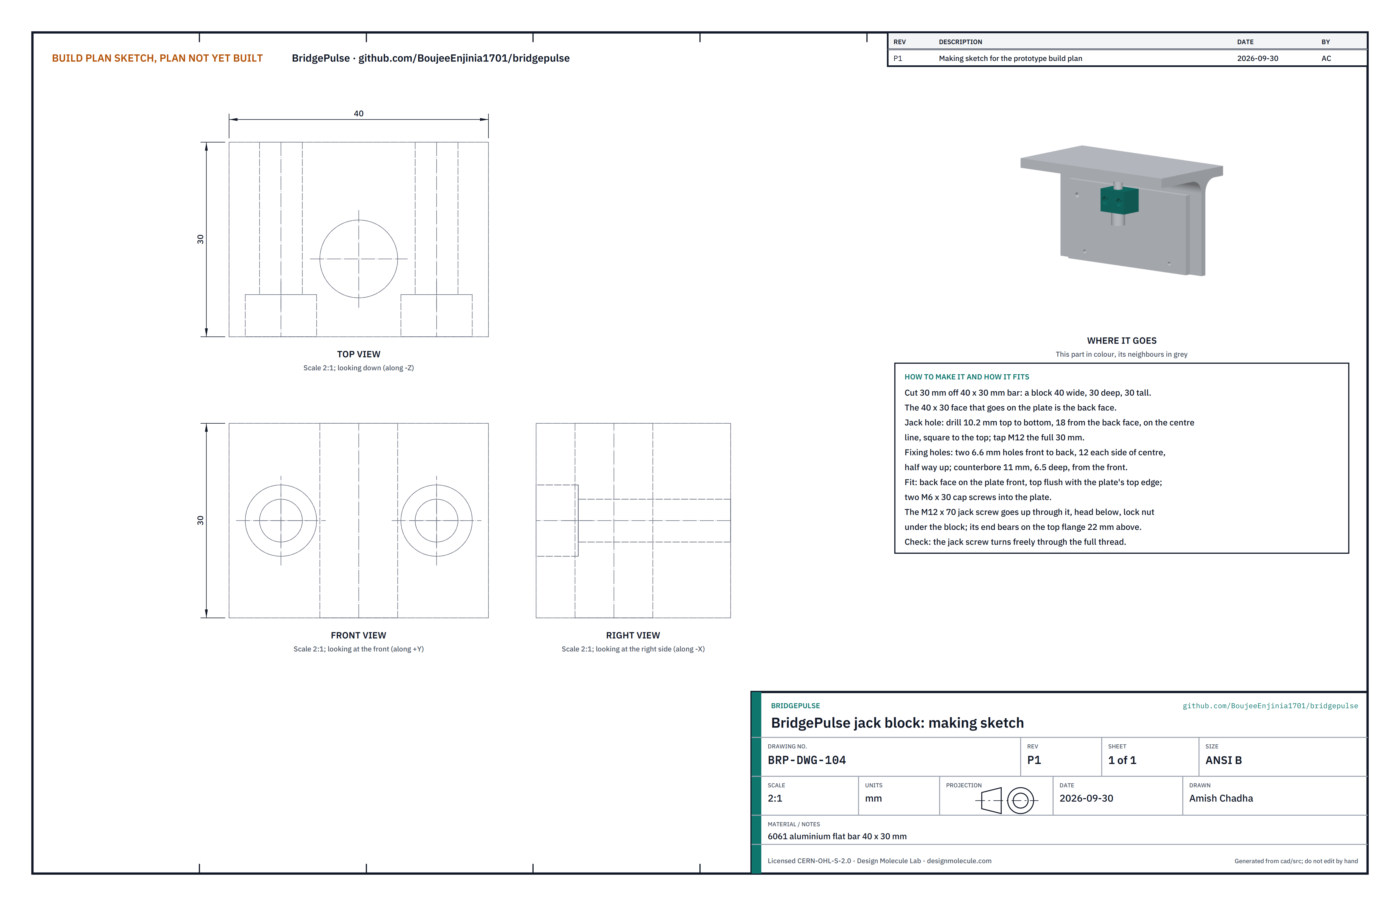
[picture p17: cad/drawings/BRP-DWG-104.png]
Figure 8. Making sketch of the jack block


*Figure 8. Jack block making sketch (BRP-DWG-104).*

**What it is and what it is made from.** The block at the top of the plate that carries the jack screw. Aluminium flat bar 40 x 30, 6061 class.

**How to make it.**

1. Cut 30 off the bar: a block 40 wide, 30 deep and 30 tall. Choose a 40 x 30 face as the back face; it goes on the plate.
2. Jack hole: drill 10.2 top to bottom, 18 from the back face, on the centre line, square to the top. Tap M12 the full 30.
3. Fixing holes: two 6.6 holes front to back, 12 each side of centre and half way up. Counterbore each 11 across and 6.5 deep from the front.
4. Deburr.

**How it fits the parts next to it.**

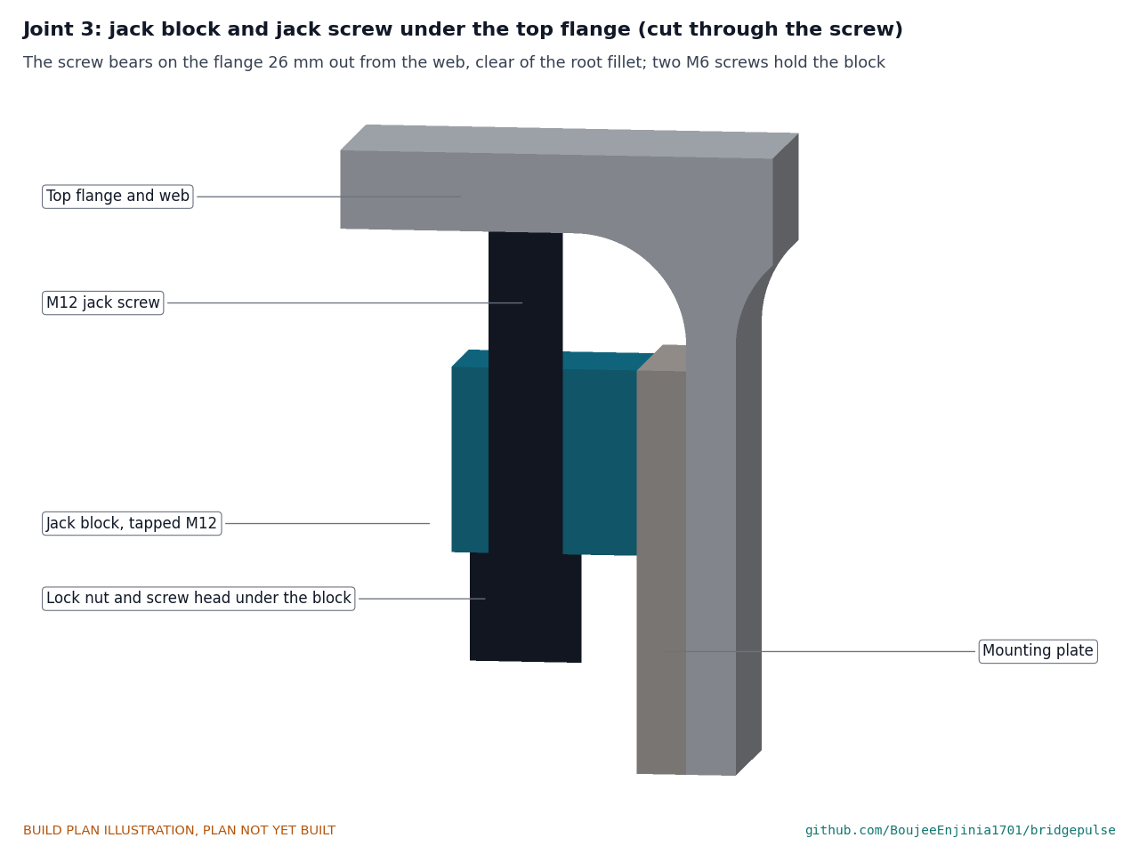
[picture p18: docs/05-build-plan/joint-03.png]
Figure 9. Joint 3: jack block and jack screw under the top flange


*Figure 9. Cut through the jack screw: it bears on the top flange 26 mm out from the web, clear of the root fillet.*

The back face sits on the plate's front with its top flush with the plate's top edge, held by two M6 x 30 cap screws. An M12 x 70 stainless screw goes up through it, head below, with a lock nut under the block. Its end bears on the underside of the top flange, 22 above the block. Winding it up wedges the plate between the flanges; the lock nut holds it there.

**Check before moving on.** The jack screw turns freely through the full thread and the lock nut runs down to the block.

### 3.5 Hub enclosure, drilled, with its glands and connector

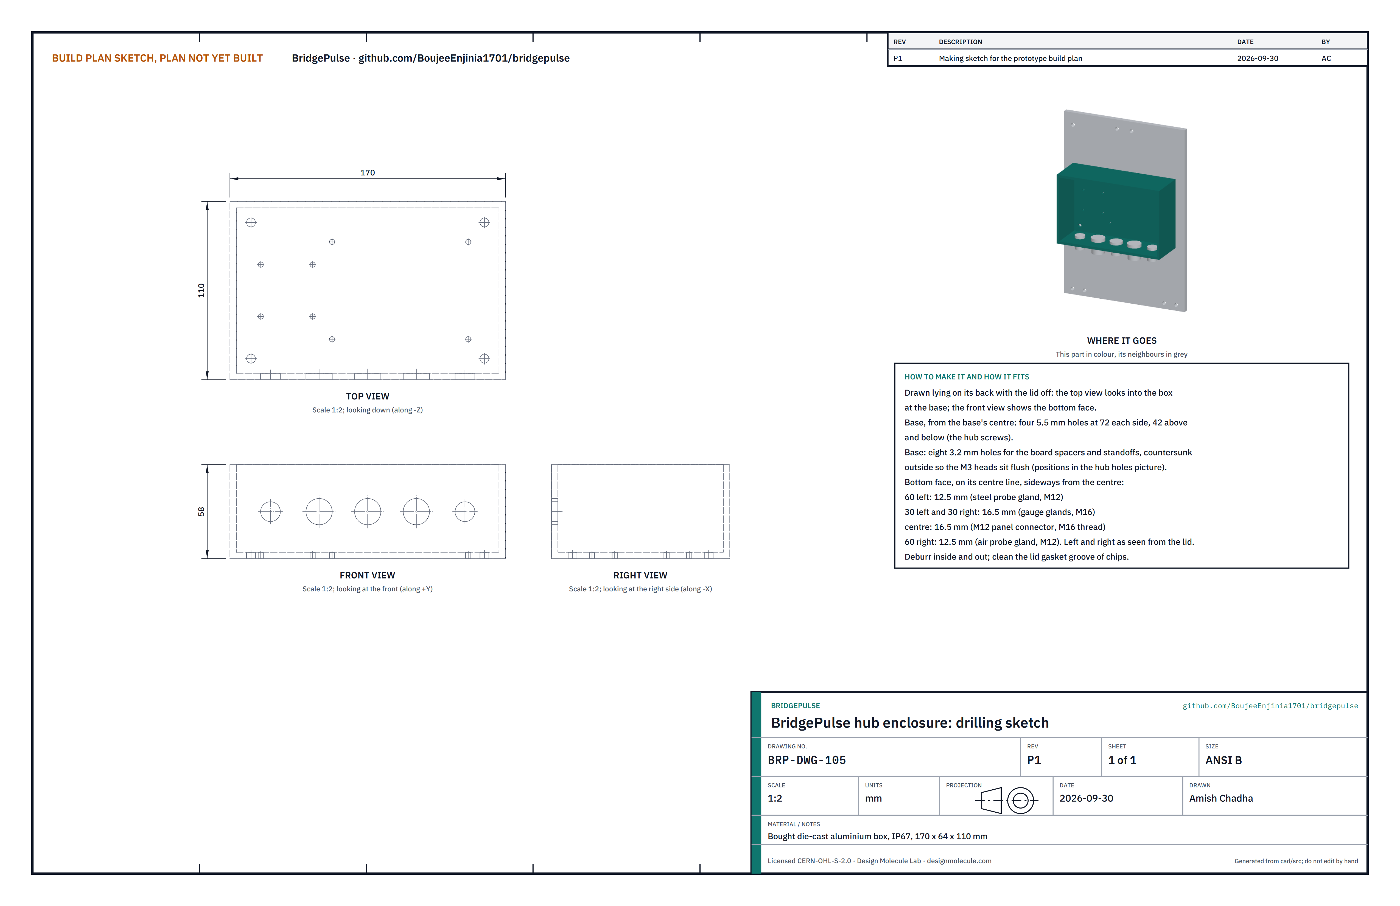
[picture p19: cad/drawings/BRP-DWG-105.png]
Figure 10. Drilling sketch of the hub enclosure


*Figure 10. Hub enclosure drilling sketch (BRP-DWG-105), drawn lying on its back.*

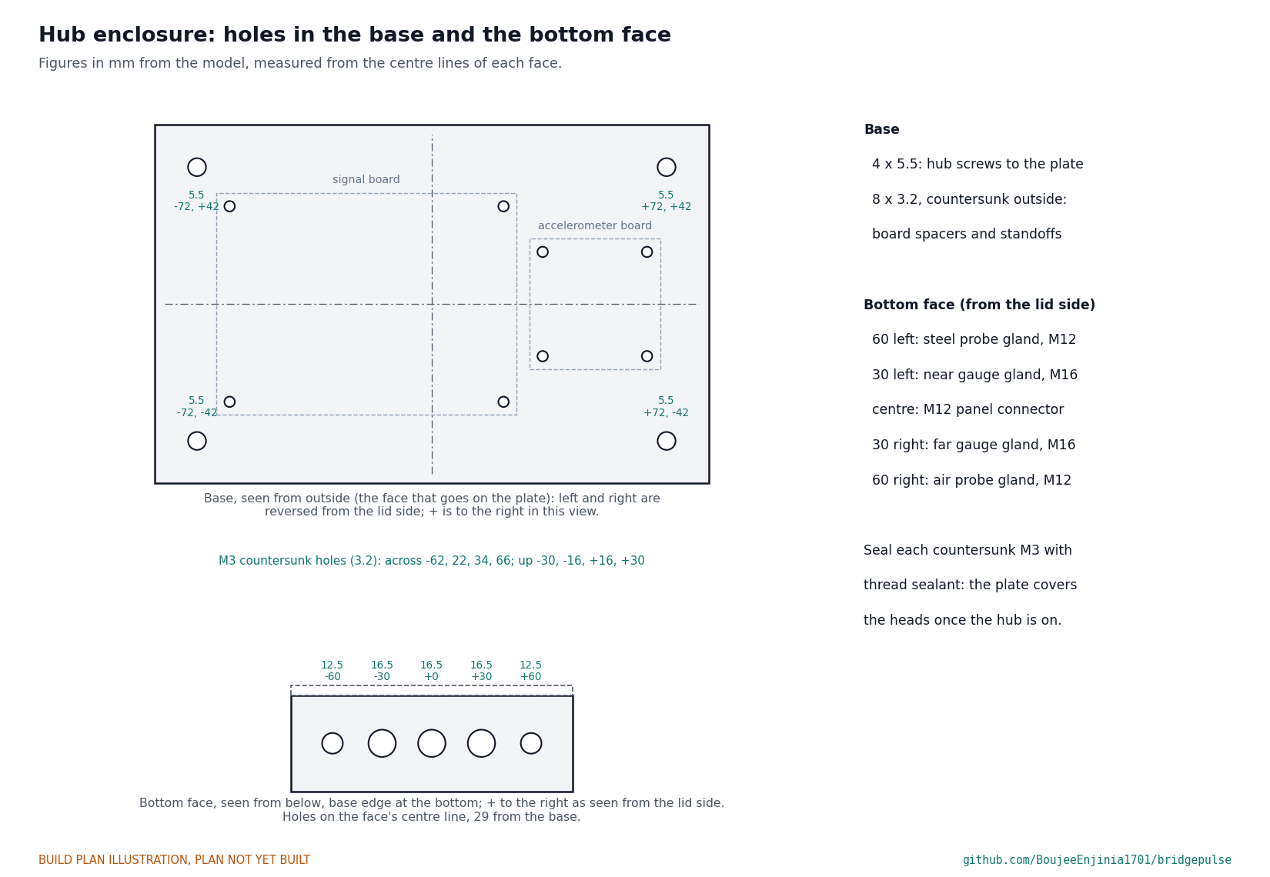
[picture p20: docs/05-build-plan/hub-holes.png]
Figure 11. Holes in the base and the bottom face


*Figure 11. Holes in the base, seen from outside, and in the bottom face, seen from below.*

**What it is and what it is made from.** A bought die-cast aluminium box, 170 wide, 64 deep and 110 tall, rated IP67, with a gasketed lid. Its base, the large face opposite the lid, is screwed flat to the plate; its bottom face takes the five penetrations.

**How to make it.**

1. Take the lid off and keep its screws. Lay the box on a soft cloth.
2. Base, from Figure 11: four 5.5 holes at 72 each side of the base's centre, 42 above and below it (the hub screws). Eight 3.2 holes for the board spacers and standoffs, countersunk from outside so M3 countersunk heads sit flush. Mind that Figure 11 shows the base from outside, so left and right are reversed.
3. Bottom face, on its centre line, 29 from the base: a 12.5 hole 60 left of centre (steel probe gland), 16.5 holes 30 left and 30 right (gauge glands), a 16.5 hole at the centre (panel connector) and a 12.5 hole 60 right (air probe gland). Pilot drill each 3, then open out with a step drill. Check each size against the part's datasheet before the last step.
4. Deburr inside and out and clean every chip out of the box and the lid's gasket groove.
5. Fit the five penetrations from below, seal outside and nut inside, to the maker's torque: M12 glands at 60 left and right, M16 glands at 30 left and right, the M12 5-pin panel connector in the centre.
6. Fit the eight board spacers and standoffs inside the base on M3 countersunk screws from outside, with a drop of thread sealant on each: four 5 metal spacers for the accelerometer board on the left, four 14 standoffs for the signal board to the right.

**How it fits the parts next to it.**

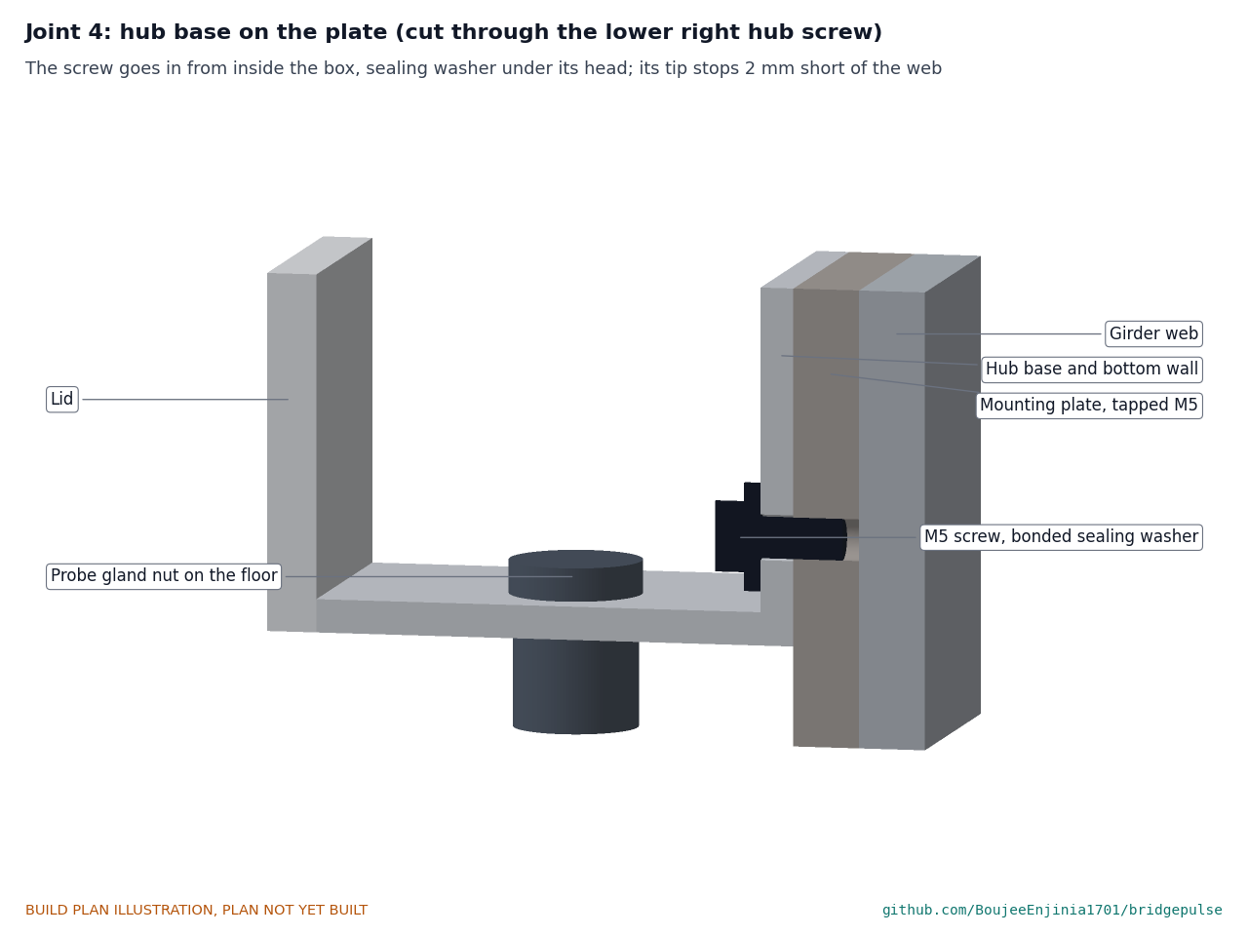
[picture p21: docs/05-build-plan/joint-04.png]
Figure 12. Joint 4: hub base on the plate


*Figure 12. Cut through a hub screw: it goes in from inside the box, with a bonded sealing washer under its head, and its tip stops 2 mm short of the web.*

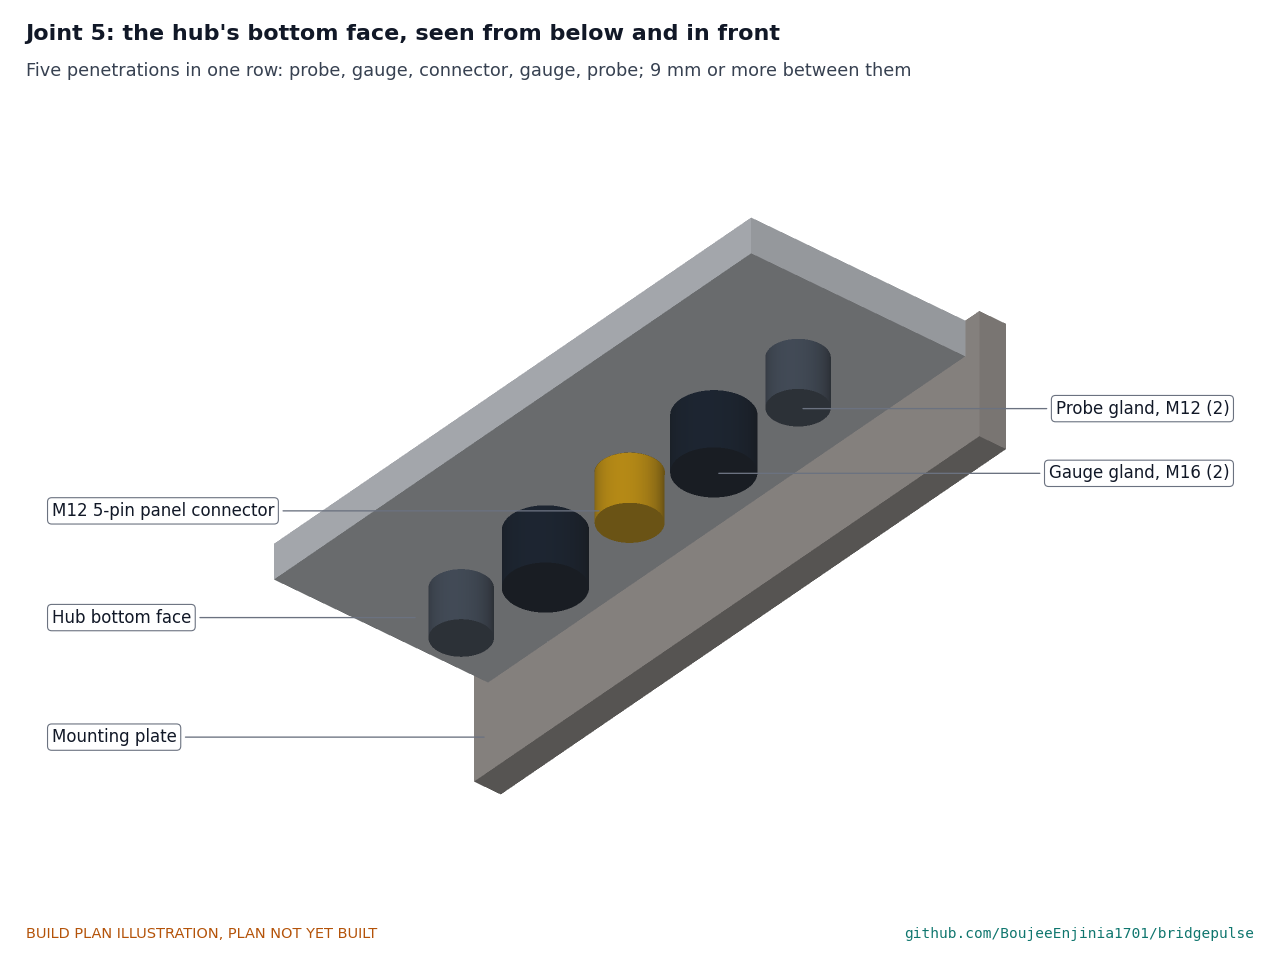
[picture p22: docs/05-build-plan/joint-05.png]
Figure 13. Joint 5: the bottom face


*Figure 13. The five penetrations, 9 mm or more apart.*

The base lies flat on the plate's front, centred, from 100.3 to 210.3 up the plate. Four M5 x 12 screws go from inside the box through the base into the plate, each with a bonded sealing washer under its head. Once the hub is on, the plate covers the countersunk M3 heads. The front face of the closed hub is 9 inside the line of the flange edge, so the hub sits inside the girder's outline.

**Check before moving on.** Every penetration seats evenly on its seal; the base sits flat on the plate with all four screw holes lined up; the lid closes on a clean gasket.

### 3.6 Boards in the hub

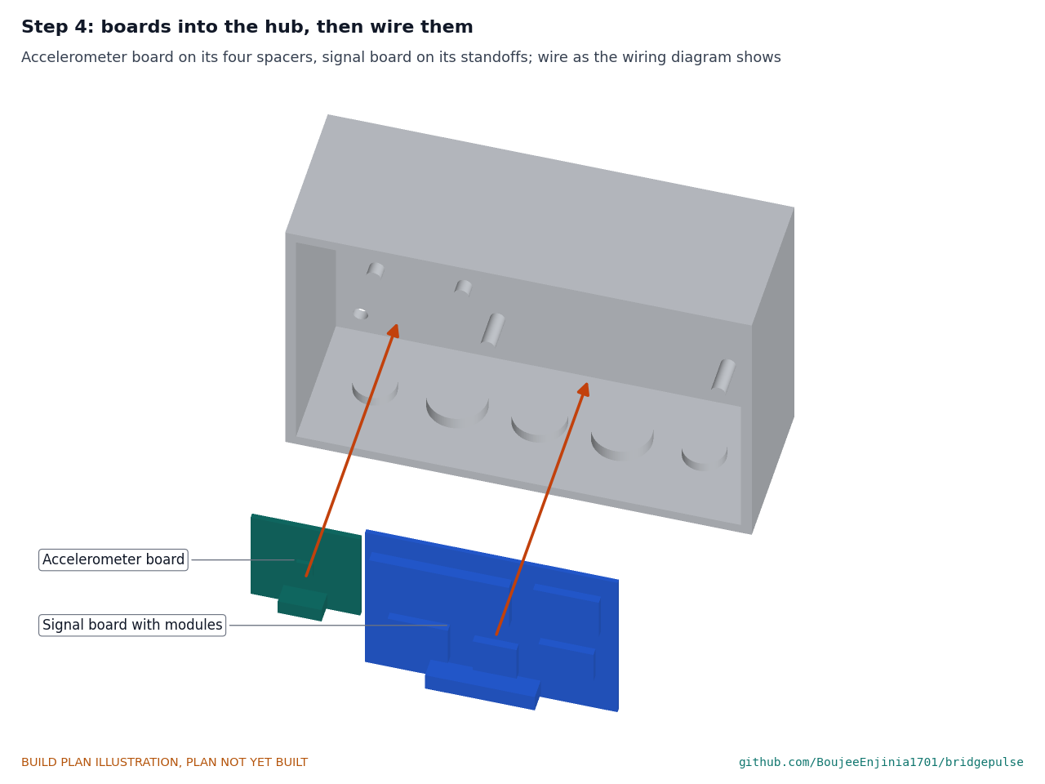
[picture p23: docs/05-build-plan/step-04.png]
Figure 14. Step 4 picture: boards into the hub


*Figure 14. The accelerometer board goes on the four short spacers on the left, the signal board on the four standoffs on the right.*

**What it is and what it is made from.** Bought modules: an ADXL355 class accelerometer board and a signal board made up of an RP2040 class controller board, a 24-bit bridge ADC module (ADS1220 class), a 5 V to 3.3 V buck converter, an RS-485 transceiver module, a microSD socket with a 32 GB card, the bridge completion resistors, an excitation switch and a terminal block, all on a 92 x 68 perforated carrier board.

**How to make it.**

1. Lay the modules out on the carrier board as Figure 14 shows: controller top left, ADC module top right, RS-485 module below it, buck converter lower left, microSD socket lower middle, terminal block along the bottom edge.
2. Drill the carrier's four 3.2 corner holes, 4 in from each edge, to match the standoffs.
3. Fit the modules on short M2.5 or M3 standoffs or solder them in, and wire them as Figure 15 shows (section 3.6.1).
4. Fit the accelerometer board on its four spacers and the carrier on its four standoffs, with M3 screws from inside.

#### 3.6.1 Wiring

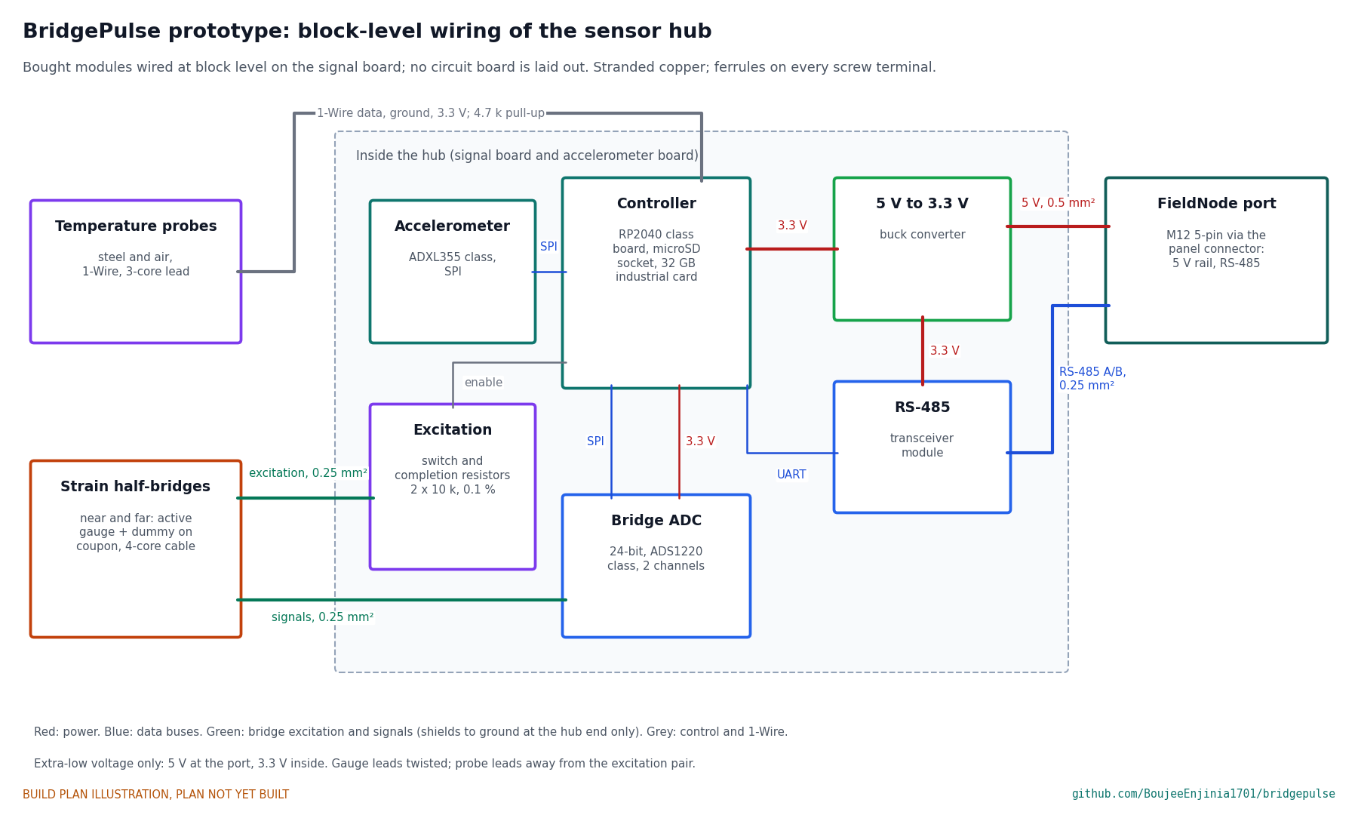
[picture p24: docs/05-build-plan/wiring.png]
Figure 15. Block-level wiring of the hub


*Figure 15. Block-level wiring with wire sizes. No circuit board is laid out at this stage; bought modules stand in for it.*

Wire it like this, with stranded copper and a ferrule on every screw terminal:

1. Panel connector, switched 5 V rail and ground, to the buck converter's input: 0.5 mm² (20 AWG).
2. Buck converter's 3.3 V output to the controller, the ADC module, the RS-485 module and the accelerometer board: 0.5 mm².
3. Panel connector's two RS-485 pins to the RS-485 module's A and B: 0.25 mm² (24 AWG), twisted. The pin assignment follows the FieldNode pinout adopted as the shared standard (pin 1 switched 5 V rail, pins 2 and 4 RS-485 A and B, pin 3 ground, pin 5 analog; Modbus RTU).
4. Controller to the RS-485 module (UART), to the ADC module and to the accelerometer board (SPI): short 0.25 mm² leads.
5. Controller output to the excitation switch's enable input: 0.25 mm².
6. Each gauge cable at the terminal block: excitation pair from the excitation switch, signal pair to the ADC module through the completion resistors, shield to ground at the hub end only.
7. Both probe leads at the terminal block on one 1-Wire bus: data to a controller pin with a 4.7 k pull-up to 3.3 V, ground and 3.3 V.

**Check before moving on.** Every wire continues end to end; with nothing connected, the 5 V and 3.3 V rails read open to ground; every wire is labelled.

### 3.7 Dummy gauge coupons (make 2)

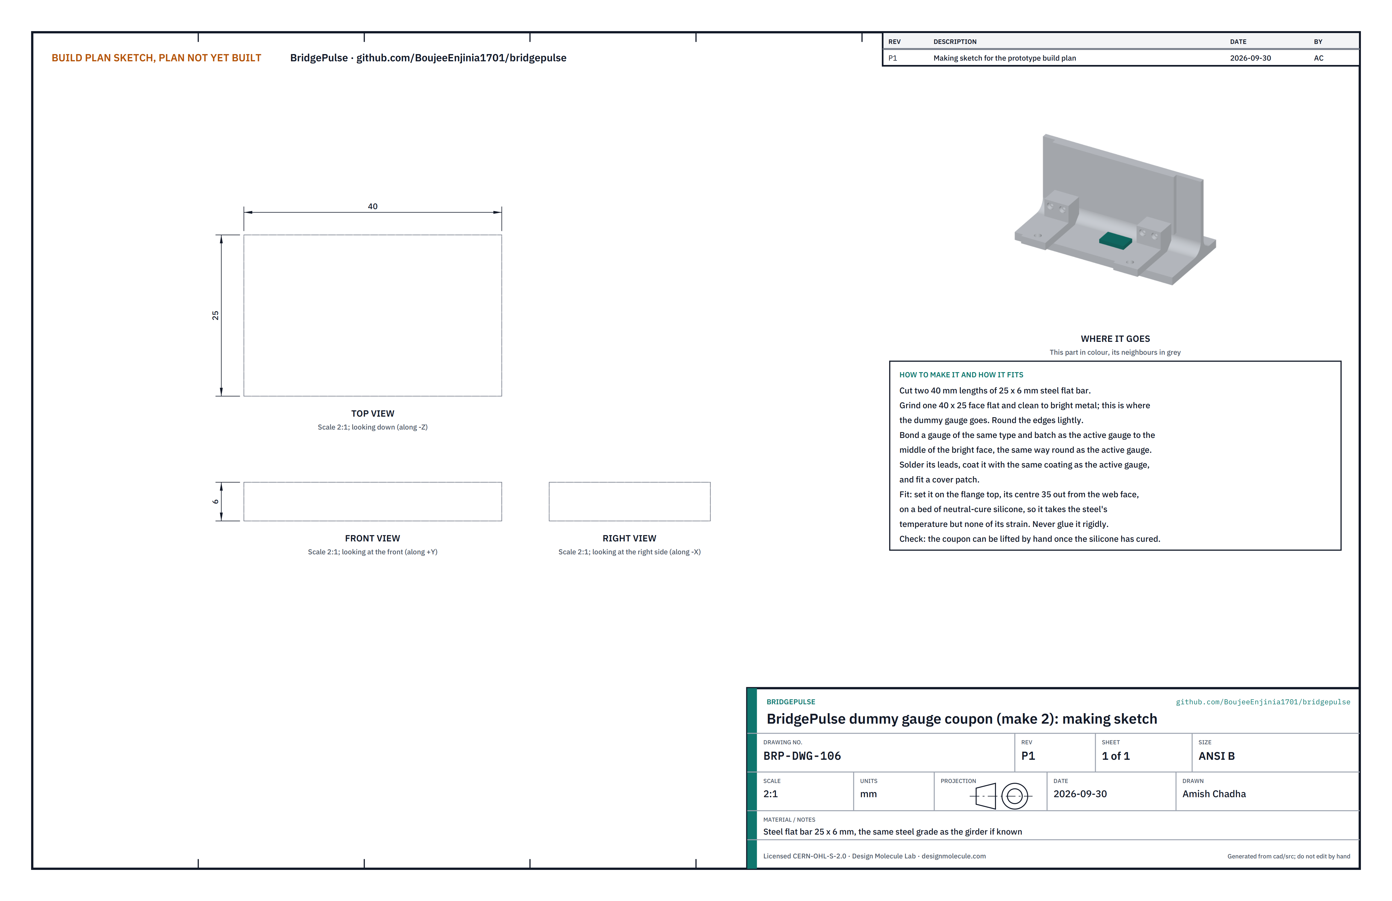
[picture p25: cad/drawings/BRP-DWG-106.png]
Figure 16. Making sketch of the dummy gauge coupon


*Figure 16. Dummy gauge coupon making sketch (BRP-DWG-106).*

**What it is and what it is made from.** A small loose piece of steel carrying a second gauge that sees the girder's temperature but none of its strain, so the half-bridge cancels temperature. Steel flat bar 25 x 6, the same grade as the girder if known.

**How to make it.**

1. Cut two 40 lengths of the flat bar. Round the edges lightly.
2. Grind one 40 x 25 face flat and clean it to bright metal.
3. Bond a gauge of the same type and batch as the active gauge to the middle of that face, the same way round, following the gauge maker's procedure.
4. Solder its leads, coat it with the same coating as the active gauge and fit a cover patch.

**How it fits the parts next to it.**

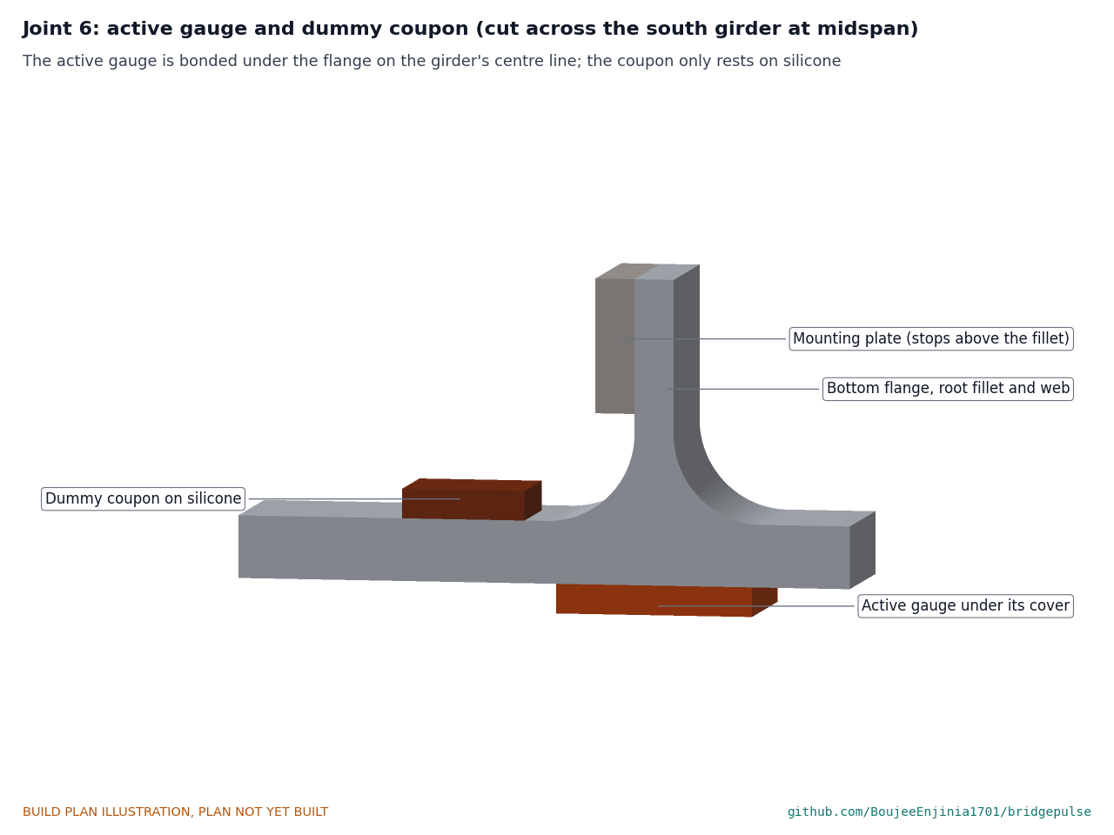
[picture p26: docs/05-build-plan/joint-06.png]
Figure 17. Joint 6: active gauge and dummy coupon


*Figure 17. Cut across the south girder at midspan: the active gauge under the flange, the coupon on the flange top.*

The coupon lies on the top of the bottom flange, its centre 35 out from the web face (clear of the root fillet), on a bed of neutral-cure silicone that holds it in place without passing strain into it. Never glue it rigidly.

**Check before moving on.** Once the silicone has cured, the coupon can be lifted by hand.

### 3.8 Temperature probes (make 2)

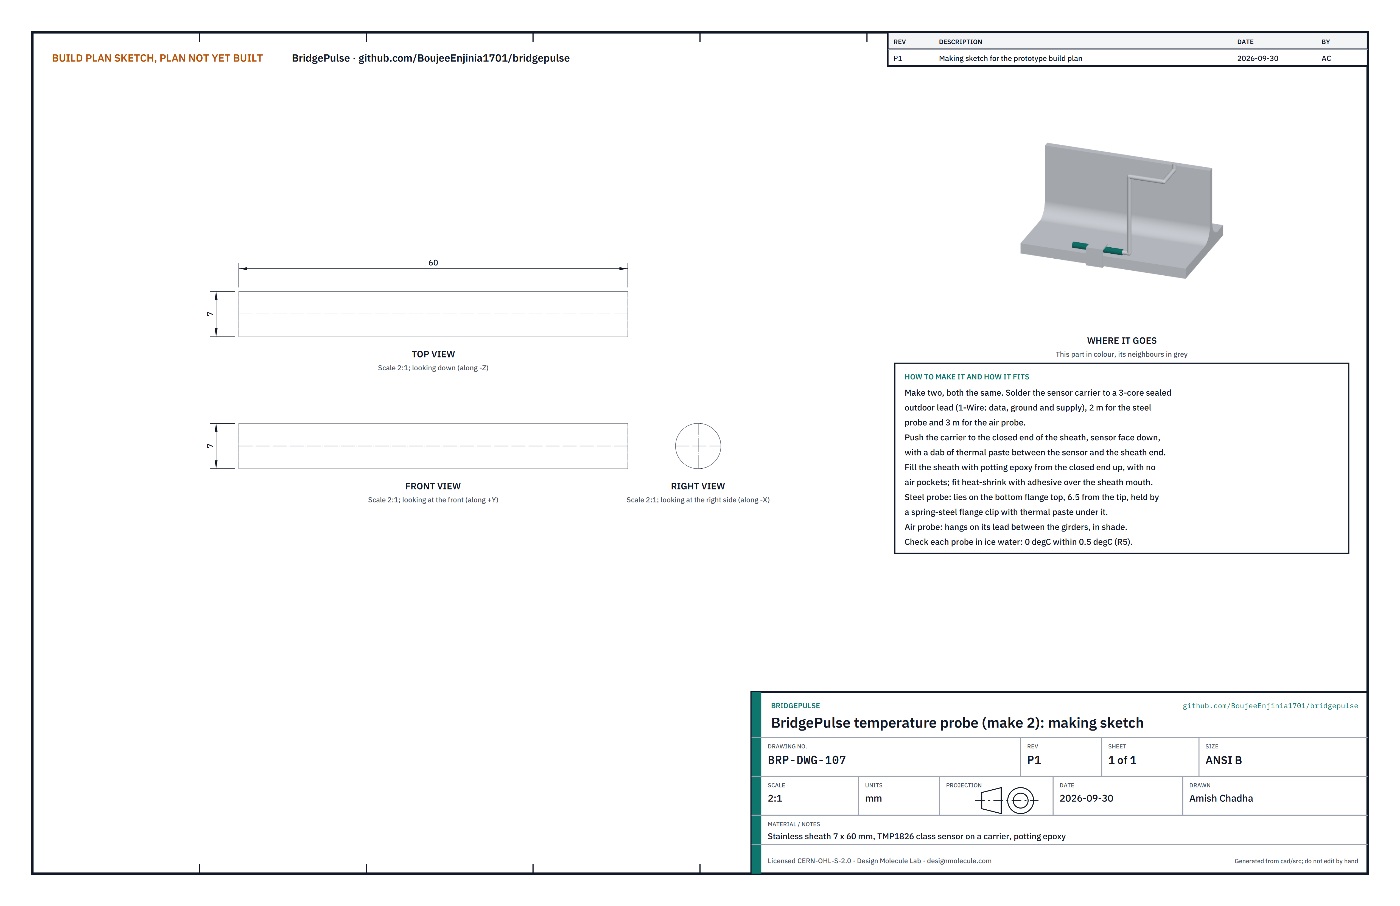
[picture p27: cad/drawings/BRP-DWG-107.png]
Figure 18. Making sketch of the temperature probe


*Figure 18. Temperature probe making sketch (BRP-DWG-107).*

**What it is and what it is made from.** A TMP1826 class digital temperature sensor on a small carrier, potted in a stainless sheath 7 across and 60 long, with a sealed outdoor lead. One measures the steel, one the shaded air.

**How to make it.**

1. Solder the sensor carrier to a 3-core sealed outdoor lead: about 2 m for the steel probe and 3 m for the air probe.
2. Push the carrier to the closed end of the sheath, sensor face down, with a dab of thermal paste between the sensor and the sheath.
3. Fill the sheath with potting epoxy from the closed end up, with no air pockets. When it has cured, fit adhesive-lined heat-shrink over the sheath's mouth and the lead.

**How it fits the parts next to it.**

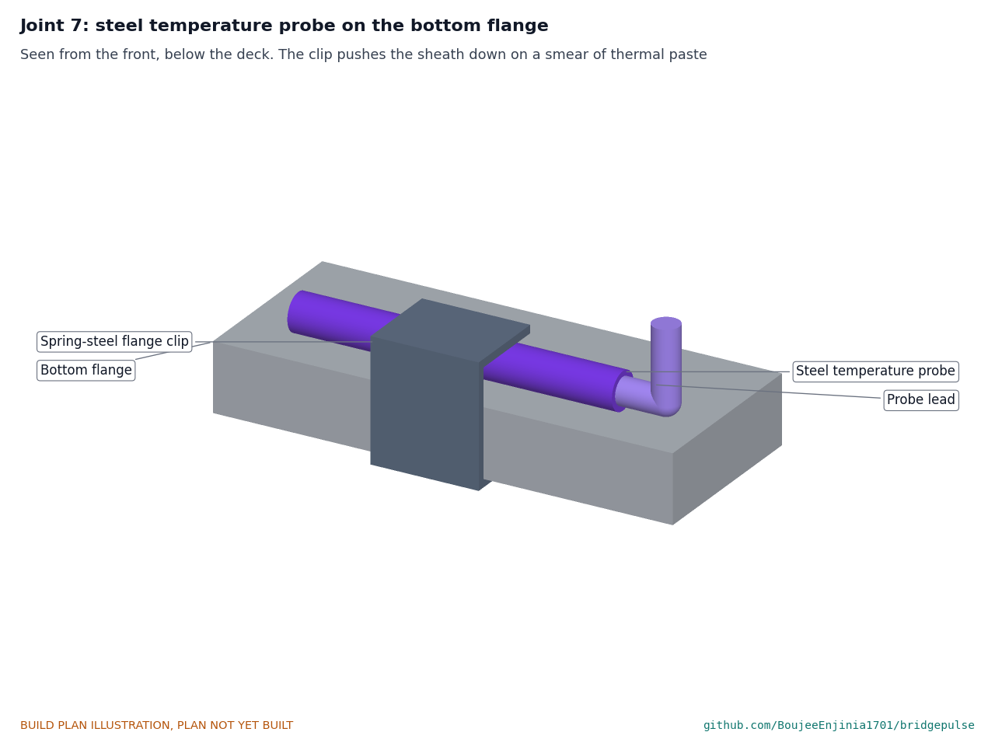
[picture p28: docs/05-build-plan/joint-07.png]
Figure 19. Joint 7: steel probe on the bottom flange


*Figure 19. The steel probe lies on the bottom flange, 6.5 mm in from its edge, under a push-on flange clip.*

The steel probe lies along the top of the bottom flange, 140 left of centre and 6.5 in from the flange edge, on a smear of thermal paste, held down by a spring-steel flange clip pushed onto the flange edge. Its lead runs up to the hub's left probe gland. The air probe hangs on its lead in the shade between the girders (step 14).

**Check before moving on.** Put both probes in a bath of crushed ice and water with a reference thermometer: each reads 0 °C within 0.5 °C (R5).

### 3.9 Cables, clips and the M12 cable (bought)

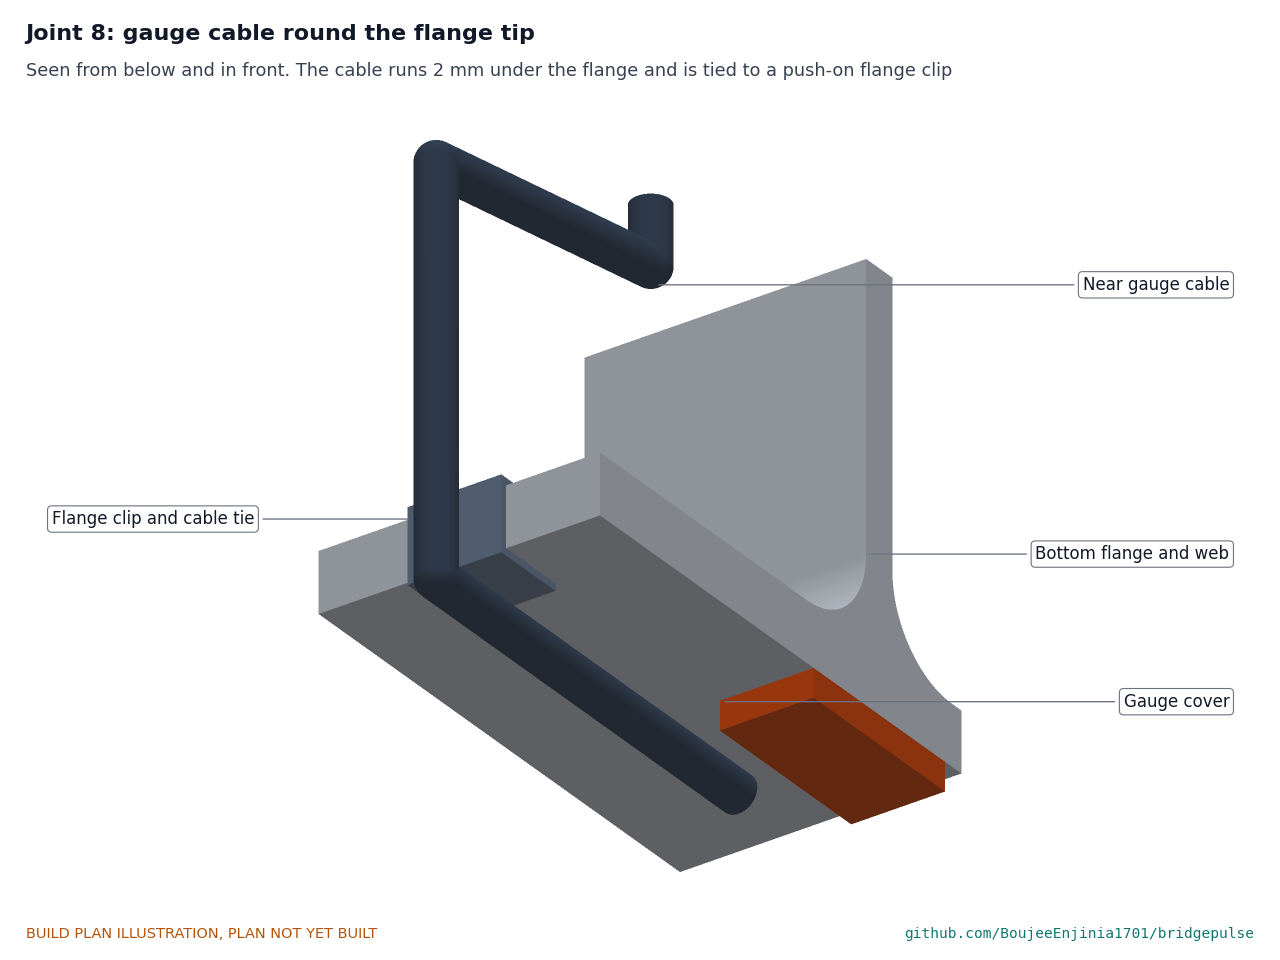
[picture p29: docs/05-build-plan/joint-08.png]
Figure 20. Joint 8: gauge cable round the flange edge


*Figure 20. The near gauge cable leaves the gauge cover, runs 2 mm under the flange and round its edge, tied to a push-on flange clip.*

**What it is.** Two shielded 4-core outdoor gauge cables, one moulded M12 5-pin cable about 2 m long from the hub's panel connector to the FieldNode port, five push-on spring-steel flange clips for 10 to 16 flanges (one of them holds the steel probe) and UV-stable cable ties. Nothing is drilled.

**How it fits.** Each gauge cable leaves its gauge cover, runs under the bottom flange clipped 2 below it, turns round the flange edge on a flange clip, rises beside the edge and goes into its gland from below: the near cable into the left gauge gland and the far cable into the right one. The far cable crosses between the girders under the deck, 3 inboard of each flange edge. The M12 cable leaves the panel connector, runs out past the flange edge, rises beside the post and plugs into the FieldNode's port B.

### 3.10 FieldNode core (built to its own plan)

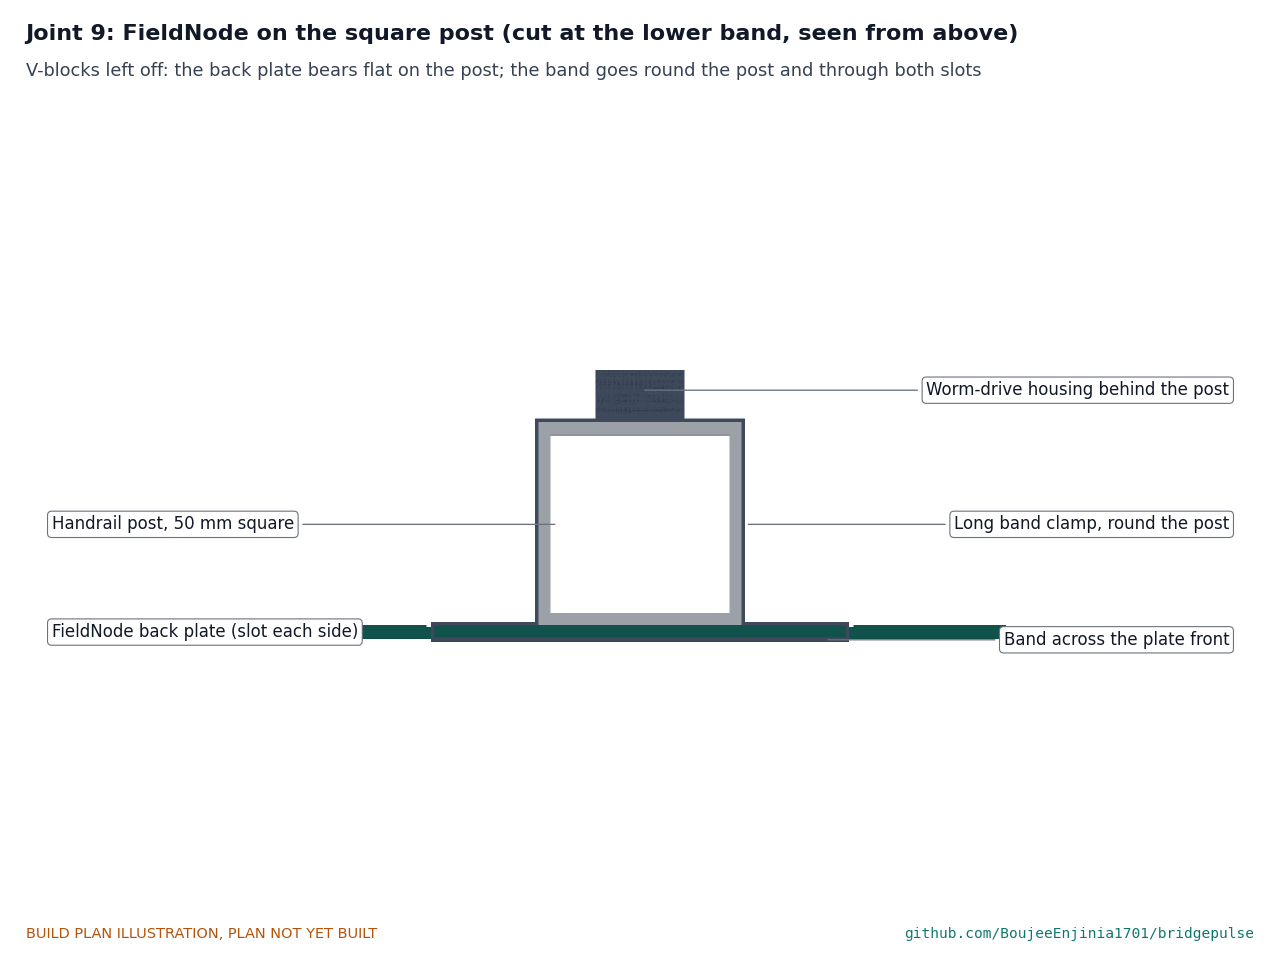
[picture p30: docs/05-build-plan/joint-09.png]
Figure 21. Joint 9: FieldNode on the square post


*Figure 21. Cut at the lower band, seen from above: the back plate flat on the post, the band round the post and through both slots.*

**What it is.** The lab's shared power and radio node: a sealed box with a cell, charger, LoRaWAN radio and two M12 sensor ports, a 6 W solar panel on a bracket above it, and a back plate with band clamps. Build it to its own plan, FND-BLD-001, with two differences for a square handrail post:

1. Leave the two V-blocks off. Their screw holes in the back plate stay empty.
2. Buy its two band clamps one size longer, with a band of about 300 to 330 mm, since each band goes round the 50 mm post, through both slots in the back plate and across its front.

**How it fits.** The back plate bears flat on the post's outer face, with the box base 450 above the deck. Each band goes round the post, along the back of the plate to a slot, through it, across the plate's front and back through the other slot; its worm-drive housing sits behind the post.

**Check before moving on.** Each band closes on the post with adjustment to spare, and the node does not turn on the post when pushed by hand.

### 3.11 Lanyard and its girder clamp (bought)

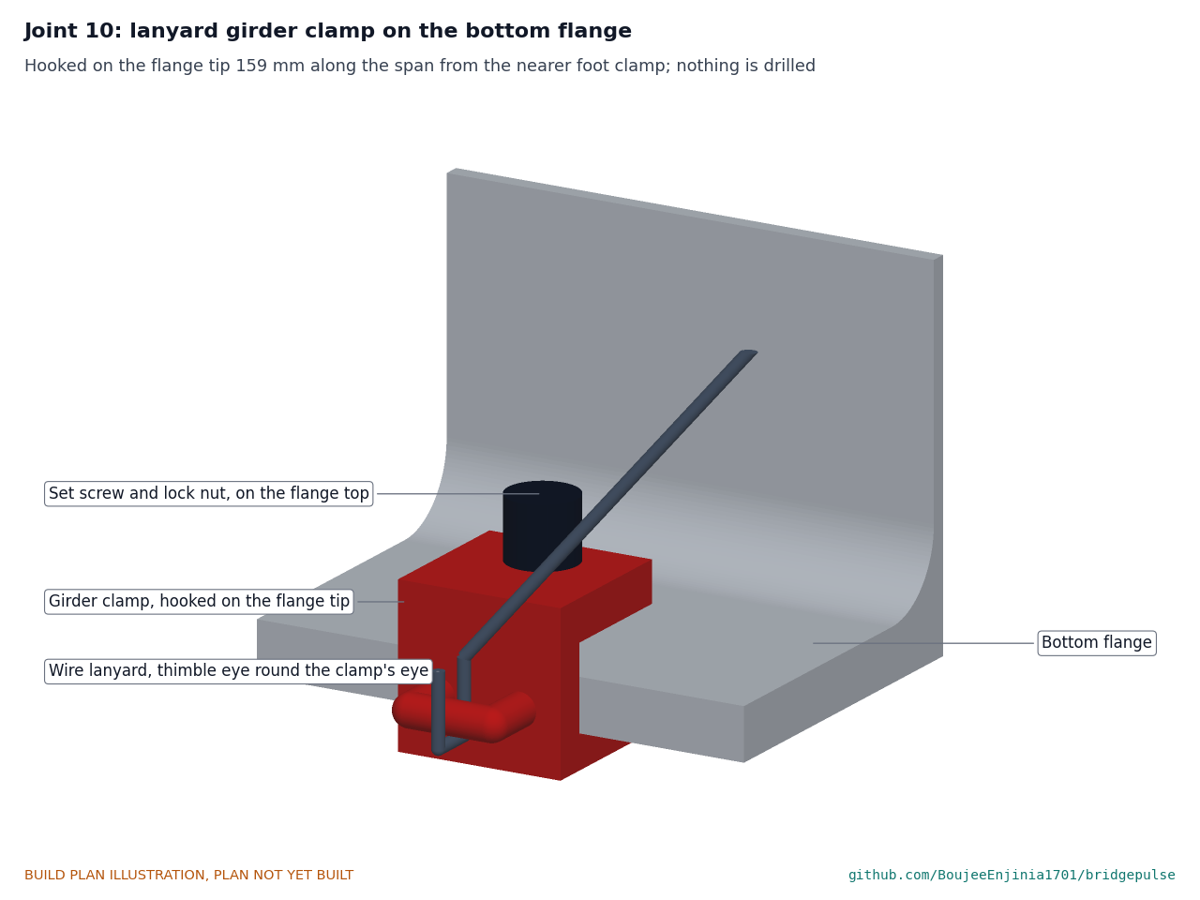
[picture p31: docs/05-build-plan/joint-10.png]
Figure 22. Joint 10: lanyard girder clamp on the bottom flange


*Figure 22. The girder clamp hooked on the edge of the bottom flange, its set screw on the flange top and the lanyard's eye round the clamp's eye.*

**What it is.** The second hold on the bridge, in case the foot clamps or the jack ever let go. Three bought parts: a stainless pad eye with a 38 x 22 base and two M5 x 10 screws; a 3 mm stainless wire lanyard about 0.45 m long with a thimble eye and a crimped ferrule at each end; and a single-flange girder clamp with an eye, a set screw and a lock nut, whose maker rates it for a working load of 100 kg or more.

**How it fits.** The pad eye is screwed to the plate's front at the top left, above the hub, into the two tapped holes of section 3.1, its screws ending 1.5 short of the web. The girder clamp hooks over the edge of the bottom flange with its lower jaw under the flange, 150 or more along the span from the nearer foot clamp (159 on the example) on the left, and its set screw is tightened down onto the flange top and locked. One end of the lanyard goes round the pad eye's loop and the other round the clamp's eye. The lanyard runs straight past the left end of the hub with no more than 25 of slack, since the slack sets how hard the lanyard is snatched if the mount lets go.

**Check before moving on.** The clamp cannot be pulled off the flange by hand; the lanyard clears the hub and every cable; the slack is 25 or less.

### 3.12 Bought components

Buy to specification, not brand. Line numbers are those of the bill of materials.

- **Hub enclosure (line 1).** Die-cast aluminium box, IP67, 170 x 64 x 110 outside, gasketed lid; two M16 x 1.5 nylon glands for 4 to 8 cable and two M12 x 1.5 glands for 3 to 6.5 cable, each IP68.
- **Accelerometer board (line 2).** ADXL355 class, 22.5 µg/√Hz, SPI, on a breakout with four mounting holes; four 5 metal spacers.
- **Signal board (line 3).** As section 3.6; four 14 standoffs; bridge completion resistors 10 k, 0.1 %.
- **Mounting fixings and lanyard (line 4).** Stainless: one M12 x 70 hex screw and one M12 nut; two M10 x 35 hex bolts and washers; six M6 x 30 cap screws; four M5 x 12 screws with bonded sealing washers; nylon isolating washers. Lanyard: as section 3.11.
- **Strain gauges (line 5).** Four 350 Ω foil gauges self-temperature-compensated for steel, from one batch; cyanoacrylate gauge adhesive; surface preparation kit; gauge coating and four cover patches about 60 x 40; neutral-cure silicone.
- **Temperature probes (line 6).** Two TMP1826 class sensors on carriers, two stainless sheaths 7 x 60, sealed 3-core lead, potting epoxy, adhesive-lined heat-shrink.
- **Cables and clips (line 7).** As section 3.9, and the M12 5-pin panel connector (rear mounting, M16 thread).
- **FieldNode core (line 8).** As section 3.10.
- **microSD card (line 9).** 32 GB, rated -25 to +85 °C.
- **Installation banding (line 10, installed units only).** Two lengths of 12.7 x 0.76 stainless banding, about 0.4 m each, with two one-way crimped buckles, which replace the FieldNode's worm-drive band clamps on a bridge open to the public. The bench unit keeps the worm-drive bands. Fitting it needs a banding tool.
- **Bench rig (not in the bill of materials).** Two offcuts of the girder section about 650 long (IPE 360 on the example bridge), long enough for the lanyard's girder clamp, set up on the bench 1.2 m apart, centre to centre; a 1.5 m stub of 50 x 50 x 3 square hollow section held upright in a stand.

## 4. Putting it together

In each picture the parts already fitted are grey and the part being fitted is in colour, with an arrow showing the way it goes in.

### Step 1: foot blocks onto the plate

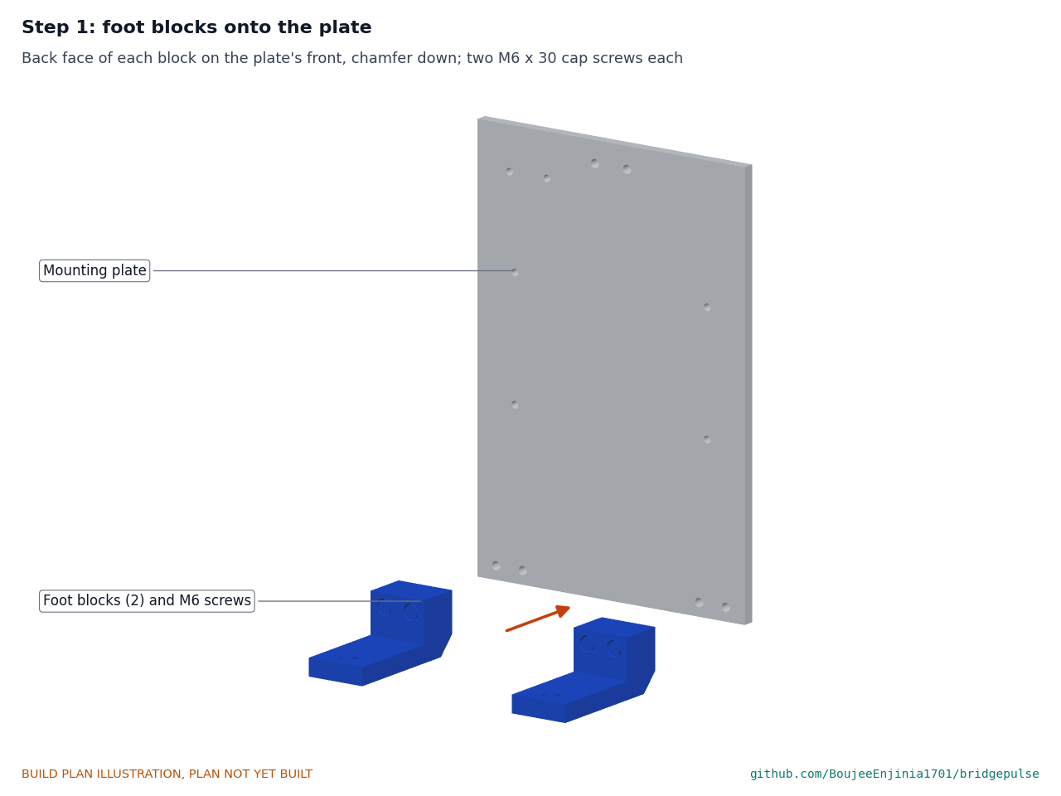
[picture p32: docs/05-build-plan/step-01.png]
Step 1


Lay the plate front up. Put each foot block's back face on the plate's front at the bottom, chamfer down, and fit two M6 x 30 cap screws, tight.

### Step 2: jack block and jack screw onto the plate

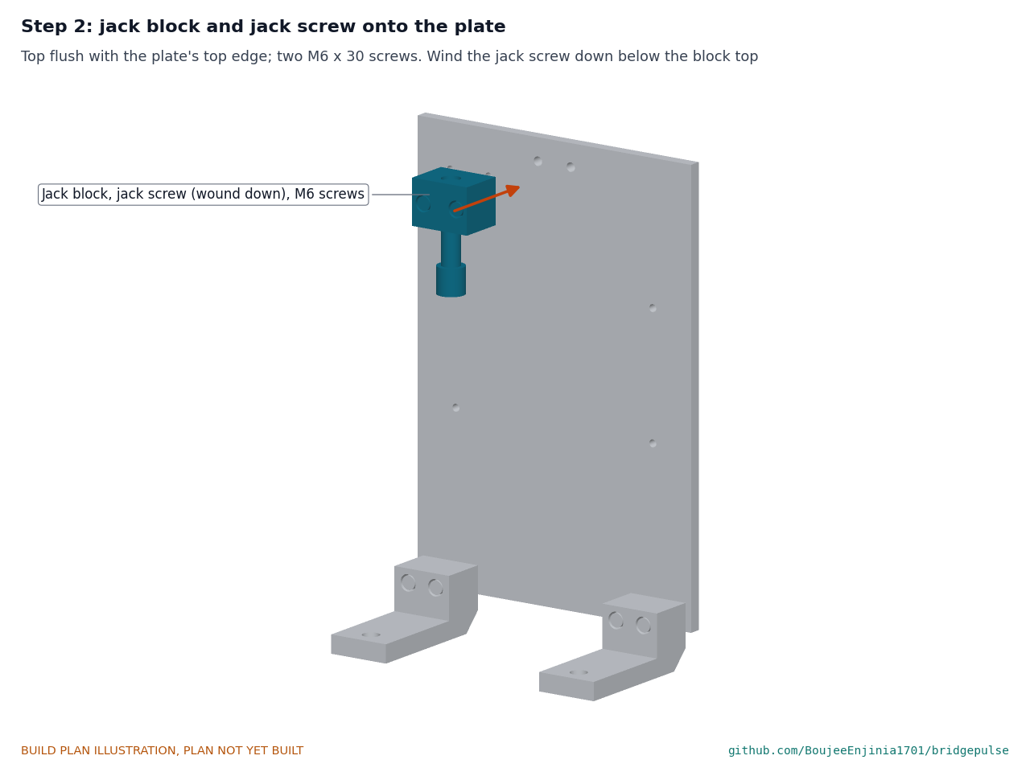
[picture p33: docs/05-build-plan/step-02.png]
Step 2


Fit the jack block at the top of the plate's front, its top flush with the plate's top edge, with two M6 x 30 cap screws. Run the lock nut onto the M12 screw, then screw it up into the block from below until its end is just below the block's top.

### Step 3: glands, connector, spacers and standoffs into the hub

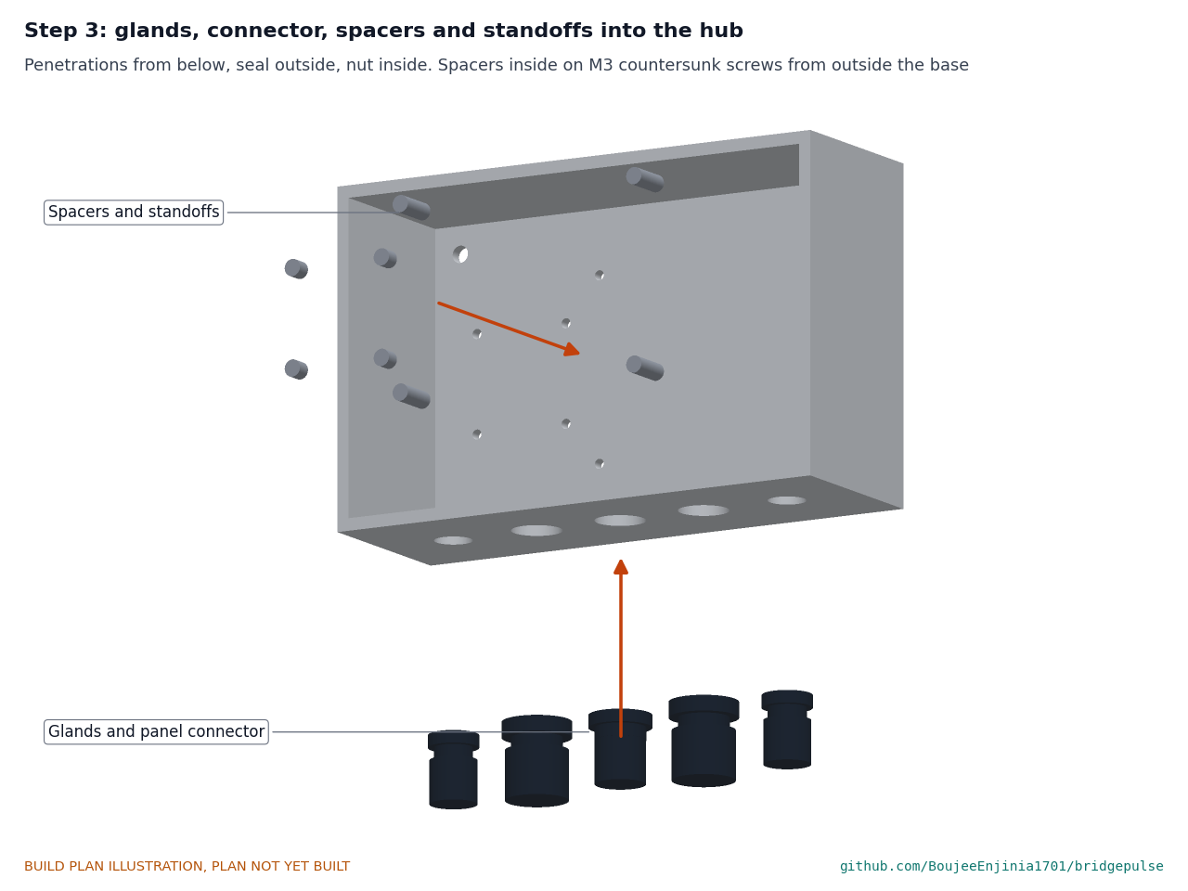
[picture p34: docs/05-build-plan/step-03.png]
Step 3


As section 3.5, steps 5 and 6. Fit blanking plugs in any gland whose cable is not yet ready.

### Step 4: boards into the hub, then wire them

Step 4

Fit the accelerometer board and the signal board, and wire them as Figure 15. **Hold point:** the wiring checks of section 3.6 pass.

### Step 5: plate onto the girder

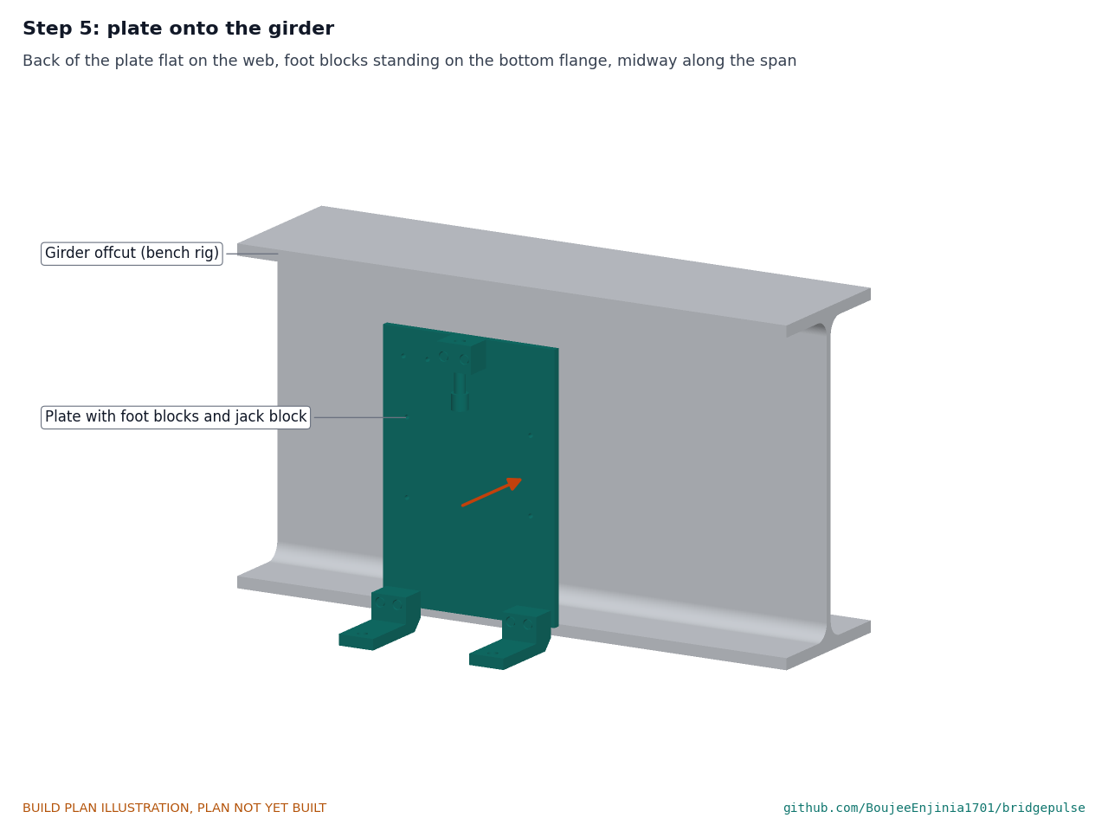
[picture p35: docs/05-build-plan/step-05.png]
Step 5


Hold the plate with its back flat on the outer face of the south girder's web, its foot blocks standing on the bottom flange, midway along the offcut.

### Step 6: clamp the foot blocks to the flange

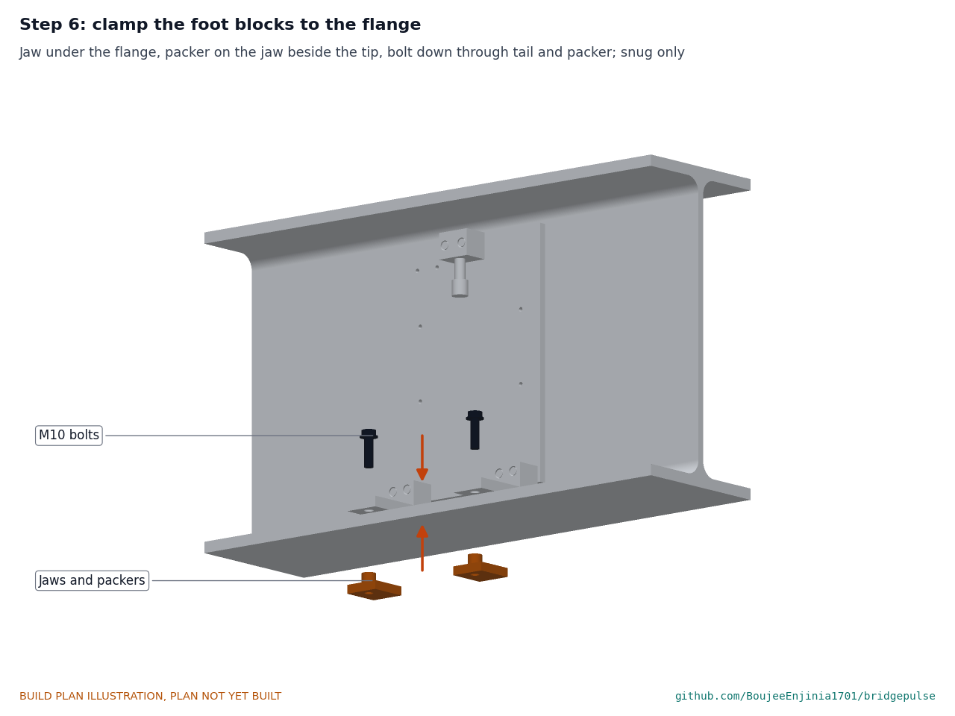
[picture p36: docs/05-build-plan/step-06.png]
Step 6


For each block, slide a jaw under the flange with its tapped end out past the flange edge, stand a packer on the jaw beside the edge, and fit an M10 x 35 bolt and washer down through the tail and the packer into the jaw. Snug only.

### Step 7: jack screw up to the top flange

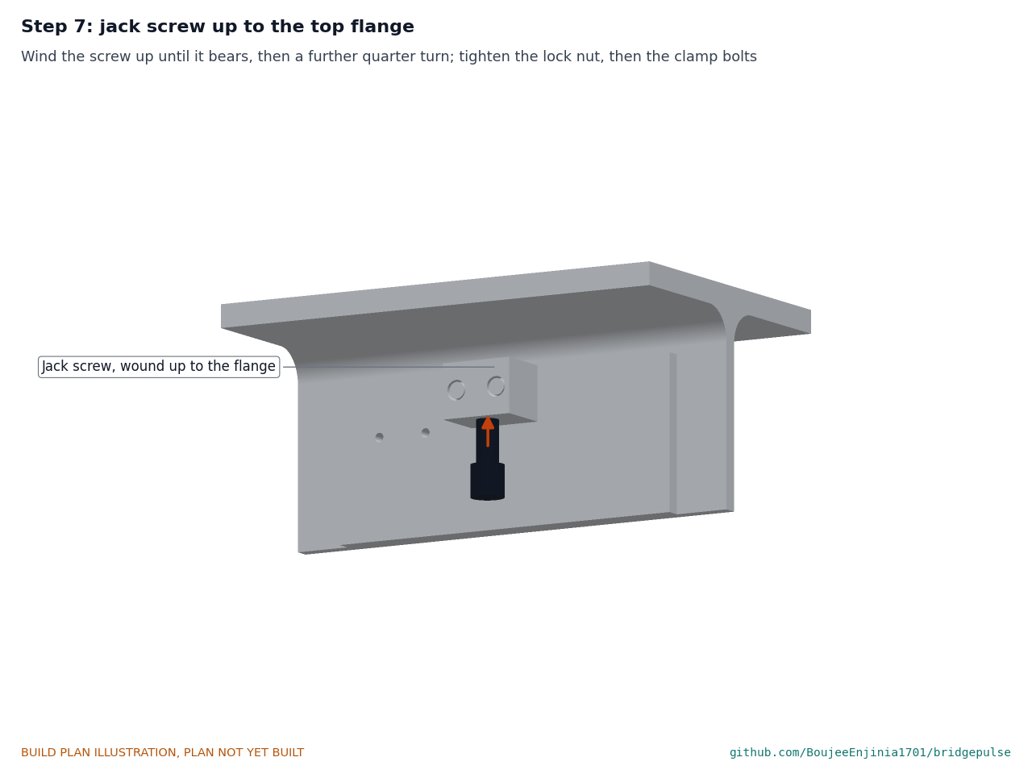
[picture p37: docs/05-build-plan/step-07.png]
Step 7


Wind the jack screw up until its end bears on the top flange, then a further quarter turn. Tighten the lock nut. Then tighten both clamp bolts to the torque the bolt maker gives for their grade, and record it.

### Step 8: hub onto the plate

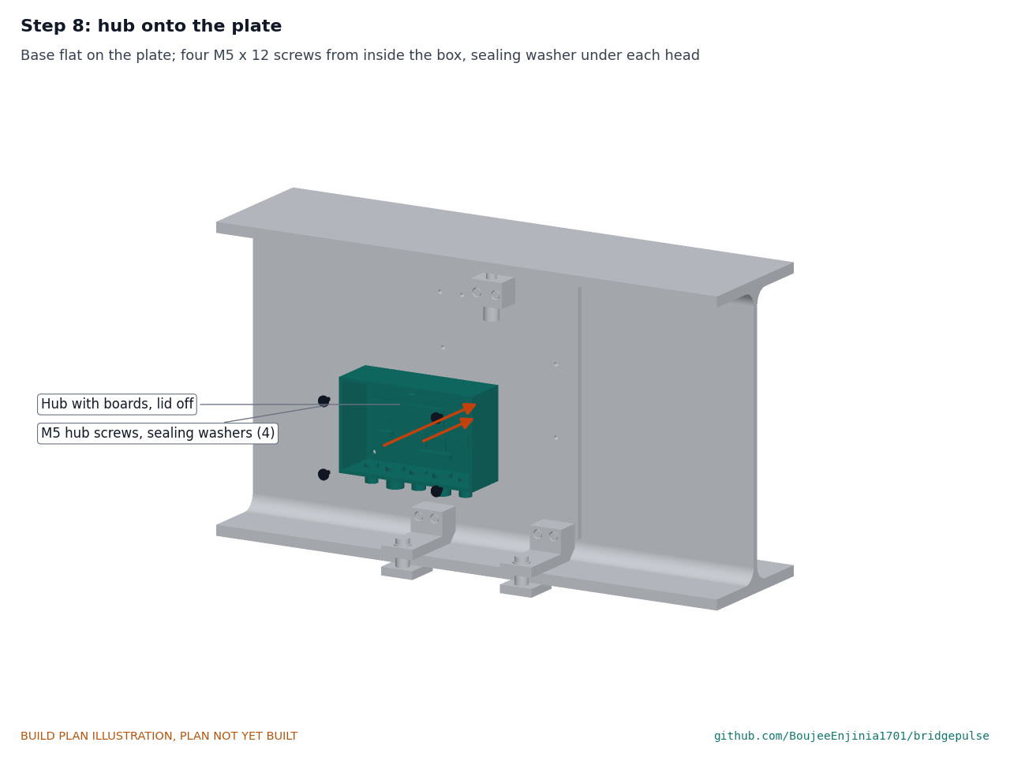
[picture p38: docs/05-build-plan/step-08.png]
Step 8


With the lid off, hold the hub's base flat on the plate, centred, and fit the four M5 x 12 screws from inside the box, a bonded sealing washer under each head. Tighten evenly.

### Step 9: lanyard and its girder clamp

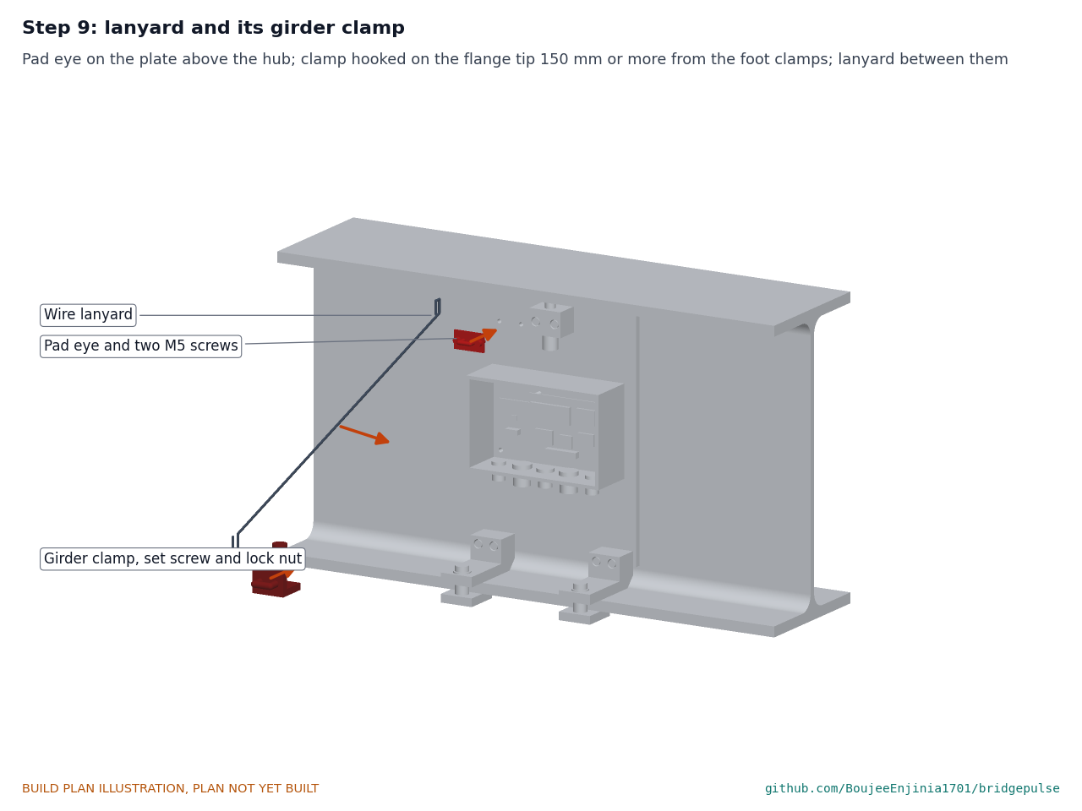
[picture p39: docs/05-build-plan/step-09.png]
Step 9


Screw the pad eye to the plate's front at the top left with its two M5 x 10 screws. Hook the girder clamp over the edge of the bottom flange 150 or more to the left of the left foot block, lower jaw under the flange, and tighten its set screw onto the flange top; lock it with its nut. Fit the lanyard between the pad eye and the clamp's eye as section 3.11, with no more than 25 of slack. **Hold point:** the lanyard is fitted before anyone works below the hub.

### Step 10: strain gauge and dummy coupon

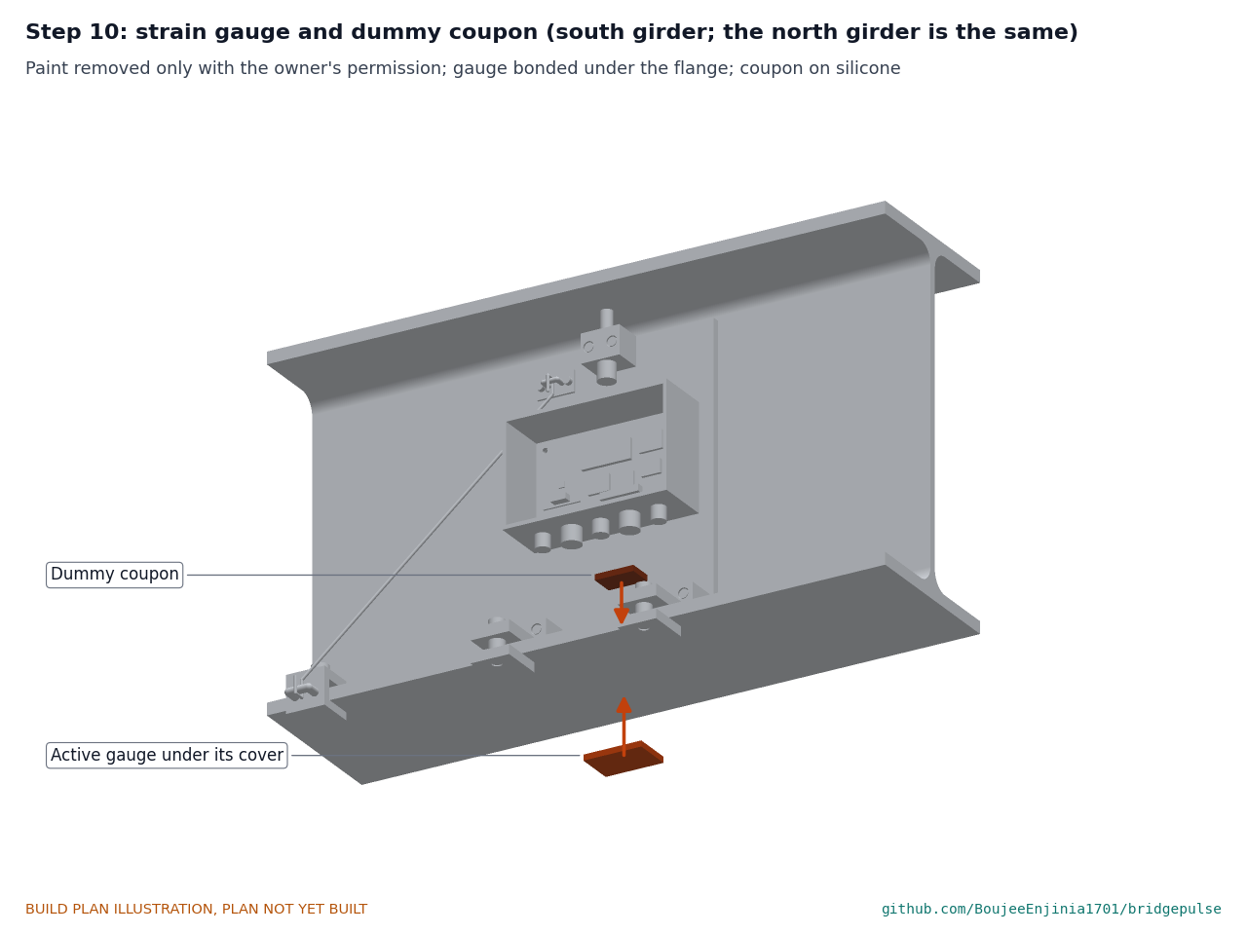
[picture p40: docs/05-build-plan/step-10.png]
Step 10


On each girder offcut: prepare a patch of bare steel under the bottom flange on the girder's centre line, bond the active gauge along the girder, solder its leads, coat it and fit its cover. Set the dummy coupon on silicone on the flange top as section 3.7. On a real bridge, paint is removed only with the owner's permission and after a lead test (section 6, S4).

### Step 11: steel probe, cables and clips

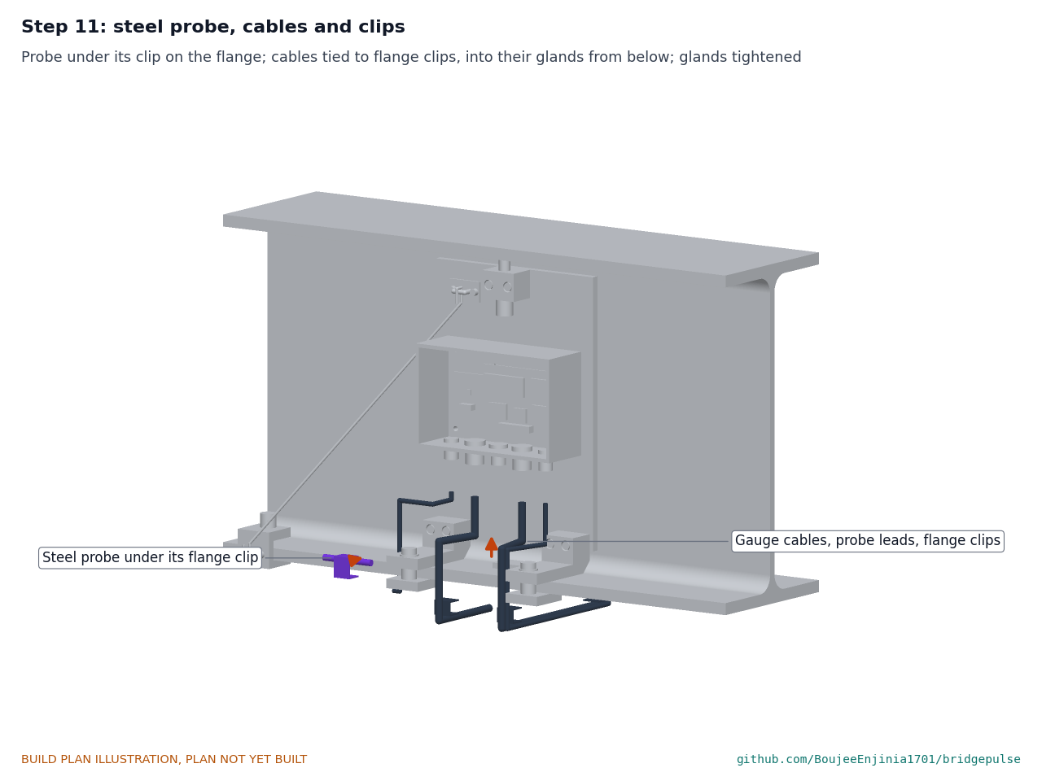
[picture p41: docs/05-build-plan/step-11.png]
Step 11


Push the probe clip onto the flange edge over the steel probe, with thermal paste under the probe. Push the cable clips onto the flange edges, run the near gauge cable and the steel probe lead to their glands, tie them to the clips, and tighten the glands on them. Connect them at the terminal block.

### Step 12: close the lid

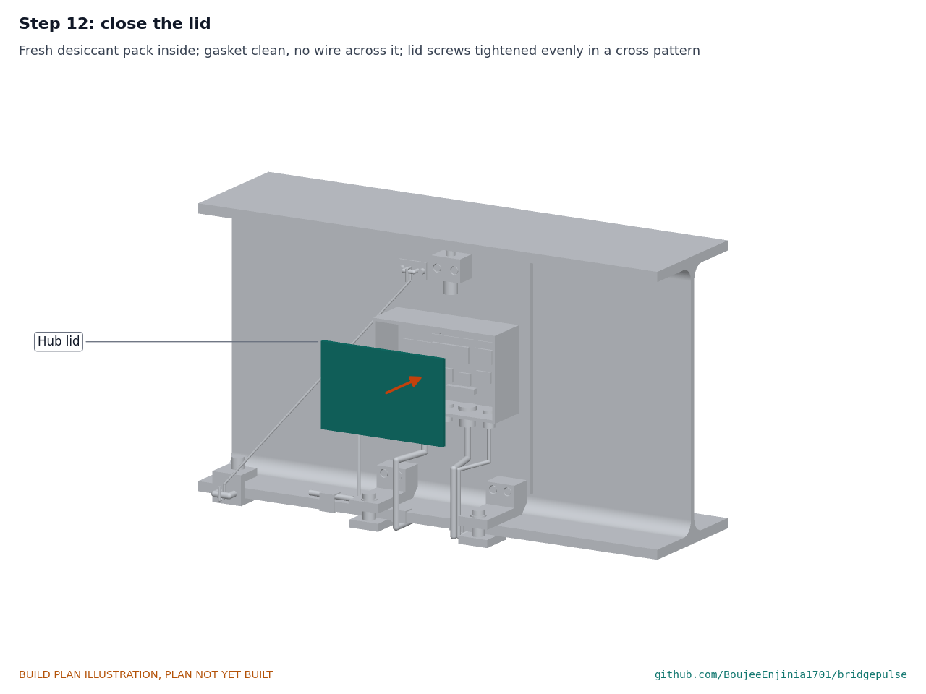
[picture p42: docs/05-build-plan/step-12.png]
Step 12


Put a fresh desiccant pack in the hub. Check the gasket is clean and seated with no wire across it, and tighten the lid screws evenly in a cross pattern.

### Step 13: FieldNode core onto the post

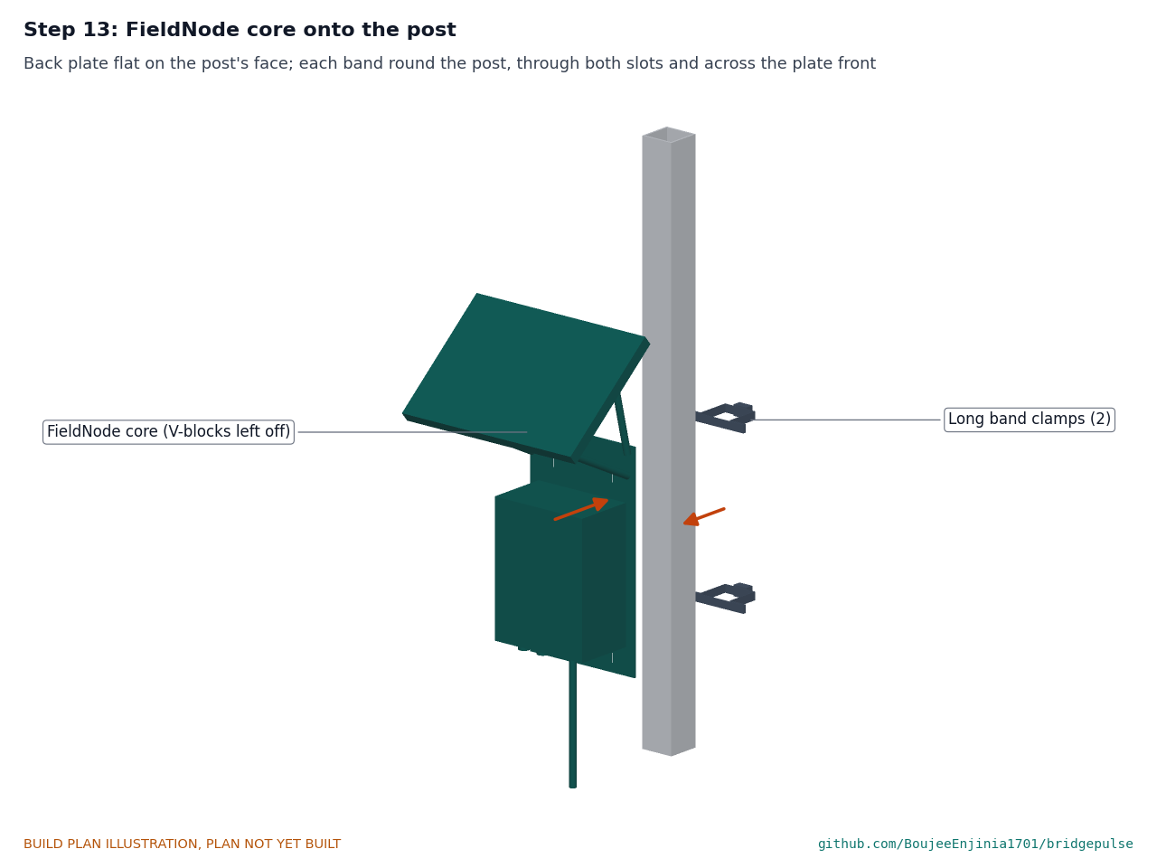
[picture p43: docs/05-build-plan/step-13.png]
Step 13


Hold the FieldNode's back plate flat on the post's outer face, its box base 450 above the deck level. Pass each band round the post, through both slots and across the plate's front, worm-drive housing behind the post, and tighten. **Hold point:** the FieldNode core has passed its own plan's safety stops before its cell is fitted.

### Step 14: cable to the FieldNode, far gauge cable and air probe

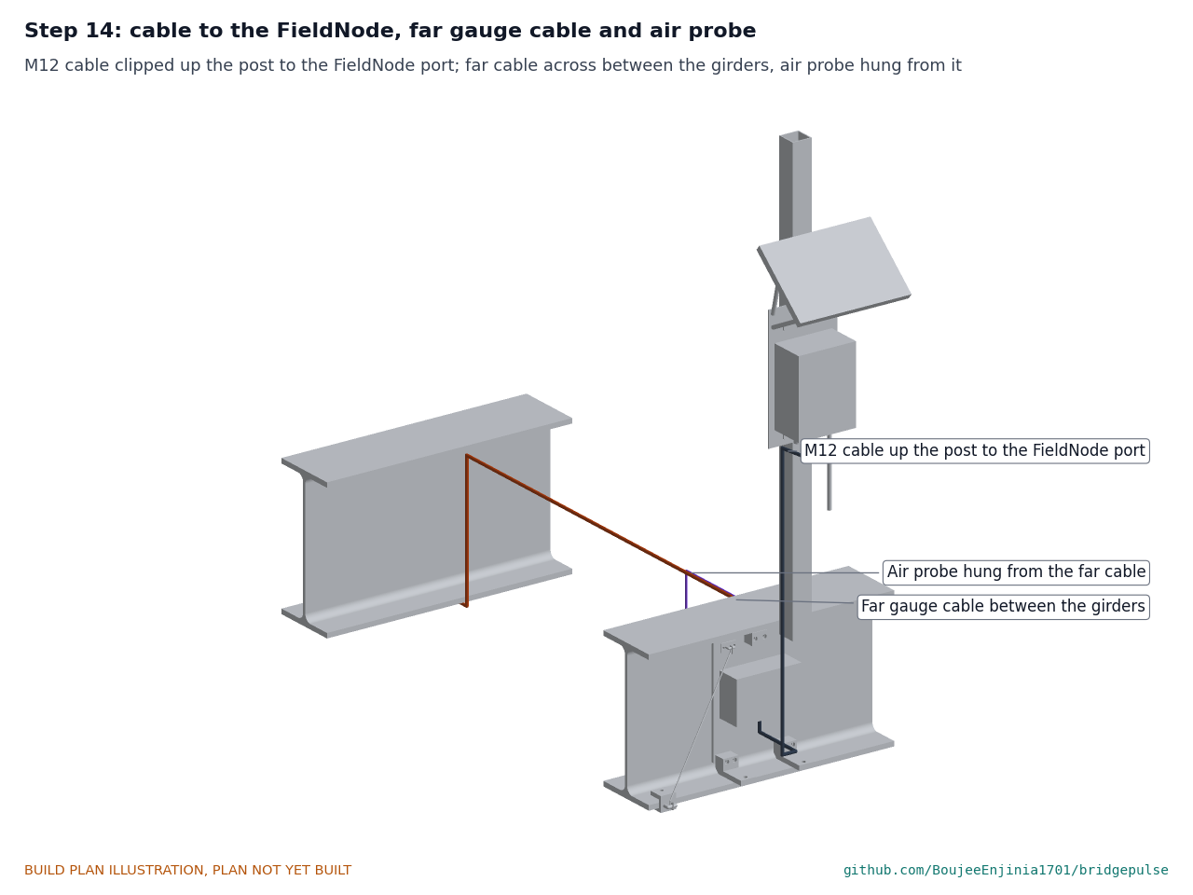
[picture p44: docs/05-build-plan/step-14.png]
Step 14


Plug the M12 cable into the hub's panel connector, run it out past the flange edge and up beside the post, clipped to it, and into the FieldNode's port B. Run the far gauge cable from the second girder's gauge under its flange, across between the girders and under the south flange to the right gauge gland. Hang the air probe on its lead from the far cable's crossing, about 110 below it, tie its lead along the far cable to the right probe gland, and tighten both glands. On the bench, tie the crossing to the bench frame.

## 5. First checks

These are the checks a TRL 4 test report would record; this plan only lists them. Requirement numbers are those of BRP-REQ-001.

*Table 2. First checks.*

| Check | Requirement | How | Pass when |
| --- | --- | --- | --- |
| Penetrations and lid sealed | R10 | Look at each seal under a lamp; gland caps tight on their cables | Every seal evenly squeezed; no gap at the lid gasket |
| Lanyard fitted | Safety | Look along the lanyard; pull the girder clamp by hand | Clamp 150 mm or more from the foot clamps and firm; slack 25 mm or less; nothing rubs on the lanyard |
| Mount is firm | R1, R2 | Push the hub by hand in every direction; tap the hub with a soft mallet while recording the accelerometer | Nothing moves at any joint; the hub's own mode in the record is above 120 Hz |
| Accelerometer noise | R1 | Record 10 minutes on a quiet bench at night | Noise density 25 µg/√Hz or less in the 0.5 to 60 Hz band |
| Strain channels | R4 | Read both channels at rest, then put a known shunt resistor across each active gauge | Steady readings; the shunt step matches its calculated strain within 2 µε |
| Temperature probes | R5 | Ice-point check (section 3.8), then both probes beside a reference in still air | 0 °C within 0.5 °C; within 0.5 °C of the reference |
| Power at the port | R6 | Bench supply at 5 V with a 200 mA limit in place of the FieldNode port; measure current through a 10 minute record | About 19 mA while recording (93 mW); 0 when the rail is off |
| Summary and storage | R7 | Run one record; read the summary bytes on the RS-485 link and the raw file on the card | 36 bytes, or 11 in reduced mode; raw file about 1.9 MB |
| No drilling, fitting time | R8 | Time the plate, hub and clamps going on the offcut | Nothing drilled into the steel; time recorded |
| Depth below the girder | R9 | Straight edge across the underside of the bottom flange; measure the jaws, covers, clips and cables | 15 mm or less everywhere (10 mm by the model) |
| Hub inside the girder outline | R9 | Straight edge down from the flange edge | The closed hub's front face is inside the edge line |

## 6. Safety stops

Stop at each point. Carry on only when everything listed is true.

- **S1. Before the girder offcuts are moved.** Two people to lift each; the offcuts stand on their bottom flanges on a firm floor or low trestles that cannot tip; feet and hands clear.
- **S2. Before any steel from a bridge is ground or sanded.** A lead test of its paint is negative, or the paint is removed by a trained contractor under local abatement rules.
- **S3. Before gauge adhesive, conditioner or potting epoxy is opened.** Safety data sheets read; gloves and eye protection on; the room ventilated; no food nearby.
- **S4. Before paint is removed from a real bridge.** The owner's written permission is in hand, and the lead test of S2 is done on that bridge.
- **S5. Before the hub is first powered.** The bench supply is set to 5 V with a 200 mA current limit; the panel connector's pin assignment is checked against the wiring with a meter, not by wire colour.
- **S6. Before the FieldNode core's cell is fitted.** Its own plan's safety stops are passed (FND-BLD-001).
- **S7. Before the rig is left unattended.** The jack lock nut and both clamp bolts are tight and their torques recorded; the lanyard is fitted; no cable is under strain.
- **S8. Before any installation on a bridge (outside this plan).** The owner's written permission; a trained crew of at least two; fall protection and a rescue plan for work over water; traffic management where needed; the lanyard fitted to its anchor, a second girder clamp rated for 100 kg or more working load on the bottom flange at least 150 mm along the span from the foot clamps, with no more than 25 mm of slack; the FieldNode's bands replaced by stainless banding with one-way crimped buckles. Never work alone.

## 7. Tools, skills and workspace

**Tools.** Hacksaw with a 24 teeth per inch blade, or a bandsaw; bench vice with soft jaws; bench drill or a drill in a stand; drills 3 to 12; step drill to 20; 11 counterbore (or an 11 flat-bottomed drill); countersink; taps M5, M6, M10 and M12 with their tap drills (4.2, 5.0, 8.5, 10.2); flat and half-round files; deburring tool; scriber, engineer's square, 45° square, steel rule and calipers; torque wrench covering about 5 to 40 N·m; spanners and hex keys; soldering iron; ferrule crimper and wire strippers; multimeter; bench power supply with an adjustable current limit; strain gauge installation kit; heat gun; ice bath and a reference thermometer; lead paint test kit; stopwatch.

**Skills.** No certified trade is needed. Basic metalwork (marking out, sawing, drilling, tapping, filing), through-hole soldering and crimping, and strain gauge bonding, which is best practised first on a scrap of steel. All circuits are extra-low voltage: 5 V at the port and 3.3 V inside the hub. The bench supply must be a certified, undamaged unit; no mains wiring is part of this build.

**Workspace.** A bench about 1.5 x 0.6 m with room beside it for the two girder offcuts 1.2 m apart; a metalwork corner kept apart from the electronics; a clean, dust-free, ventilated place for bonding gauges and potting probes.

**Personal protective equipment.** Safety glasses for cutting, drilling, soldering and chemicals; nitrile gloves for adhesives and epoxy; cut-resistant gloves for bar and plate; safety boots for the offcuts; hearing protection when sawing; no gloves near a turning drill.

## 8. Where the numbers come from

- Model and constructability checks: `cad/src/model.py` (`python cad/src/model.py --check`, 91 checks); STEP and STL exports in `cad/step/` and `cad/stl/`.
- Pictures: `cad/src/build_plan_media.py`, using `.kit/build_views.py`; written to `docs/05-build-plan/` and `cad/drawings/BRP-DWG-101` to `BRP-DWG-107`.
- General arrangement: `cad/drawings/BRP-DWG-001.pdf`, Rev P6.
- Calculations: `docs/04-calcs/01-sizing.md` (BRP-CAL-001 v0.6) and `docs/04-calcs/sizing.py`; mass [H1], mount stiffness [H2], retention [H4], lanyard [H4a], [H4c], root fillets [H4b], depth below the girder [H5], FieldNode on the post [H7], [H8], power [F2], [F3], cost [K1].
- Bill of materials: `bom/bom.csv` and `bom/bom-notes.md`.
- Decisions: `docs/decisions/0004-design-for-construction.md` (BRP-DDR-004), with BRP-DDR-001 to BRP-DDR-003; decisions and items to confirm in `docs/06-design-decisions.md` (BRP-DEC-001).
- Requirements: `docs/03-requirements.md` (BRP-REQ-001 v0.8).
- FieldNode core: FieldNode's build plan FND-BLD-001, in the FieldNode repository.

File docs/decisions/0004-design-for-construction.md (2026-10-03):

---
doc_id: BRP-DDR-004
title: BridgePulse design for construction
project: BridgePulse
doc_type: Design decision record
version: "0.4"
status: Draft
date: '2026-10-02'
author: Amish Chadha
license: CERN-OHL-S-2.0
revisions:
- version: "0.1"
  date: '2026-09-30'
  author: Amish Chadha
  change: Changes that make the concept physically buildable, with the reason for each; made under Amish's 2026-09-30 instruction to make the design physically buildable; open for his review
- version: "0.2"
  date: '2026-10-01'
  author: Amish Chadha
  change: Budget treated as a value-engineering target; R12 wording only, no number changed
- version: "0.3"
  date: '2026-10-02'
  author: Amish Chadha
  change: "Accepted by Amish on 2026-10-02, with P12 subject to FieldNode confirming the square-post mount; A2 to A5 decided as recommended"
- version: "0.4"
  date: '2026-10-02'
  author: Amish Chadha
  change: "A2 and A3 carried into the design: pad eye, wire lanyard and girder clamp in the model (91 checks), BOM line 4 and new line 10; the plate's plain lanyard hole replaced by two M5 holes for the pad eye; consequences updated"
---

# 0004: Design for construction

- **Date:** 2026-09-30
- **Status:** accepted. Amish, 2026-10-02: "i approve your recommendations for all 555 open decisions." This covers every change in Tables 1 and 2, with P12 (FieldNode on the square post without V-blocks) subject to the FieldNode project confirming that mount, and the recommendations for A2 to A5 in Table 3, which are now decided as recommended and recorded in the design decisions register (BRP-DEC-001). A1 is a value-engineering saving and stays in the register's value engineering section.

## Context

On 2026-09-30 Amish asked for every repo to get an illustrated prototype build plan, and wrote: "If you are realising that the design cannot be built as per concept - fix the design assumptions to match and be physically feasible as you draw the illustrations." The TRL 3 model of BRP-CAL-001 v0.2 showed what BridgePulse does and how stiff its mount must be, but several parts could not be made, fixed or fitted as drawn. The biggest was that a rolled IPE 360 girder has 18 mm root fillets where its web meets its flanges, and the concept plate stood exactly in that corner.

The changes below keep what the monitor does: the same hub, boards, sensors, positions at midspan, hub height, jack-screw principle, "no drilling" rule and FieldNode link. The hub's front face is still 9 mm inside the flange tip line and nothing hangs more than 10 mm below the soffit (R9, 15 mm). Nothing here changes the pitch or the safety case. Every change is in `cad/src/model.py`, which now builds each component separately and runs 75 constructability checks (`python cad/src/model.py --check`): parts that must touch do touch, with no overlap, and parts that must stay apart keep the stated clearance. All 75 pass. The girders in the model now carry their root fillets.

## Decision

*Table 1. Changes made to the model, the BOM and the calculations.*

| # | Problem in the concept | Change made | Why this way |
| --- | --- | --- | --- |
| P1 | The 8 mm plate stood on the bottom flange with its back on the web. The IPE 360 root fillet (18 mm radius) rises 3 mm at the plate's front face and 18 mm at the web, so the plate would have rested on the fillet edge, not on the flange or flat on the web. The same corner existed under the top flange. | The plate is 22 mm short of each flange: 200 × 290.6 × 8 mm (the clear web height less 44 mm), lying flat on the web between the fillets. It stands on two foot blocks instead of on its own edge. | Keeps the plate on the web and the hub where the concept put it (same height, 9 mm inside the flange tip). 22 mm clears an 18 mm fillet with margin and suits other rolled sections up to about 20 mm. |
| P2 | The two "flange-tip clamps" were a block beside the plate foot with no fixing to the plate, a spacer and a jaw joined by a bolt just outside the flange tip, with nothing outside the tip for the jaw to bear on, so the jaw would tilt about the tip. The bolt's head and nut were not shown and would have hung below the soffit. | Each foot block is one stepped piece sawn from 100 × 40 mm aluminium bar: a tall end screwed to the plate's front face by two M6 cap screws (counterbored), a 12 mm tail on the flange top running 23 mm past the tip, and a 12 mm chamfer over the root fillet. Under the flange, a 40 × 45 × 10 mm steel jaw, tapped M10, reaches 22 mm in from the tip; a steel packer, 0.5 mm shorter than the flange is thick, stands on the jaw outside the tip; an M10 × 35 bolt comes down through the tail and the packer into the jaw and ends 1.2 mm inside it. | A classic flange clamp: tightening pulls the jaw up under the flange and the tail down on top, with both ends of the jaw bearing. Nothing but the 10 mm jaw is below the soffit (was 8 mm), still within R9. The foot blocks carry the jack's reaction into the flange through the M6 screws. |
| P3 | The jack "tab" (40 × 30 × 10 mm) had no fixing to the plate and only 10 mm of thread, and the M12 jack screw sat wholly inside the 22 mm gap under the top flange, with no room for a head, a spanner or a lock. | A jack block, 40 × 30 × 30 mm aluminium, screwed to the top of the plate's front face by two M6 cap screws, tapped M12 the full 30 mm. An M12 × 70 stainless screw goes up through it, head and lock nut below the block, its end bearing on the top flange 26 mm out from the web. | 30 mm of thread in aluminium, a spanner from below, a lock nut to hold the preload, and a bearing point clear of the top root fillet. |
| P4 | The hub enclosure had no fixing to the plate. | Four M5 screws from inside the box, through the base into tapped holes in the plate, each with a bonded sealing washer under its head; their tips stop 2 mm short of the web. The base lies flat on the plate. | The base is clamped to the plate at four points, which couples the accelerometer to the plate as the stiffness calculation assumes, and the box stays sealed. |
| P5 | The signal board stood on two standoffs along its bottom edge only, 6 mm above the gland nuts; the accelerometer board was "bonded and screwed" to the base with nothing between. | Accelerometer board on four 5 mm metal spacers and signal board (92 × 68 mm) on four 14 mm standoffs, all on M3 countersunk screws from outside the base, sealed with thread sealant and covered by the plate once the hub is on. | Four-point fixings for both boards; every board edge 10 mm or more from the M5 screws, so a screwdriver reaches them with the boards fitted, and 12 mm or more above the gland nuts. |
| P6 | The two temperature probe leads had no way into the hub: the concept had two glands, both used by gauge cables. | Five penetrations in one row on the bottom face: M12 gland (steel probe), M16 gland (near gauge), M12 5-pin panel connector, M16 gland (far gauge), M12 gland (air probe), at 60, 30 and 0 mm each side of centre. | Every penetration sealed with a standard part; 9 mm or more between neighbours outside and inside. |
| P7 | The steel probe was a 14 × 15 mm boss stuck to the web with no fixing (the open REVIEW item of 2026-09-26). | The probe is the 7 × 60 mm sheath of BOM line 6, lying on the bottom flange top 6.5 mm in from the tip, held down by a push-on spring-steel flange clip with thermal paste under it. | No drilling and no adhesive on the structure; the flange is the steel the gauges measure, and the clip comes off for the ice-point check. |
| P8 | The air probe hung on a lead that ended in mid-air 13 mm below the top flange. | It hangs on its own lead from the far gauge cable where that cable crosses between the girders, 110 mm below it, and its lead runs beside the far cable to the hub. | Uses a support that is already there and keeps the probe in shade, away from the steel (240 mm). |
| P9 | The dummy coupons sat on the flange top 12.5 mm from the web, over the root fillet, with no fixing; bonded rigidly they would be strained with the girder and stop being dummies. | Each coupon (40 × 25 × 6 mm steel) is centred 35 mm out from the web, clear of the fillet, and set on a bed of neutral-cure silicone. | It shares the flange's temperature but not its strain, which is what a dummy gauge needs. |
| P10 | The gauge cover patches (90 × 45 mm) overlapped the near gauge cable where it starts and the far gauge cable where it runs under the south flange. | Cover patch 60 × 40 mm, which still covers a foil gauge and its solder tabs; the cables run 6 mm or more clear of the covers. | Nothing passes through anything else. |
| P11 | Cables were held by "UV-stable clips" with nothing to clip to, since nothing may be drilled. The cable to the FieldNode ran up inside the handrail post's outline and ended under the antenna rather than a sensor port. | Five push-on spring-steel flange clips (one for the steel probe, four for cables) with cable ties. The M12 cable rises beside the post, 6 mm clear of it, and plugs into the FieldNode's port B. | Standard clips that grip a flange edge without drilling; the cable reaches a real port. |
| P12 | The FieldNode's V-blocks are made for round poles and would bear on the corners of the 50 mm square handrail post (BRP-CAL-001, H8, which asked FieldNode to review it). In this repo's model the FieldNode panel also faced the post, and the bracket arms started in mid-air beside the back plate. | On the square post the V-blocks are left off: the back plate bears flat on the post's face, and two band clamps one size longer (band about 300 to 330 mm) go round the post, through the plate's slots and across its front. The panel now faces away from the post, as FieldNode's own model has it, and the bracket envelope starts on the back plate. | The same approach FieldNode adopted for wall mounting (FND-DDR-003, A2): no new part, and the flat face is a better seat than a V on a square post. The FieldNode core itself is unchanged and is built to its own plan, FND-BLD-001. |

*Table 2. Knock-on changes.*

| Item | Change | Reason |
| --- | --- | --- |
| Mass | 3.21 kg on the girder (was 3.34 kg): hub 0.99 kg, plate 1.25 kg, foot blocks, jaws, packers, jack and fixings 0.97 kg (BRP-CAL-001 v0.3, H1). | Shorter plate; the clamp parts are now counted in their own materials; two more glands. |
| Mount stiffness | Out-of-plane mode 135 to 271 Hz (was 126 to 253 Hz), still above the 120 Hz target (H2). | The plate between its supports is shorter. |
| Cost | Line 1 $22.00 (+$2.00, two probe glands), line 4 $40.00 (+$2.00, foot blocks, jaws, packers, jack block and screws). BridgePulse-specific parts $252.00 against the $250 value-engineering target (`budget_usd`): **over the target by $2.00** (K1). The target is unchanged; see Table 3, A1. | Parts added for construction. |
| Depth below the soffit | 10 mm worst (jaws and cables), against 15 mm; R9 stays met on paper (H5). | Jaw is 10 mm thick so the M10 thread engages fully. |
| Drawings | BRP-DWG-001 Rev P5; making sketches BRP-DWG-101 to 107 added. | Follows the model. |
| Documents | BRP-CAL-001 v0.3, BRP-REQ-001 v0.5, BRP-PRC-001 v0.5, `bom/bom.csv`, `bom/bom-notes.md`. Requirement count: 1 over the value-engineering target (R12), 2 at risk (R2, R10), 3 not verifiable at TRL 3, 4 met on paper, 3 met by design. | Follows the model. |
| Appearance model | `cad/src/product_model.py` and the photoreal renders still show the concept plate, tab, clamps, probe boss and glands; they need updating on Amish's Mac, where Blender is. | Renders are made there. |

*Table 3. Proposed; A2 to A5 accepted by Amish as recommended on 2026-10-02 (A5 with P12 subject to FieldNode). A1 stays a value-engineering saving.*

| # | Question | Options | Recommendation |
| --- | --- | --- | --- |
| A1 | R12: the estimated cost is $2.00 over the $250 value-engineering target on indicative prices. | Savings worth trying: (a) take the first saving already named in BRP-DDR-002, a consumer high-endurance microSD card rated -25 to +85 °C, in place of the industrial card; (b) a cheaper accelerometer breakout that still meets R1; (c) leave it until quotes at TRL 4. | (a), if the chosen card's datasheet covers -25 to +85 °C, since it keeps R10 and saves about $10. |
| A2 | The lanyard (the safety case's second retention path) has a hole in the plate but no anchor on the bridge: nothing may be drilled, the deck sits on the top flange and a loop cannot pass round a flange. | (a) a second, independent bought beam clamp on the bottom flange at least 150 mm along the span, with the lanyard to it; (b) to the handrail post; (c) to a cross frame or diaphragm where the bridge has one. | (a): independent of the foot clamps and the same on every bridge; it would add a bought clamp to BOM line 4. Accepted 2026-10-02: a load-rated girder clamp at least 150 mm along the span from the foot clamps, with a stainless wire lanyard. |
| A3 | R9 asks for tamper-resistant fasteners on the post-mounted FieldNode; worm-drive band clamps undo with a screwdriver. | (a) stainless banding with a one-way crimped buckle for installations, worm-drive bands on the bench; (b) worm-drive bands with tamper-resistant screws; (c) a lockable cover. | (a). FieldNode should decide it for all its post installations. Accepted 2026-10-02; FieldNode is asked to adopt the same rule. |
| A4 | Where the far gauge cable crosses between the girders it needs support; the example bridge has no cross member in the model, and fixings into the deck count as drilling. | (a) run it along the nearest cross frame or diaphragm; (b) a tensioned 3 mm stainless catenary wire between two flange clamps; (c) decide at the site survey with the owner. | (c), preferring (a) wherever the bridge has a cross member near midspan, otherwise (b). Depends on the first host bridge (BRP-DDR-001, O2). Accepted 2026-10-02. |
| A5 | Accept the changes of Table 1. | (a) accept; (b) accept with changes. | (a), with P12 subject to the FieldNode project confirming the square-post mount. Accepted 2026-10-02. |

## Consequences

- `design_state: constructable` in `project.yaml`. The build plan BRP-BLD-001 shows every component and step in pictures generated from the model (`cad/src/build_plan_media.py`); the open items above are in the design decisions register BRP-DEC-001, not in the plan.
- R12 moves from at risk to over the value-engineering target ($2.00 over at v0.1; $25.00 over once the lanyard anchor and installation banding of A2 and A3 were priced on 2026-10-02); every other requirement keeps its status.
- The appearance model `cad/src/product_model.py` was rebuilt on 2026-10-02 from the constructable model, with the lanyard, and its render scenes exported; the photoreal renders (`media/render-*.png`), `media/card.png` and `media/social-preview.png` are to be redone on Amish's Mac.
- The FieldNode project is asked to confirm the square-post interface (no V-blocks, longer bands) and its own current mass and cost; nothing in the FieldNode repo is changed here.
- With A2 accepted, the lanyard goes to a second, independent load-rated girder clamp on the bottom flange. Carried out on 2026-10-02: a stainless pad eye on two M5 screws replaces the plate's plain 6.5 mm lanyard hole, through which a wire could not pass with the plate flat on the web; a 3 mm stainless wire lanyard runs from it to a bought single-flange girder clamp on the south bottom flange tip, 159 mm along the span from the nearer foot clamp; all are in the model (91 constructability checks), BOM line 4 ($59.00), BRP-CAL-001 v0.6 (H1, H4a, H4c, K) and the build plan pictures. With A3 accepted, installed units use one-way crimped stainless banding (BOM line 10, $4.00) and the bench unit worm-drive bands. With A4 accepted, the far cable's support is chosen at the site survey.
- TRL stays at 3; TRL 4 remains on hold. Nothing in this record authorizes building, testing or buying.

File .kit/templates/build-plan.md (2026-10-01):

---
doc_id: PRJ-BLD-001
title: Project prototype build plan
project: Project name
doc_type: Build plan
version: "0.1"
status: Draft
date: YYYY-MM-DD
author: Amish Chadha
license: CERN-OHL-S-2.0
revisions:
  - version: "0.1"
    date: YYYY-MM-DD
    author: Amish Chadha
    change: First build plan; design made constructable
---

# Project prototype build plan

**Plan, not yet built.** How to build the first proof-of-concept prototype, component by component. Building and testing to it is TRL 4 work. Decisions still to be made are kept in the design decisions register (`docs/06-design-decisions.md`), not here.

## 1. What you are building

Every component, pulled apart and numbered in build order

One short paragraph: what the prototype is, how many components, which are made and which are bought, and the main ways they are made.

## 2. What changed to make it buildable

| Component | The concept had | The buildable design has | Why |
| --- | --- | --- | --- |

## 3. Making the components

### 3.1 Component name

Making sketch

**What it is and what it is made from.**

**How to make it.**

1. Mark out ...
2. Cut ...

**How it fits the parts next to it.**

Close-up of the joint

**Check before moving on.**

## 4. Putting it together

### Step 1: ...

Step 1

## 5. First checks

| Check | Requirement | How | Pass when |
| --- | --- | --- | --- |

## 6. Safety stops

## 7. Tools, skills and workspace

## 8. Where the numbers come from

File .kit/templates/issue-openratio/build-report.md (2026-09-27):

---
name: Build report
about: Tell us what happened when you built, printed or tested part of this design
title: "Build report: "
labels: build-report
---

This is a research and educational prototype, not a medical device. It is a TRL 3 concept and is not released for fabrication. If you build any part of it, you do so at your own risk. Reports help everyone.

**What you built** (part, sub-assembly or test)

**Materials, tools and settings**

**What worked**

**What did not work, with photos or measurements if you have them**

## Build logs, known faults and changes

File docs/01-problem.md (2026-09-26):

---
doc_id: BRP-PRB-001
title: BridgePulse problem statement
project: BridgePulse
doc_type: Problem statement
version: "0.4"
status: Draft
date: '2026-09-25'
author: Amish Chadha
license: CERN-OHL-S-2.0
revisions:
- version: "0.1"
  date: '2026-09-25'
  author: Amish Chadha
  change: Initial scaffold
- version: "0.2"
  date: '2026-09-25'
  author: Amish Chadha
  change: Problem, users, context, constraints, prior work and open questions for TRL 2
- version: "0.3"
  date: '2026-09-25'
  author: Amish Chadha
  change: Budget constraint per BRP-DDR-001 D1; example bridge frequency and cost from BRP-CAL-001; open question on people's mass added
- version: "0.4"
  date: '2026-09-25'
  author: Amish Chadha
  change: Recommendations accepted by Amish (DDR-002); budget decision status, cost and the people's-mass question updated
---

# BridgePulse problem statement

Small bridges and footbridges are inspected by eye at long intervals, and deterioration between visits is found late or not at all. Owners of these structures (towns, counties, park services and rural access programs) rarely have the budget for commercial structural health monitoring, so there is no record of how a bridge behaves between one inspection and the next.

## The problem in numbers

- In the United States, 41,685 of 624,193 bridges (6.7 %) were rated in poor condition in 2025 ([FHWA, National Bridge Inventory](https://www.fhwa.dot.gov/bridge/nbi/no10/condition25.cfm)). The routine inspection interval under the National Bridge Inspection Standards is up to 24 months, and some bridges may go 48 or, under a risk-based method, 72 months between routine inspections ([23 CFR 650.311](https://www.ecfr.gov/current/title-23/chapter-I/subchapter-G/part-650/subpart-C/section-650.311)).
- In Great Britain, 2,928 of 73,208 council-maintained road bridges (4 %) were substandard in 2023, with an estimated maintenance backlog of £6.8 billion ([RAC Foundation, 2024](https://www.racfoundation.org/media-centre/changing-weather-patterns-worrying-bridge-engineer)).
- In Japan, about 37 % of roughly 730,000 road bridges were 50 years old or more in March 2023, rising to about 54 % by 2030 ([MLIT](https://www.mlit.go.jp/sogoseisaku/maintenance/02research/02_01.html)).
- Inspection findings only help if they lead to action. The Fern Hollow Bridge in Pittsburgh collapsed on January 28, 2022; the NTSB found that corrosion and section loss caused the failure and that the city had failed to act on repeated maintenance recommendations in inspection reports ([NTSB, HWY22MH003](https://www.ntsb.gov/investigations/Pages/HWY22MH003.aspx)).

## Users and context

| User | Need |
| --- | --- |
| Bridge owner's engineer (town, county, park service, rural roads agency) | A low-cost signal, between inspections, that a particular bridge has changed and should be looked at sooner |
| Bridge inspector | A trend record (natural frequency, strain range, temperature) to take on site and compare with what is seen |
| Rural access and trail bridge programs | A way to check a sample of footbridges they built years ago without a site visit to each one |
| Researchers and students | An open, documented platform for vibration-based structural health monitoring on real structures |
| Residents and bridge users | Confidence that the bridge they cross is being watched, through CityTwin, without the monitor collecting anything about them |

**Target structures.** Footbridges and short-span road bridges with spans of roughly 5 to 30 m, in steel, concrete or timber, where the first vertical modes are expected to lie between about 1 and 50 Hz (estimate, to confirm per bridge). The worked example in the media is a 7 m steel footbridge on two I-girders; its first vertical mode is 23.9 Hz by a simple beam calculation, and one walker at midspan lowers it by about 6 % (BRP-CAL-001).

**Operating environment.** Outdoors, under or beside a deck over water or a road: rain, splash, condensation, freeze and thaw, UV on the solar panel, birds and vandalism. No mains power on site. Radio coverage by LoRaWAN, either a public network or the lab's TwinKit gateway.

## Constraints

- Garage-buildable prototype. The project budget in `project.yaml` is $250 USD for the BridgePulse-specific parts, with the FieldNode core costed in its own repo (BRP-DDR-001, D1; decided by Amish, 2026-09-25: go with recommendation). The BridgePulse-specific parts cost $248 and the complete monitor $374 (BRP-CAL-001 v0.2).
- Built on the lab's FieldNode core for power, enclosure and radio; readings go to TwinKit and CityTwin.
- No drilling or welding of the structure. Strain gauges need a small area of paint removed and recoated, which needs the owner's permission.
- Installation from below or beside the deck without closing a road bridge to traffic where possible; work at height and over water follows the owner's rules.
- The monitor supports inspection by qualified engineers; it never replaces it and never issues a safety rating.
- Only structural readings leave the device. There are no cameras or microphones.

## Prior work

- **Vibration-based damage detection.** Loss of stiffness lowers natural frequencies, but normal changes from temperature, humidity and boundary conditions can be as large as those from damage. The one-year monitoring of the Z24 bridge in Switzerland, before it was damaged on purpose, is the reference case: black-box models of eigenfrequency against temperature were fitted to healthy data, and new data outside their confidence bands pointed to a cause other than temperature ([Peeters and De Roeck, 2001](https://doi.org/10.1002/1096-9845%28200102%2930:2%3C149::AID-EQE1%3E3.0.CO;2-Z)). BridgePulse follows the same approach at low cost.
- **Low-noise MEMS accelerometers.** Parts such as the ADXL355 (22.5 µg/√Hz noise density, 200 µA in measurement mode) make ambient vibration measurement affordable ([Analog Devices](https://www.analog.com/en/products/adxl355.html)).
- **Commercial monitoring systems.** Wireless structural monitoring systems for bridges are sold commercially, but they are priced and supported for large asset owners and are closed. There is no widely used open design for small bridges that we have found; this needs a proper review at TRL 3.
- **Why small footbridges matter.** In rural Nicaragua, seasonal floods cut household labor market income by about 18 % where there was no bridge, and new footbridges removed that loss ([Brooks and Donovan, 2020](https://doi.org/10.3982/ECTA15828)). Keeping such bridges in service matters as much as building them.

## Out of scope

- Load rating, safety rating or any statement that a bridge is safe.
- Long-span, cable-supported or major highway bridges, which need engineered monitoring systems.
- Scour, bearing and foundation monitoring (possible later add-ons, for example with FloodGauge on the same stream).
- Cameras, audio, vehicle or pedestrian identification.

## Open questions

- [ ] Which owners would host a first installation, and on what kind of bridge?
- [ ] Is ambient excitation (wind, footfall, traffic) enough to identify the first modes of a quiet footbridge with a MEMS accelerometer?
- [ ] How large are temperature-driven frequency changes on small bridges, especially with asphalt surfacing or frozen bearings, compared with a 1 % damage signal?
- [ ] On light footbridges, the mass of the people crossing changes the frequency by more than the 1 % change the monitor must detect (BRP-CAL-001). BRP-DDR-002 adopts load gating backed by a load regression; it meets the target in simulation (BRP-CAL-001 v0.2, B), but does it hold on recorded footfall?
- [ ] Who receives an alert, and what is the agreed action when one is raised?
- [ ] Is paint removal for strain gauges acceptable to owners, and is old paint likely to contain lead?

## User research and co-design

This design is for communities the author is not part of, so requirements come from the people who will use it.

- [ ] Identify a local partner organization (Helpful Engineering network, NGO or university)
- [ ] Run co-design sessions with intended users; record who, where and what was learned
- [ ] Validate load, distance, terrain and cost assumptions in the field
- [ ] Revise requirements (REQ) from findings before freezing the design

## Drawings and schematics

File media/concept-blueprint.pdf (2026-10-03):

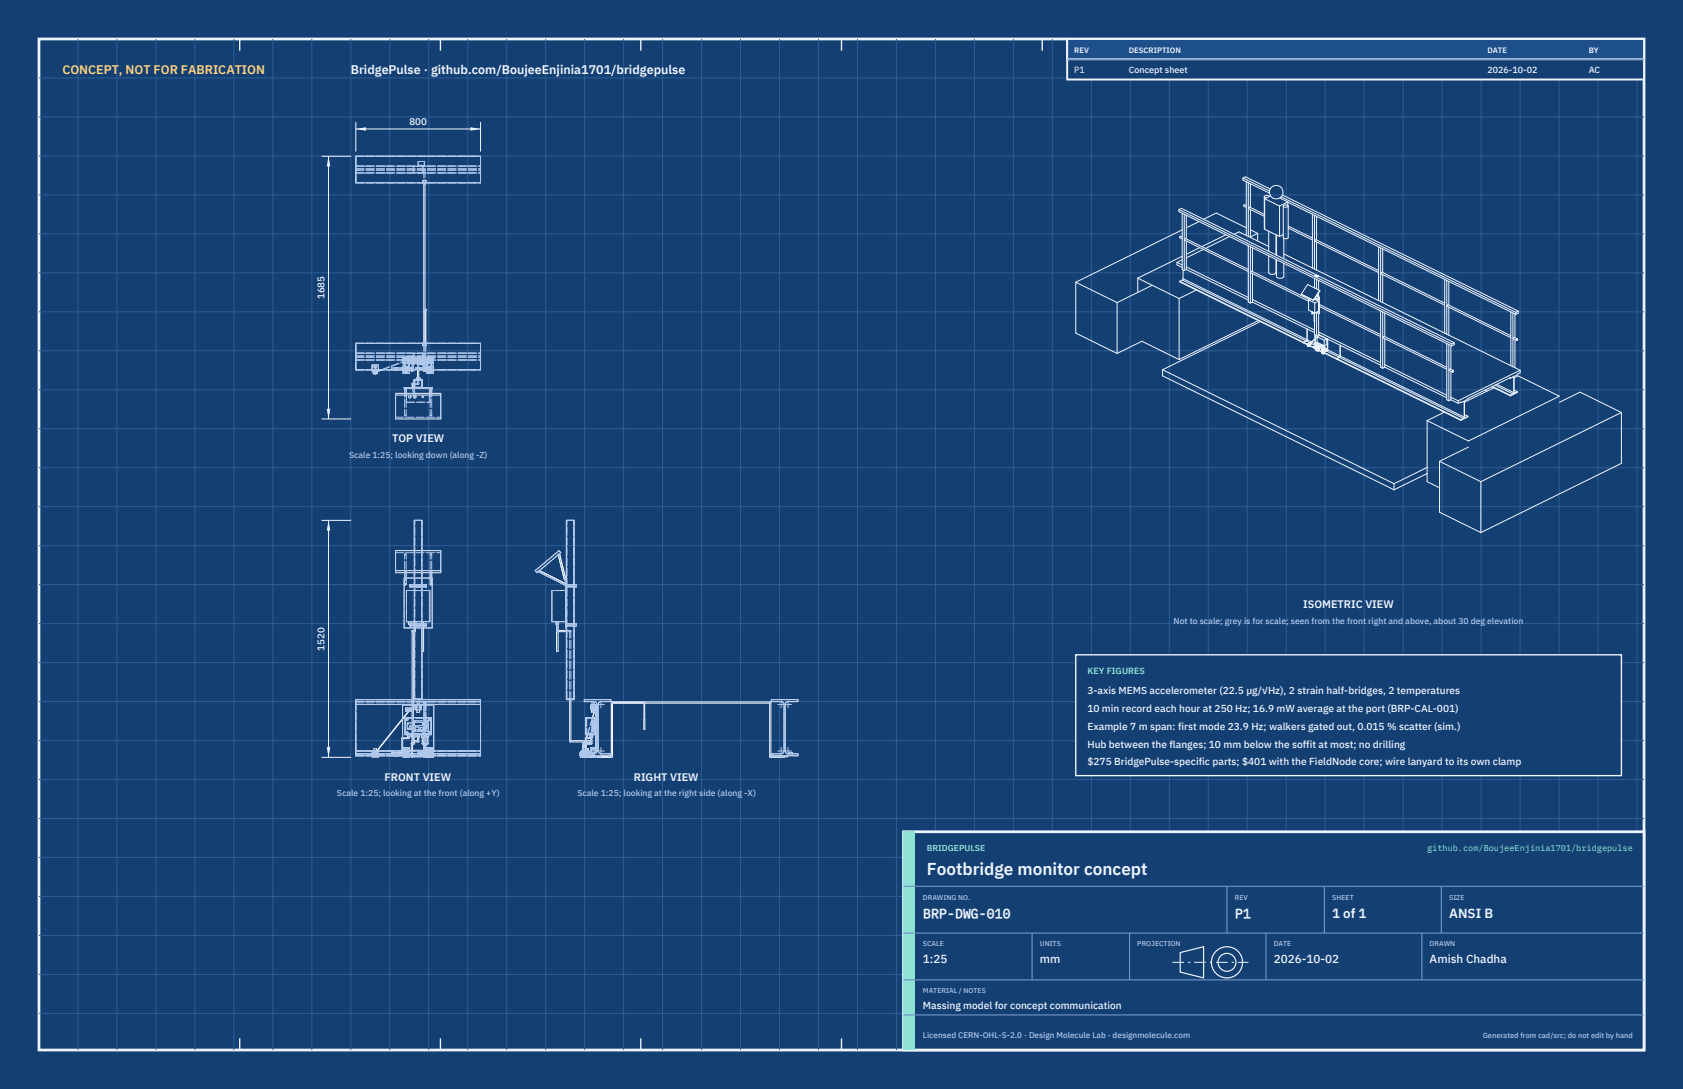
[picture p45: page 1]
CONCEPT, NOT FOR FABRICATION; BridgePulse · github.com/BoujeeEnjinia1701/bridgepulse; FRONT VIEW; TOP VIEW; RIGHT VIEW; ISOMETRIC VIEW; REV; DESCRIPTION; DATE; Concept sheet; BRIDGEPULSE; github.com/BoujeeEnjinia1701/bridgepulse; DRAWING NO. BRP-DWG-010; REV P1; SHEET 1 of 1; SIZE ANSI B; SCALE 1:25; UNITS mm; PROJECTION; DRAWN Amish Chadha; Licensed CERN-OHL-S-2.0 · Design Molecule Lab · designmolecule.com; Generated from cad/src; do not edit by hand

Scale 1:25; looking down (along -Z)

Not to scale; grey is for scale; seen from the front right and above, about 30 deg elevation

KEY FIGURES
3-axis MEMS accelerometer (22.5 µg/√Hz), 2 strain half-bridges, 2 temperatures
10 min record each hour at 250 Hz; 16.9 mW average at the port (BRP-CAL-001)
Example 7 m span: first mode 23.9 Hz; walkers gated out, 0.015 % scatter (sim.)
Hub between the flanges; 10 mm below the soffit at most; no drilling
$275 BridgePulse-specific parts; $401 with the FieldNode core; wire lanyard to its own clamp

Scale 1:25; looking at the front (along +Y)

Scale 1:25; looking at the right side (along -X)

Footbridge monitor concept

MATERIAL / NOTES
Massing model for concept communication

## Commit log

2026-09-25 Initial scaffold: standard open hardware layout, CERN-OHL-S v2 + MIT licenses
    Claude-Session: https://claude.ai/code/session_01XuhhSU4W6fYhgCfURbrkut
    [bom.csv]
2026-09-26 Populate to TRL 2: problem, requirements, precis, concept media, BOM and README use cases
    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
    [bom.csv]
2026-09-26 Advance to TRL 3: DDR-001, CAL-001 sizing, parametric model with STEP/STL, GA drawing, priced BOM; TRL 4 on hold
    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
    [bom.csv, bridgepulse-assembly.step, bridgepulse-assembly.stl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]
2026-09-26 Accept all recommendations (DDR-002), switch footer to designmolecule.com, add README write-up with new inspiration point
    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
    [bom.csv, bridgepulse-assembly.step, bridgepulse-installed.step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]
2026-09-27 Product appearance model and photoreal renders
    Adds cad/src/product_model.py (appearance model for renders only, all main
    dimensions from model.py) and Blender renders in media/render-*.png,
    captioned with the project, repository and viewing direction. README leads
    with the product render; trl stays 3.
    Also applies Amish's 2026-09-27 decision: far gauge cable routed clear of the bottom flanges (BRP-DDR-003).
    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
    [bridgepulse-assembly.step, bridgepulse-assembly.stl, bridgepulse-installed.step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]
2026-10-01 Image quality pass: legible exploded views, flow diagrams and drawing sheets
    Kit 1.6.1 image layout: the parts list sits in its own column, number bubbles sit on visible parts and never overlap, small parts get a leader, pictures are cropped to the subject, flow labels keep numbers with their units, and sheet captions and the revision table no longer overprint. Concept images, blueprint and general arrangement sheet regenerated; repo-specific labels moved clear of other text and lines.
2026-10-01 Kit 1.7.0: constructable design, illustrated build plan and design decisions register
    The design is now constructable: every part can be made and fits its neighbours, with each change recorded in a Design for construction decision record (made under Amish's 2026-09-30 instruction; ope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
    [bom.csv, bridgepulse-assembly.step, bridgepulse-assembly.stl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]
2026-10-01 Budget treated as a value-engineering target
    Amish, 2026-10-01: the budget is a hypothetical control target that keeps the design on a value-engineering lens, not a spending limit. Documents now state the value-engineering target and the estima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
2026-10-02 Record Amish's approval of the open-decision recommendations
    Amish approved the recommendation on every open decision in the design decisions register ("i approve your recommendations for all 555 open decisions.", 2026-10-02). Each decision is moved to Decisio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
2026-10-03 Carry approved follow-ups into the design and redo photoreal renders
    Amish approved the follow-up actions from the open-decision sign-off ("APPROVED CHANGES, COMPLETE THESE", 2026-10-02), the design-for-construction change tables in ten repos, the last wave's open dec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
    [bom.csv, bridgepulse-assembly.step, bridgepulse-assembly.stl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]

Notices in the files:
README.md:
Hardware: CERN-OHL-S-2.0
